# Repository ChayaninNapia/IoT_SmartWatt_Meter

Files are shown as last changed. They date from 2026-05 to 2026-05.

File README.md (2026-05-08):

# IoT Smart Watt Meter

An ESP32-based bicycle watt meter project for FRA503. The system combines an
MPU6050 IMU, HX711 strain-gauge force sensing, an SH1106 OLED, four physical
buttons, a passive buzzer, BLE telemetry, and a Flutter mobile app for ride
display, GPS, recording, history, and cloud sync.

## Project Status

Current integration focus:

- Full-system ESP32 firmware for bench and field testing.
- BLE telemetry between ESP32 and Flutter.
- Gyroscope-based crank cadence estimation.
- HX711 raw capture and calibration workflow.
- Flutter app screens for live power, device connection, map, history, and ride
  detail.

Hardware evidence has confirmed the OLED, buzzer, four active-high buttons,
MPU6050 raw/gyro readings, and several IMU/OLED/buzzer/button integration
tests. HX711 calibration is still the key remaining measurement step before
force and wattage should be treated as final.

## Repository Layout

```text
electrical/
  unit_test/                         Single-component ESP32 test sketches
  integration_test/
    smart_watt_meter_full_system/    Main full-system ESP32 firmware
  experiment/
    hx711_calibration/               HX711 capture logger and ESP32 collector
    imu_cadence_validation/          Gyro cadence validation firmware

software/
  smart_watt_meter/                  Flutter mobile app
  firmware/smart_watt_meter_mock/    Mock telemetry firmware
  docs/                              Software/report documents
  ui design/                         UI mockups and design references

data/
  hx711_calibration/                 Captured calibration CSV data

data_analysis/                       Analysis scripts and notebooks
diagrams/                            System and wiring diagrams
images/                              Project images
proposal/, report/, draft/           Report and proposal materials
research_papers/                     Reference papers
```

## Hardware Summary

Target board:

```text
ESP32 NodeMCU-32S / ESP-32S Kit
Arduino board target: ESP32 Dev Module
CLI FQBN: esp32:esp32:esp32
```

Current GPIO map:

| Function | GPIO | Notes |
| --- | ---: | --- |
| HX711 DOUT | 32 | Digital input |
| HX711 SCK | 33 | Digital output |
| I2C SDA | 21 | Shared by OLED and MPU6050 |
| I2C SCL | 22 | Shared by OLED and MPU6050 |
| Button 1 | 25 | Active-high, `INPUT_PULLDOWN` |
| Button 2 | 26 | Active-high, `INPUT_PULLDOWN` |
| Button 3 | 27 | Active-high, `INPUT_PULLDOWN` |
| Button 4 | 14 | Active-high, `INPUT_PULLDOWN` |
| Passive buzzer | 13 | Tone/PWM output |

Button 5 / GPIO16 is not part of the current system.

OLED:

- 1.3 inch I2C OLED
- SH1106-compatible
- Address `0x3C`
- Driver: `Adafruit_SH110X` / `Adafruit_SH1106G`

## Main ESP32 Firmware

Full-system firmware:

```text
electrical/integration_test/smart_watt_meter_full_system/smart_watt_meter_full_system.ino
```

It combines:

- SH1106 OLED screen UI.
- MPU6050 cadence estimation.
- HX711 raw/tare/force path.
- Four active-high buttons.
- Passive buzzer feedback.
- BLE telemetry for the Flutter app.

BLE configuration:

```text
Device name: ESP32_PowerMeter_01
Service UUID: 12345678-1234-1234-1234-123456789012
Telemetry notify UUID: 12345678-1234-1234-1234-123456789013
App status / command write UUID: 12345678-1234-1234-1234-123456789014
```

Example telemetry packet:

```json
{"v":1,"type":"telemetry","seq":128,"tMs":128420,"powerW":245.3,"cadenceRpm":82.1,"forceN":34.20,"torqueNm":5.81,"omegaRadS":8.600,"hxRaw":29120,"hxTared":true,"imuOk":true,"hxOk":true,"calOk":true}
```

Example app status write:

```json
{"type":"appStatus","gpsOk":true,"recording":true}
```

Example app commands:

```json
{"type":"command","cmd":"tare"}
{"type":"command","cmd":"gyroBias"}
{"type":"command","cmd":"axisCal"}
```

## Arduino Compile Checks

The Arduino IDE bundled CLI is used because `arduino-cli` is not expected to be
on the system `PATH`.

CLI path on the development machine:

```powershell
& 'C:\Users\Acer\AppData\Local\Programs\Arduino IDE\resources\app\lib\backend\resources\arduino-cli.exe' version
```

Compile the full-system firmware:

```powershell
& 'C:\Users\Acer\AppData\Local\Programs\Arduino IDE\resources\app\lib\backend\resources\arduino-cli.exe' compile --fqbn esp32:esp32:esp32 .\electrical\integration_test\smart_watt_meter_full_system
```

Compile the IMU cadence experiment:

```powershell
& 'C:\Users\Acer\AppData\Local\Programs\Arduino IDE\resources\app\lib\backend\resources\arduino-cli.exe' compile --fqbn esp32:esp32:esp32 .\electrical\experiment\imu_cadence_validation
```

Compile the HX711 trial collector:

```powershell
& 'C:\Users\Acer\AppData\Local\Programs\Arduino IDE\resources\app\lib\backend\resources\arduino-cli.exe' compile --fqbn esp32:esp32:esp32 .\electrical\experiment\hx711_calibration\esp32_hx711_trial_collector
```

Compile success only proves the firmware builds. Hardware tests must still be
verified with serial logs, OLED output, buzzer response, photos, videos, or
recorded experiment data.

## HX711 Calibration Workflow

Calibration tools:

```text
electrical/experiment/hx711_calibration/
```

Important files:

```text
hx711_calibration_logger.py
esp32_hx711_trial_collector/esp32_hx711_trial_collector.ino
```

Install Python dependencies:

```powershell
pip install pyserial matplotlib
```

Run the logger:

```powershell
python electrical\experiment\hx711_calibration\hx711_calibration_logger.py
```

The workflow captures 100 valid HX711 samples per trial into:

```text
data/hx711_calibration/<loading-or-unloading>/m<mass>/trial<trial>/hx711_capture.csv
```

Current calibration range is `0-4 kg`. Use loading and unloading trials to
check scale, residual error, and hysteresis before treating force in newtons as
calibrated.

## IMU Cadence Validation

Cadence validation sketch:

```text
electrical/experiment/imu_cadence_validation/imu_cadence_validation.ino
```

The method:

1. Measure gyro bias while stationary.
2. Subtract bias from gyro readings.
3. Estimate the crank rotation axis in the IMU frame.
4. Project the gyro vector onto that axis.
5. Convert angular speed to RPM.
6. Compare IMU RPM against video-derived reference RPM.

The full-system firmware starts with this default crank unit vector unless the
axis calibration is refreshed:

```text
ux = -0.074
uy =  0.995
uz =  0.065
```

## Flutter App

App folder:

```text
software/smart_watt_meter/
```

Key dependencies:

- `flutter_blue_plus` for BLE.
- `geolocator` and `permission_handler` for phone GPS.
- `flutter_map` and `latlong2` for maps.
- `firebase_core`, `cloud_firestore`, and `firebase_auth` for cloud sync.
- `provider` for app state.

Run from the app folder:

```powershell
cd software\smart_watt_meter
flutter pub get
flutter run
```

Run Flutter tests:

```powershell
cd software\smart_watt_meter
flutter test
```

The app connects to `ESP32_PowerMeter_01`, subscribes to telemetry notify
packets, writes phone GPS/recording status back to the ESP32, records ride
samples, and displays ride history/details.

## Git Notes

Large generated folders are intentionally ignored:

```text
build/
**/.gradle_user_home/
.dart_tool/
**/.claude/
```

Do not commit local build caches, Gradle user-home downloads, Flutter build
outputs, or local tool settings. The repository should keep source code,
firmware sketches, documentation, calibration data, and intentional design
artifacts only.

## Safety Notes

- Keep the crank/IMU still during gyro bias calibration.
- Remove all load before HX711 tare.
- Do not use GPIO12 for a button in this ESP32 project because it is a boot
  strapping pin.
- Do not mark hardware tests as passed from compile success alone.
- Treat wattage as experimental until HX711 calibration has been validated with
  known loads.

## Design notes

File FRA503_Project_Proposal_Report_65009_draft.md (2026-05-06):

<!-- Generated from report/FRA503 Project Proposal Report 65009.docx. Embedded images were intentionally omitted and replaced with labels. -->

[Figure omitted: image1.jpg from original DOCX]

รายงาน

วิชา FRA503

Technopeuneurship in IoT Industry

สถาบันวิทยาการหุ่นยนต์ภาคสนาม มหาวิทยาลัยเทคโนโลยีพระจอมเกล้าธนบุรี

โครงการ

การพัฒนาระบบจักรยานอัจฉริยะสำหรับตรวจวัดและบันทึกข้อมูลการปั่นผ่าน BLE และคลาวด์

ชื่อกลุ่ม 5

ผู้ดำเนินงาน

นายชญานิน นาเพีย รหัสนักศึกษา 65340500009

# บทที่ 1 บทนำ

## ที่มาและความสำคัญ

จักรยานเป็นพาหนะที่ไม่ก่อมลพิษ มีความคล่องตัว และสามารถใช้งานได้หลากหลายรูปแบบ ทั้งการเดินทางในชีวิตประจำวัน การออกกำลังกาย และการฝึกซ้อมเพื่อการแข่งขัน ผู้ใช้แต่ละกลุ่มจึงมีเป้าหมายในการปั่นและความต้องการข้อมูลที่แตกต่างกันออกไป โดยกลุ่มผู้ใช้จักรยานเป็นพาหนะในชีวิตประจำวันให้ความสำคัญกับความสะดวกและความคุ้มค่า กลุ่มผู้ใช้เพื่อการออกกำลังกายสนใจความหนักเบาของการปั่นและการพัฒนาสมรรถภาพร่างกาย ขณะที่กลุ่มผู้ใช้เพื่อการฝึกซ้อมและการแข่งขันต้องการข้อมูลเชิงลึกเพื่อใช้ควบคุมการซ้อมและวางแผนการใช้พลังงานบนเส้นทางจริง

ในการติดตามประสิทธิภาพการปั่น นักปั่นมักใช้ตัวชี้วัดหลายชนิด เช่น ระยะทาง เวลา ความเร็ว อัตราการเต้นหัวใจเฉลี่ย และกำลังปั่น อย่างไรก็ตาม หากต้องการประเมินความหนักเบาของการออกแรงอย่างใกล้เคียงการใช้พลังงานจริง กำลังปั่นซึ่งหมายถึงอัตราการส่งพลังงานจากผู้ปั่นผ่านขาจานเข้าสู่ระบบขับเคลื่อนของจักรยาน เป็นตัวชี้วัดที่สำคัญกว่าความเร็วหรืออัตราการเต้นหัวใจเพียงอย่างเดียว เนื่องจากความเร็วได้รับผลจากแรงลมและความลาดชันของเส้นทาง ส่วนอัตราการเต้นหัวใจขึ้นกับสภาพร่างกาย การพักผ่อน อุณหภูมิ และโภชนาการ ดังนั้นการทราบค่ากำลังปั่นจึงช่วยให้นักปั่นควบคุมการออกแรงของตนเองและวางแผนการซ้อมได้แม่นยำขึ้นแม้เครื่องวัดกำลังปั่นจะมีประโยชน์สูง แต่ผลิตภัณฑ์เชิงพาณิชย์ในตลาดยังมีราคาค่อนข้างสูง และหลายแบบมีข้อจำกัดเรื่องความเข้ากันได้กับชิ้นส่วนเดิมของจักรยาน ทำให้ผู้ใช้ทั่วไปและผู้พัฒนาต้นแบบเข้าถึงได้ไม่ง่าย

จากแนวคิดดังกล่าว โครงงานนี้จึงเสนอการพัฒนาระบบจักรยานอัจฉริยะในรูปแบบระบบเสริมที่ติดตั้งบนขาจานข้างเดียว โดยไม่ต้องเปลี่ยนโครงสร้างหลักของจักรยาน ใช้สเตรนเกจและไอเอ็มยูเป็นแหล่งข้อมูลหลัก ใช้ ESP32 เป็นหน่วยประมวลผลบนตัวจักรยานเพื่อคำนวณค่าเบื้องต้นและสื่อสารผ่าน Bluetooth Low Energy (BLE) ไปยังแอปมือถือ จากนั้นแอปมือถือจะทำหน้าที่แสดงผล บันทึกเส้นทาง และส่งข้อมูลขึ้นฐานข้อมูลบนคลาวด์ผ่านเครือข่ายมือถือ

## ศึกษาคู่แข่งที่มีขาย

โดยทั่วไป watt meter ในจักรยานสามารถแบ่งได้เป็น 4 ประเภทหลัก ได้แก่ pedal based, crank arm based, spider based และ crankset based ซึ่งแต่ละประเภทมีจุดเด่นและข้อจำกัดต่างกัน เช่น pedal based ติดตั้งง่ายแต่ขึ้นกับระบบบันไดเดิม, spider based วัดกำลังรวมได้ดีแต่ซับซ้อนด้านการติดตั้ง, และ crankset based มีความครบในตัวแต่มีราคาสูงที่สุด

ตารางต่อไปนี้สรุปข้อดีและข้อจำกัดของ watt meter แต่ละประเภทในมุมที่เกี่ยวข้องกับการพัฒนาต้นแบบ

| ประเภท | ข้อดี | ข้อจำกัด |
| --- | --- | --- |
| Pedal based | ติดตั้งและย้ายข้ามจักรยานได้ค่อนข้างง่าย, วัดแรงจากตำแหน่งที่ผู้ปั่นออกแรงโดยตรง | ต้องเลือกให้เข้ากับระบบบันไดและรองเท้า, โครงสร้างเชิงกลซับซ้อนและรับแรงกระแทกสูง |
| Crank arm based | ต้นทุนต่ำกว่า spider/crankset based, เหมาะกับแนวคิด add-on, ติดตั้ง strain gauge และพัฒนาต้นแบบได้ง่าย | ส่วนใหญ่เป็นการวัดแบบข้างเดียว, ความแม่นยำขึ้นกับการติดตั้งและการคาลิเบรต |
| Spider based | วัดกำลังรวมของระบบขาจานได้ดี, เหมาะกับการใช้งานเชิงสมรรถนะ | การติดตั้งซับซ้อน, ขึ้นกับความเข้ากันได้ของชุดขาจาน, ต้นทุนสูง |
| Crankset based | รวมระบบไว้ในชุดเดียว, ความเรียบร้อยและความพร้อมใช้งานสูง | ราคาสูงที่สุด, ต้องเปลี่ยนชุดขาจานทั้งชุด, ไม่เหมาะกับแนวคิดต้นแบบต้นทุนต่ำ |

สำหรับโครงงานนี้เลือกโฟกัส crank arm based เนื่องจากสอดคล้องกับแนวคิด add-on system ที่ติดตั้งบน crank arm เดิมได้โดยไม่ต้องเปลี่ยนชิ้นส่วนหลักของจักรยาน มีต้นทุนต่ำกว่า spider/crankset based และเหมาะกับการพัฒนาต้นแบบด้วย strain gauge + IMU + ESP32 มากที่สุด ดังนั้นตารางเปรียบเทียบด้านล่างจึงคัดข้อมูลเฉพาะ crank arm power meter หรือ left crank arm power meter เพื่อให้เทียบกับแนวทางของโครงงานได้ตรงที่สุด

[Figure omitted: image2.png from original DOCX]

จากตัวอย่าง 10 รายการที่คัดให้เหลือเฉพาะ crank arm พบว่าช่วงราคาที่พบบ่อยอยู่ราว 11,800-19,040 บาท และมีบางรุ่นนำเข้าที่สูงขึ้นไปถึง 25,783 บาท ภาพนี้ทำให้เห็นชัดว่าต่อให้เปรียบเทียบเฉพาะกลุ่ม crank arm ซึ่งเป็นกลุ่มที่ใกล้กับโครงงานที่สุด ราคาตลาดส่วยใหญ่ค่อนข้างสูง

ข้อแตกต่างของโครงงานนี้เมื่อเทียบกับสินค้าในตลาดคือ:

เป็น add-on sensing system ที่ติดตั้งบน crank arm เดิม โดยไม่ต้องเปลี่ยนโครงสร้างหลักของจักรยาน

ใช้ ESP32 + smartphone + cloud backup เป็นสถาปัตยกรรมหลัก จึงเน้นความง่ายในการทดลองและการต่อยอดข้อมูล

เปิดโอกาสให้ปรับแต่งเฟิร์มแวร์ ตรรกะของแอป และลำดับการไหลของข้อมูลได้เอง

มีข้อจำกัดด้านความแม่นยำและความทนทานมากกว่าระบบ commercial จึงต้องพึ่งการติดตั้งและ calibration ที่เหมาะสม

## วัตถุประสงค์ของผลิตภัณฑ์/สิ่งที่ผลิตภัณฑ์ทำได้ (functions)

พัฒนาต้นแบบระบบที่สามารถอ่านค่ากำลังปั่นจาก crank arm แบบ add-on โดยไม่มีการถอดเปลี่ยนชิ้นส่วนหลักของจักรยาน

พัฒนาให้ ESP32 สามารถรับข้อมูลจาก strain gauge และ IMU แล้วสื่อสารข้อมูลผ่าน BLE ไปยังแอปมือถือ

พัฒนาแอปมือถือบนระบบ Android สำหรับแสดงผลค่ากำลังปั่นและข้อมูลการปั่นแบบเรียลไทม์

พัฒนาแอปมือถือให้สามารถส่งข้อมูลขึ้น cloud database เพื่อเก็บประวัติการปั่นได้

ศึกษาความเป็นไปได้เชิงเทคนิค ข้อจำกัด และความเสี่ยงของระบบก่อนพัฒนาต้นแบบจริง

## ขอบเขตที่ผลิตภัณฑ์ทำได้

ชิ้นงานเป็น single crank arm based

โครงจักรยานที่ใช้ในการทดลองเป็น โครงจักรยานพับ รุ่น Fika Frappe

ESP32 จะถูกติดตั้งที่จักรยาน และใช้พลังงานจาก แบตเตอรี่

การประมาณ power ใช้แหล่งข้อมูลจาก strain gauge และ IMU

แอพพลิเคชันบนระบบ android

## ประโยชน์ที่คาดว่าจะได้รับ เช่นจากธุรกิจ

ได้ต้นแบบ IoT สำหรับการวัดกำลังปั่นที่ต้นทุนต่ำและต่อยอดได้

ได้สถาปัตยกรรมที่เชื่อม อุปกรณ์ -> แอปมือถือ -> คลาวด์ อย่างครบวงจร

ได้ฐานข้อมูลประวัติการปั่นที่นำไปใช้วิเคราะห์พฤติกรรมการปั่นภายหลังได้

ช่วยลดต้นทุนในการศึกษาหลักการของ power meter เทียบกับการซื้อผลิตภัณฑ์เชิงพาณิชย์โดยตรง

เหมาะเป็นฐานต่อยอดสำหรับงานวิจัย งานเรียน หรือการพัฒนาผลิตภัณฑ์ sports analytics

## 1.6 แผนดำเนินงาน

| หน้าที่ | เมษายน 2569 | เมษายน 2569 | พฤษภาคม 2569 | พฤษภาคม 2569 |
| --- | --- | --- | --- | --- |
|  | w3 | w4 | w1 | w2 |
| สั่งของ |  |  |  |  |
| พัฒนาแอพพลิเคชั่นมือถือ |  |  |  |  |
| ออกแบบการทดลอง |  |  |  |  |
| ออกแบบ วงจรไฟฟ้า + ทดสอบ |  |  |  |  |
| ออกแบบ กล่องคอนโทรล |  |  |  |  |
| ติดตั้ง strain gauge + calibrate |  |  |  |  |
| รวมระบบ |  |  |  |  |
| ทำการทดลอง และสรุปผล |  |  |  |  |
| ทำงานงานฉบับสมบูรณ์ |  |  |  |  |

# บทที่ 2 วิธีการดำเนินการ

สถาปัตยกรรมของระบบแบ่งเป็น 5 ชั้น ได้แก่ device layer, communication layer, service layer, application layer และ cloud layer โดยฝั่งจักรยานจะมีเซนเซอร์และวงจรอ่านสัญญาณติดตั้งบน crank arm เดิม ข้อมูลจาก strain gauge และ gyroscope จะถูกส่งเข้า ESP32 เพื่อทำ edge power estimation แล้วแพ็กเป็น telemetry packet ส่งผ่าน BLE ไปยังแอปมือถือ หลังจากนั้นมือถือจะรับข้อมูลกำลังปั่น ควบคู่กับการอ่านตำแหน่งจาก GPS เพื่อนำมาสร้างเส้นทาง แสดงผลบนแผนที่ และจัดเก็บเป็นชุดข้อมูลการปั่นก่อนส่งขึ้น Firebase ผ่านเครือข่าย 4G / 5G

[Figure omitted: image3.png from original DOCX]

รูปที่ ... แสดงแผนผังระบบของโครงงานนี้

## 2.1 การออกแบบฮาร์ดแวร์

## 2.2 การออกแบบทางไฟฟ้า

## 2.3 การพัฒนาเฟิร์มแวร์

## 2.4 การพัฒนาแอปพลิเคชันบนมือถือ

## 2.5 การจัดเก็บข้อมูลบนคลาวด์

# บทที่ 3 วิธีการทดสอบ ผลและวิเคราะห์การทดสอบ

## รายการการทดลองและแผนทดสอบ

ส่วนนี้เป็นแผนการทดลองสำหรับพัฒนาระบบวัดกำลังปั่นจักรยาน โดยเรียงจากการคาลิเบรตแรง ไปจนถึงการรวมระบบและตรวจสอบค่ากำลังไฟฟ้าเชิงกลที่คำนวณได้

### ภาพรวมรายการทดลอง

| หมายเลข | ชื่อการทดลอง | เป้าหมายหลัก | สถานะ |
| --- | --- | --- | --- |
| 3.1 | คาลิเบรต Strain Gauge ด้วย HX711 แบบหลายจุด (0–4 kg) | หา `zero_offset` และ `counts_per_newton` เพื่อแปลง raw ADC เป็นแรงหน่วย N ตรวจ linearity, residual และ hysteresis | กำลังดำเนินการ |
| 3.2 | ทดสอบความถูกต้องของการประมาณ Cadence จาก Gyroscope | หา gyro bias และแกนหมุนจริงของขาจานในเฟรมของ IMU จากนั้น project ค่า gyro ทั้งสามแกนไปยังแกน crank ด้วย dot product เพื่อคำนวณ RPM และเปรียบเทียบกับค่า RPM อ้างอิงจากวิดีโอ | รอทำหลัง 3.1 |
| 3.3 | ทดสอบความทนทานทางกล | ตรวจสอบว่าจุดยึดกล่องควบคุม, จุดติด strain gauge บน crank arm และสายเชื่อมต่อไม่หลุดเสียหายระหว่างปั่นจริง | รอทำหลัง 3.2 |
| 3.4 | ทดสอบระบบรวม (Full Integration Test) | ตรวจสอบว่า ESP32, BLE, mobile app และ cloud ทำงานร่วมกันได้ขณะปั่นจริง | รอทำหลัง 3.3 |

## 3.1 การทดลองคาลิเบรต HX711 แบบหลายจุดด้วยน้ำหนักอ้างอิง 0-4 kg

### วัตถุประสงค์

การทดลองนี้มีเป้าหมายเพื่อคาลิเบรตวงจร HX711 ที่ต่อกับวงจร strain gauge / load cell bridge โดยแปลงค่าดิบจาก ADC ของ HX711 ให้กลายเป็นแรงหน่วยนิวตัน (N) สำหรับนำไปใช้ในระบบวัดกำลังปั่นจักรยานต่อไป การทดลองนี้ใช้การคาลิเบรตแบบหลายจุดจากน้ำหนักอ้างอิง 0-4 kg เพื่อให้ตรวจสอบความเป็นเส้นตรงของระบบได้ดีกว่าการใช้จุดน้ำหนักเดียว โดยจุด 5 kg ถูกตัดออกจากการทดลองชุดนี้ด้วยเหตุผลด้านความปลอดภัย เพราะจักรยานมีแนวโน้มเคลื่อนที่ไปข้างหน้าเมื่อไม่มีคนจับยึด

ค่าหลักที่ต้องหาในการทดลองนี้คือ:

- `zero_raw_average` หรือ `zero_offset`: ค่า ADC เฉลี่ยตอนยังไม่มีแรงกระทำ ใช้เป็นค่าศูนย์อ้างอิง
- `counts_per_newton`: จำนวน ADC count ที่เปลี่ยนไปต่อแรง 1 N ใช้เป็นค่าคาลิเบรตหรือ calibration divisor
- `linearity`: ความเป็นเส้นตรงระหว่างแรงอ้างอิงกับค่า `delta_raw`
- `residual` หรือ error: ค่าคลาดเคลื่อนของแต่ละจุดเมื่อเทียบกับเส้น calibration
- `hysteresis`: ความต่างของค่าที่อ่านได้ระหว่างช่วงเพิ่มน้ำหนักและช่วงลดน้ำหนัก

หลังจากได้ค่า calibration แล้ว สามารถประมาณแรงจากค่า ADC ได้ด้วยสมการ:

```text
force_N = (raw_average - zero_raw_average) / counts_per_newton
```

### การจัดชุดทดลอง

#### อุปกรณ์ที่ใช้

- ESP32 NodeMCU-32S / ESP-32S Kit
- โมดูล HX711 load cell amplifier / 24-bit ADC
- วงจร strain gauge / Wheatstone bridge / load cell circuit ที่ต่อเข้ากับ HX711 แล้ว
- น้ำหนักอ้างอิง 1 kg จำนวน 2 ถุง
- น้ำหนักอ้างอิง 2 kg จำนวน 2 ถุง
- สาย jumper และไฟเลี้ยง 3.3V จาก ESP32
- Serial Monitor ที่ baud rate `115200`

#### การต่อสาย

| HX711 Pin | จุดต่อในระบบ | หน้าที่ |
| --- | --- | --- |
| `VCC` / `DVDD` | `3.3V` | ให้ระดับ logic ตรงกับ ESP32 |
| `GND` | `GND` | ground ร่วมของระบบ |
| `DOUT` | `GPIO32` | ขาส่งข้อมูลดิจิทัลจาก HX711 |
| `SCK` / `PD_SCK` | `GPIO33` | ขา clock สำหรับอ่านข้อมูลจาก HX711 |
| `E+`, `E-`, `A+`, `A-` | วงจร strain gauge / bridge circuit | ไฟเลี้ยง bridge และสัญญาณ differential input |

> หมายเหตุ: โปรเจกต์นี้ใช้ไฟเลี้ยง/logic ของ HX711 ที่ 3.3V เพื่อให้สัญญาณ digital output จาก HX711 ปลอดภัยกับ GPIO ของ ESP32 firmware กำหนด gain เป็น `64` (Channel A, gain 64) ซึ่งให้ sensitivity สูงกว่า gain 32

#### น้ำหนักอ้างอิงและระดับโหลด

ในการทดลองนี้มีน้ำหนักอ้างอิง 1 kg จำนวน 2 ถุง และ 2 kg จำนวน 2 ถุง แต่ขอบเขตการเก็บข้อมูลจริงจำกัดที่ 0-4 kg เพื่อความปลอดภัย โดยแรงอ้างอิงคำนวณจาก:

```text
known_force_N = mass_kg * g
g = 9.80665 m/s^2
```

ตารางระดับโหลดหลักที่ใช้สำหรับ calibration:

| Level | ชุดน้ำหนัก | Mass kg | Known force N | หมายเหตุ |
| --- | --- | ---: | ---: | --- |
| 0 | ไม่มีน้ำหนัก | 0 | 0.00000 | ใช้สำหรับ tare / zero |
| 1 | 1 kg | 1 | 9.80665 | จุดต่ำสุดหลัง zero |
| 2 | 2 kg | 2 | 19.61330 | ใช้ถุง 2 kg หรือ 1 kg + 1 kg เพื่อเทียบซ้ำ |
| 3 | 1 kg + 2 kg | 3 | 29.41995 | จุดกลาง |
| 4 | 2 kg + 2 kg หรือ 1 kg + 1 kg + 2 kg | 4 | 39.22660 | ใช้เทียบ repeatability ของมวลรวมเท่ากัน |

### ขั้นตอนการทดลอง

การทดลองนี้ใช้โปรแกรม 2 ส่วนทำงานร่วมกัน: ESP32 firmware ทำหน้าที่เก็บ raw sample และ Python logger ทำหน้าที่ส่งคำสั่ง ระบุ mass/phase และบันทึก CSV อัตโนมัติ

**การเตรียมก่อนเริ่ม**

1. อัพโหลด `esp32_hx711_trial_collector.ino` ลง ESP32
2. ปิด Arduino Serial Monitor ทุกหน้าต่าง (Python logger จะใช้ COM3 แทน)
3. รัน Python logger บน PC: `python hx711_calibration_logger.py`
4. Logger จะถามให้ tare → ตรวจสอบว่าไม่มีโหลดบน strain gauge แล้วกด Enter (หรือพิมพ์ `skip` ถ้า tare ไปแล้ว)

**ลำดับการเก็บข้อมูล (loading)**

5. รอค่านิ่ง แล้วพิมพ์ `loading m0 t1` → logger ส่งคำสั่ง `c` ให้ ESP32 เก็บ 100 samples อัตโนมัติ บันทึกลง `data/hx711_calibration/loading/m0/trial01/hx711_capture.csv`
6. วางน้ำหนัก 1 kg รอนิ่ง แล้วพิมพ์ `loading m1 t1`
7. วางน้ำหนัก 2 kg รอนิ่ง แล้วพิมพ์ `loading m2 t1`
8. วางน้ำหนัก 3 kg รอนิ่ง แล้วพิมพ์ `loading m3 t1`
9. วางน้ำหนัก 4 kg รอนิ่ง แล้วพิมพ์ `loading m4 t1`

**ลำดับการเก็บข้อมูล (unloading)**

10. เอาน้ำหนักออกเหลือ 3 kg รอนิ่ง แล้วพิมพ์ `unloading m3 t1`
11. ลดน้ำหนักต่อเนื่อง พิมพ์ `unloading m2 t1`, `unloading m1 t1`, `unloading m0 t1` ตามลำดับ
    (จุด 4 kg ของ unloading ใช้ข้อมูลร่วมกับ `loading m4` ไม่ต้องเก็บซ้ำ)

**ทำซ้ำและวิเคราะห์**

12. ทำซ้ำอย่างน้อย 3 รอบ โดยใช้ suffix `t2`, `t3` ในคำสั่ง และส่ง `tare` ก่อนแต่ละรอบ
13. ใช้คำสั่ง `monitor` หรือ `mon` เพื่อดู live graph ของ `raw` และ `delta_raw` ระหว่างรอค่านิ่ง
14. หลังเก็บครบ นำไฟล์ CSV ทั้งหมดจาก `data/hx711_calibration/` มาคำนวณ `raw_avg` และ `delta_raw_avg` ต่อ trial แล้ว fit เส้นตรง `delta_raw_avg vs known_force_N` เพื่อหา `counts_per_newton`
15. เปรียบเทียบค่า loading กับ unloading เพื่อประเมิน hysteresis
16. ตรวจค่า `unloading m0` ว่า `delta_raw_avg` ใกล้ 0 หรือไม่ เพื่อประเมิน zero drift

### หลักการแปลงค่า ADC เป็นแรง

ค่าที่ HX711 อ่านได้เป็น raw ADC count ยังไม่ใช่แรงโดยตรง จึงต้องหาความสัมพันธ์ระหว่าง raw count กับแรงที่รู้ค่าจริง สำหรับการคาลิเบรตแบบหลายจุด จะ fit สมการเส้นตรง:

```text
zero_raw_average = raw เฉลี่ยตอนยังไม่มีโหลด
known_force_N = mass_kg * 9.80665
delta_raw = raw_average - zero_raw_average
delta_raw = m * known_force_N + b
counts_per_newton = m
force_N = (raw_average - zero_raw_average - b) / counts_per_newton
```

ถ้า fit แล้วค่า `b` ใกล้ 0 แสดงว่าการ tare ทำงานดี และสามารถใช้สมการอย่างง่ายได้:

```text
force_N = (raw_average - zero_raw_average) / counts_per_newton
```

ถ้า `counts_per_newton` มีค่าเป็นลบ ไม่ได้แปลว่าวงจรผิดเสมอไป โดยทั่วไปหมายถึงทิศทางแรงหรือการต่อสาย bridge ทำให้ค่า ADC ลดลงเมื่อมีแรงกระทำ สูตรยังใช้ได้ตามเดิม และสามารถกลับเครื่องหมายใน firmware ภายหลังได้ หากต้องการให้ทิศทางแรงที่เลือกแสดงเป็นค่าบวก

### ผลที่ต้องบันทึกและกราฟที่ต้องพล็อต

แต่ละ trial จะได้ไฟล์ CSV 1 ไฟล์ที่มี 100 rows บันทึกลงโฟลเดอร์ `data/hx711_calibration/{phase}/m{mass}/trial{N}/hx711_capture.csv` โดยอัตโนมัติ

CSV columns ของแต่ละ trial:

| คอลัมน์ | ความหมาย |
| --- | --- |
| `sample_idx` | ลำดับ sample (1–100) |
| `time_ms` | เวลา millis() บน ESP32 |
| `raw` | raw ADC count จาก HX711 |
| `delta_raw` | `raw - zero_raw` (คำนวณโดย firmware) |
| `zero_raw` | ค่า zero ที่ tare ไว้ (คงที่ตลอด trial) |

ตารางสรุปสำหรับรายงาน (คำนวณจาก CSV หลังเก็บข้อมูล):

| run | phase | mass_kg | known_force_N | raw_avg | delta_raw_avg | measured_force_N | error_N | note |
| ---: | --- | ---: | ---: | ---: | ---: | ---: | ---: | --- |
| 1 | loading | 0 | 0.00000 |  |  |  |  | tare |
| 1 | loading | 1 | 9.80665 |  |  |  |  | 1 kg |
| 1 | loading | 2 | 19.61330 |  |  |  |  | 2 kg หรือ 1+1 kg |
| 1 | loading | 3 | 29.41995 |  |  |  |  | 1+2 kg |
| 1 | loading | 4 | 39.22660 |  |  |  |  | 2+2 kg หรือ 1+1+2 kg |
| 1 | unloading | 3 | 29.41995 |  |  |  |  | ลดโหลด |
| 1 | unloading | 2 | 19.61330 |  |  |  |  | ลดโหลด |
| 1 | unloading | 1 | 9.80665 |  |  |  |  | ลดโหลด |
| 1 | unloading | 0 | 0.00000 |  |  |  |  | ตรวจ zero drift |

> `raw_avg` และ `delta_raw_avg` คือค่าเฉลี่ยของ 100 samples จาก CSV trial นั้น; `measured_force_N` คำนวณจาก `delta_raw_avg / counts_per_newton` หลัง fit calibration แล้ว

กราฟที่ควรพล็อต:

1. **Calibration curve**
   - แกน x: `known_force_N`
   - แกน y: `delta_raw`
   - fit เส้นตรง `delta_raw = m * known_force_N + b`
   - รายงานค่า `m`, `b` และถ้าคำนวณได้ให้รายงาน `R^2`

2. **Force time series**
   - แกน x: `time_s` หรือ sample index
   - แกน y: `measured_force_N`
   - ใช้ดู noise, settling time และการกลับศูนย์หลังเอาน้ำหนักออก

3. **Residual / error plot**
   - แกน x: `known_force_N`
   - แกน y: `error_N = measured_force_N - known_force_N`
   - ใช้ดูว่าจุดไหนคลาดจากเส้น calibration มากผิดปกติ

4. **Loading vs unloading plot**
   - พล็อต `delta_raw` หรือ `measured_force_N` แยกสีระหว่าง loading และ unloading
   - ใช้ประเมิน hysteresis ของชุด strain gauge / โครงสร้างติดตั้ง

### โปรแกรมที่ใช้ในการทดลอง

การทดลองนี้ใช้โปรแกรม 2 ส่วน:

**1. ESP32 Firmware**
ไฟล์: `electrical/experiment/hx711_calibration/esp32_hx711_trial_collector/esp32_hx711_trial_collector.ino`

| คำสั่ง (Serial) | หน้าที่ |
| --- | --- |
| `h` | แสดง help |
| `s` | แสดงสถานะ tare ปัจจุบัน |
| `t` | tare ไม่มีโหลด เก็บ `zero_raw` จาก 20 samples |
| `c` | เก็บ 100 raw samples แล้วส่งออก Serial ในรูปแบบ `BEGIN_TRIAL ... END_TRIAL` |
| `r1` / `r0` | เปิด/ปิด live report รูปแบบ `LIVE,time_ms,raw,delta_raw` |

**2. Python Logger**
ไฟล์: `electrical/experiment/hx711_calibration/hx711_calibration_logger.py`

| คำสั่ง (terminal) | หน้าที่ |
| --- | --- |
| `loading m0 t1` | เก็บ trial loading mass 0 kg ครั้งที่ 1 บันทึกลง `data/.../loading/m0/trial01/` |
| `unloading m3 t1` | เก็บ trial unloading mass 3 kg ครั้งที่ 1 |
| `l m4 t2` | shortcut ของ `loading m4 t2` |
| `u m2 t1` | shortcut ของ `unloading m2 t1` |
| `monitor` / `mon` | เปิด live graph แสดง `raw` และ `delta_raw` แบบ real-time |
| `tare` | ส่งคำสั่ง tare ไปยัง ESP32 |
| `status` / `s` | ดึงสถานะ tare จาก ESP32 |
| `q` | ออกจากโปรแกรม |

Reference library: HX711 Arduino Library by bogde (https://github.com/bogde/HX711)

## 3.2 การทดลองทดสอบความถูกต้องของการประมาณ Cadence จาก Gyroscope

### 3.2.1 วัตถุประสงค์

- ประเมินความถูกต้องของการคำนวณ cadence หรือรอบต่อนาทีของขาจานจาก MPU6050 gyroscope
- หา gyro bias ของแต่ละแกนก่อนคำนวณค่า angular velocity ที่ใช้งานจริง
- หาแกนหมุนของขาจานในเฟรมของ IMU จากข้อมูล gyroscope ทั้งสามแกน
- เปรียบเทียบค่า `RPM_IMU` กับค่า `RPM_ref` ที่คำนวณจากวิดีโออ้างอิง

### 3.2.2 ตัวแปรที่ใช้ในการทดลอง

- `gyro_x`, `gyro_y`, `gyro_z`: ค่า gyroscope ดิบจาก MPU6050
- `bias_x`, `bias_y`, `bias_z`: ค่า bias ขณะ IMU หยุดนิ่ง
- `g_x`, `g_y`, `g_z`: ค่า gyroscope หลังชดเชย bias
- `u_crank`: เวกเตอร์หนึ่งหน่วยตามแกนหมุนจริงของขาจานในเฟรม IMU
- `omega_crank`: อัตราการหมุนของขาจานหลัง project ลงแกน crank
- `RPM_IMU`: ค่า RPM ที่คำนวณจาก IMU
- `RPM_ref`: ค่า RPM อ้างอิงจากวิดีโอ
- `Error(%)`: ค่าความคลาดเคลื่อนของ `RPM_IMU` เทียบกับ `RPM_ref`

### 3.2.3 อุปกรณ์ที่ใช้

- ESP32 NodeMCU-32S / ESP-32S Kit
- MPU6050 ที่ติดตั้งบน crank arm
- จักรยานหรือชุดขาจานที่สามารถหมุนได้อย่างต่อเนื่อง
- คอมพิวเตอร์สำหรับบันทึก Serial log หรือ CSV
- โทรศัพท์หรือกล้องสำหรับบันทึกวิดีโออ้างอิง
- โปรแกรมสำหรับดูเวลาในวิดีโอแบบ frame-by-frame

### 3.2.4 หลักการคำนวณ

ชดเชย gyro bias ของแต่ละแกน:

```text
g_x = gyro_x - bias_x
g_y = gyro_y - bias_y
g_z = gyro_z - bias_z
```

กำหนดเวกเตอร์ gyroscope หลังชดเชย bias:

```text
g = [g_x, g_y, g_z]
```

หาเวกเตอร์ทิศทางการหมุนเฉลี่ยของขาจาน:

```text
v = [mean(g_x), mean(g_y), mean(g_z)]
```

แปลงเป็นเวกเตอร์หนึ่งหน่วย:

```text
u_crank = v / ||v||
```

project ค่า gyroscope ลงบนแกน crank ด้วย dot product:

```text
omega_crank = g · u_crank
omega_crank = g_x u_x + g_y u_y + g_z u_z
```

คำนวณ RPM จาก IMU:

```text
RPM_IMU = |omega_crank| × 60 / 360
```

คำนวณ RPM อ้างอิงจากวิดีโอ:

```text
RPM_ref = (N_rev / delta_t) × 60
```

คำนวณความคลาดเคลื่อน:

```text
Error(%) = |RPM_IMU_avg - RPM_ref| / RPM_ref × 100
```

### 3.2.5 ขั้นตอนการทดลอง

1. คาลิเบรตค่า Gyro Bias
   - วางจักรยานหรือ crank arm ให้นิ่ง
   - บันทึกค่า `gyro_x`, `gyro_y`, `gyro_z` อย่างน้อย 5 วินาที
   - คำนวณค่าเฉลี่ยเป็น `bias_x`, `bias_y`, `bias_z`

2. หาแกนหมุนของขาจานในเฟรมของ IMU
   - หมุนขาจานด้วยความเร็วคงที่ระดับปานกลาง
   - บันทึกข้อมูล `g_x`, `g_y`, `g_z`
   - คำนวณ `v` และ normalize เป็น `u_crank`

3. บันทึกข้อมูล IMU ระหว่างการหมุนขาจาน
   - บันทึก Serial log หรือ CSV พร้อม timestamp
   - เก็บข้อมูลอย่างน้อย 10 รอบต่อ trial
   - คำนวณ `omega_crank` และ `RPM_IMU` ของแต่ละช่วงเวลา

4. คำนวณค่า RPM อ้างอิงจากวิดีโอ
   - ถ่ายวิดีโอให้เห็นตำแหน่งขาจานครบทุก trial
   - นับจำนวนรอบ `N_rev` จากวิดีโอ
   - วัดเวลา `delta_t` สำหรับ 10 รอบ และคำนวณ `RPM_ref`

5. เปรียบเทียบค่า RPM จาก IMU กับค่าอ้างอิง
   - คำนวณ `RPM_IMU_avg` ของแต่ละ trial
   - คำนวณ `Error(%)`
   - สรุปว่า IMU ให้ค่า cadence อยู่ในเกณฑ์ที่ยอมรับได้หรือไม่

### 3.2.6 รูปแบบการทดลอง

| Trial | รูปแบบการหมุน | จำนวนรอบอ้างอิง |
| ---: | --- | ---: |
| 1 | หมุนช้า | 10 รอบ |
| 2 | หมุนความเร็วปกติ | 10 รอบ |
| 3 | หมุนเร็วขึ้น | 10 รอบ |

### 3.2.7 ตารางบันทึกผลการทดลอง

| Trial | รูปแบบการหมุน | N_rev | delta_t (s) | RPM_ref | RPM_IMU_avg | Error(%) | หมายเหตุ |
| ---: | --- | ---: | ---: | ---: | ---: | ---: | --- |
| 1 | หมุนช้า | 10 | | | | | |
| 2 | หมุนความเร็วปกติ | 10 | | | | | |
| 3 | หมุนเร็วขึ้น | 10 | | | | | |

### 3.2.8 เกณฑ์การประเมินผล

- สามารถคำนวณ `bias_x`, `bias_y`, `bias_z` ได้จากข้อมูลขณะหยุดนิ่ง
- สามารถหา `u_crank` จากข้อมูล gyroscope ทั้งสามแกนได้
- ค่า `RPM_IMU` เปลี่ยนตามระดับความเร็วการหมุนในแต่ละ trial อย่างสมเหตุสมผล
- ค่า `Error(%)` เฉลี่ยไม่เกิน 10% เมื่อเทียบกับ `RPM_ref`
- มี Serial log, CSV หรือวิดีโออ้างอิงประกอบผลการทดลอง

---
## 3.3 การทดลองทดสอบความทนทานทางกล

### วัตถุประสงค์

ตรวจสอบว่าการยึดติดของกล่องควบคุม ESP32, จุดติด strain gauge บน crank arm และสายเชื่อมต่อทั้งหมด ไม่หลุด ไม่เสียหาย และไม่กระทบการอ่านค่าเซนเซอร์เมื่อผ่านการสั่นสะเทือนและแรงที่เกิดจากการปั่นจักรยานจริง

### การจัดชุดทดลอง

#### อุปกรณ์ที่ใช้

- ระบบ ESP32 พร้อม HX711, MPU6050, OLED และ buzzer ครบชุด ติดตั้งบนจักรยาน Fika Frappe
- OLED หรือ Serial Monitor สำหรับยืนยันค่าเซนเซอร์ตลอดการทดสอบ
- กล้องหรือโทรศัพท์สำหรับถ่ายรูปก่อน–หลัง
- นาฬิกาจับเวลา

### ขั้นตอนการทดลอง

1. ตรวจสอบและถ่ายรูปสภาพจุดยึดทั้งหมดก่อนเริ่มทดสอบ
2. เปิดระบบ ยืนยันว่า HX711 และ MPU6050 อ่านค่าได้ปกติผ่าน OLED
3. ปั่นจักรยานแบบ stationary (ยกล้อหลัง) หรือปั่นบนพื้นราบ นาน 10 นาที ด้วยความพยายามปกติ
4. ระหว่างปั่น สังเกต OLED ว่าค่าเซนเซอร์แสดงผลสม่ำเสมอ ไม่มีค่าหายหรือกระโดดผิดปกติ
5. หลังปั่นครบ 10 นาที หยุดและตรวจสภาพจุดยึด สายไฟ และจุดติด strain gauge
6. ถ่ายรูปสภาพหลังทดสอบเปรียบเทียบกับก่อน

### ผลที่ต้องบันทึก

| รายการ | ผลก่อนทดสอบ | ผลหลังทดสอบ | หมายเหตุ |
| --- | --- | --- | --- |
| จุดยึดกล่องควบคุม | | | ยึดแน่น / หลวม / หลุด |
| จุดติด strain gauge บน crank arm | | | ปกติ / หลุด / เสียหาย |
| สายเชื่อมต่อ HX711 และ MPU6050 | | | ปกติ / หลวม / หลุด |
| ค่า sensor ระหว่างปั่น | | | ต่อเนื่อง / ขาดหาย / กระโดด |

### เกณฑ์ผ่าน

- ไม่มีชิ้นส่วนใดหลุดหรือเสียหายหลังปั่น 10 นาที
- ค่า sensor อ่านได้ต่อเนื่องตลอดการทดสอบ ไม่มีการขาดหายหรือค่ากระโดดผิดปกติ

---

## 3.4 การทดลองทดสอบระบบรวม (Full Integration Test)

### วัตถุประสงค์

ตรวจสอบว่าระบบทั้งหมดทำงานร่วมกันได้ขณะปั่นจักรยานจริง ได้แก่ ESP32 รับข้อมูล HX711 และ MPU6050 แล้วคำนวณค่ากำลังปั่น (W) ส่งผ่าน BLE ไปยัง mobile app ที่แสดงผล real-time และส่งข้อมูลขึ้น Firebase ผ่านเครือข่ายมือถือ

### การจัดชุดทดลอง

#### อุปกรณ์ที่ใช้

- ระบบ ESP32 + HX711 + MPU6050 พร้อม firmware คำนวณ power และ BLE advertising
- โทรศัพท์ Android พร้อม mobile app ที่เชื่อมต่อ BLE และส่งข้อมูล Firebase
- เครือข่ายมือถือ 4G/5G
- Firebase console สำหรับยืนยันข้อมูล

#### ค่าที่ firmware ต้องส่งใน BLE packet

| ฟิลด์ | หน่วย | หมายเหตุ |
| --- | --- | --- |
| `force_N` | N | จาก HX711 หลัง calibration |
| `omega_rad_s` | rad/s | จาก MPU6050 แกนที่เลือก |
| `power_W` | W | `torque_Nm × omega_rad_s`; `torque_Nm = force_N × crank_length_m` |
| `timestamp_ms` | ms | `millis()` บน ESP32 |

### ขั้นตอนการทดลอง

1. เปิดระบบ ESP32 และยืนยัน BLE advertising ด้วย Serial Monitor
2. เปิด mobile app เชื่อมต่อ BLE กับ ESP32
3. ปั่นจักรยานบนพื้นราบนาน 5 นาที สังเกตหน้าจอ app ว่าค่า power (W) อัพเดทสม่ำเสมอ
4. บันทึก latency โดยประมาณระหว่างการเคลื่อนไหวจริงกับการอัพเดทบนหน้าจอ app
5. หลังปั่น เข้า Firebase console ตรวจว่ามีข้อมูล session บันทึกครบตลอด 5 นาที
6. บันทึกความสมบูรณ์ของข้อมูลและช่วงที่ขาดหาย (ถ้ามี)

### ผลที่ต้องบันทึก

| ตัวชี้วัด | ค่าที่ได้ | เกณฑ์ |
| --- | --- | --- |
| BLE latency (ประมาณ) | | < 500 ms |
| ค่า power ขณะปั่น (W) | | แสดงผลสม่ำเสมอ ไม่ติดค้างหรือค่าผิดปกติ |
| ข้อมูล session ใน Firebase | | ครบ ไม่มีช่วงขาดหาย |
| สถานะ BLE connection | | ไม่หลุดตลอด 5 นาที |

### เกณฑ์ผ่าน

- Mobile app รับค่า power และแสดงผล real-time ได้ตลอดการทดสอบ 5 นาที
- ข้อมูล session ขึ้น Firebase ครบและไม่มีช่วงขาดหาย
- BLE ไม่หลุดระหว่างปั่น

---

อธิบายวิธีการทดสอบ

อธิบายผล และวิเคราะห์การทดสอบ ต้นแบบ (prototype) ที่ได้พัฒนามา

# บทที่ 4 สรุปผลการดำเนินงาน และข้อเสนอแนะ การปรับปรุงต้นแบบ

# บทที่ 5 งบการเงิน

| ลำดับ | รายการ | จำนวน | ราคาต่อหน่วย | ราคา (บาท) |
| --- | --- | --- | --- | --- |
| 1 | Strain gauge | 4 | 12.5 | 50 |
| 2 | HX711 | 1 | 50 | 50 |
| 3 | MPU6050 | 1 | 90 | 90 |
| 4 | Battery 7.4v | 1 | 350 | 350 |
| 5 | PLA-plus-filament | 1 | 500 | 500 |
| 6 | Wiring / connectors /switch | 1 | 300 | 300 |
| 7 | step-down-5V | 1 | 40 | 40 |
| 8 | กาว epoxy | 1 | 120 | 120 |
|  |  |  |  |  |
| รวม |  |  |  | 1500 |

# อ้างอิง

Steve Jarvis, “Homemade Power Meter,” available: https://imateapot.dev/homemade-power-meter/ (accessed 2026-04-09).

YouTube reference provided by project owner, available: https://www.youtube.com/watch?v=CRa9djnZRu0&t=11s (accessed 2026-04-09).

Espressif, “Bluetooth API - ESP32,” available: https://docs.espressif.com/projects/esp-idf/en/stable/esp32/api-reference/bluetooth/index.html (accessed 2026-04-09).

Espressif, “GATT Server API - ESP32,” available: https://docs.espressif.com/projects/esp-idf/en/stable/esp32/api-reference/bluetooth/esp_gatts.html (accessed 2026-04-09).

Firebase, “Add Firebase to your Flutter app,” available: https://firebase.google.com/docs/flutter/setup (accessed 2026-04-09).

Firebase, “Cloud Firestore,” available: https://firebase.google.com/products/firestore (accessed 2026-04-09).

Firebase, “Access data offline,” available: https://firebase.google.com/docs/firestore/manage-data/enable-offline (accessed 2026-04-09).

Firebase, “Get started with Cloud Firestore Security Rules,” available: https://firebase.google.com/docs/firestore/security/get-started (accessed 2026-04-09).

Stages Cycling, “Single Sided Power Meters,” available: https://stagescycling.com/en_global/product/power-meters/single-sided (accessed 2026-04-09).

Shimano, “FC-R9200-P,” available: https://bike.shimano.com/pl-PL/products/components/pdp.P-FC-R9200-P.html (accessed 2026-04-09).

CCACHE, “4iiii Precision 3+ Power Meter Left Arm Only - 105 R7100,” available: https://ccache.cc/products/4iiii-precision-3-power-meter-left-arm-only-105-r7100 (accessed 2026-04-09).

Priceza, “ขาวัตต์ Stages Ultegra R8000,” available: https://www.priceza.com/s/ราคา/ขาวัตต์stages-ultegra-r8000 (accessed 2026-04-09).

Ubuy Thailand, “4iiii Precision 3 Powermeter Ride Ready - Left-Side,” available: https://www.ubuy.co.th/th/product/IEUP1SR62-4iiii-precision-3-powermeter-ride-ready-left-side-ant-performance-meter-for-outdoor-indoor-cycling-measures-watts-cadence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 (accessed 2026-04-09).

CCACHE, “Shimano Dura-Ace FC-R9200-P Left Hand Crank Arm Unit,” available: https://ccache.cc/products/shimano-dura-ace-fc-r9200-p-left-hand-crank-arm-powermeter (accessed 2026-04-09).

Priceza, “ขาจาน 105,” available: https://www.priceza.com/s/ราคา/ขาจาน105 (accessed 2026-04-09).

CCACHE, “4iiii Precision 3+ Power Meter Left Arm Only - GRX 810/820,” available: https://ccache.cc/products/4iiii-precision-3-power-meter-left-arm-only-grx-810-820 (accessed 2026-04-09).

CCACHE, “4iiii Precision 3+ Power Meter Left Arm Only - Ultegra R8100,” available: https://ccache.cc/products/4iiii-precision-3-power-meter-left-arm-only-ultegra-r8100 (accessed 2026-04-09).

CCACHE, “4iiii Precision 3+ Power Meter Left Arm Only - Dura-Ace R9200,” available: https://ccache.cc/products/4iiii-precision-3-power-meter-left-arm-only-dura-ace-r9200 (accessed 2026-04-09).

CCACHE, “Shimano FC-R8100-P Left Hand Crank Arm Unit 172.5mm,” available: https://ccache.cc/products/shimano-fc-r8100-p-left-hand-crank-arm-unit-172-5mm (accessed 2026-04-09).

---

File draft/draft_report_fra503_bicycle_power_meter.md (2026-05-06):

# ดราฟรายงานโครงงาน FRA503

## ข้อมูลทั่วไป

- ชื่อโครงการ: การพัฒนาระบบจักรยานอัจฉริยะสำหรับตรวจวัดและบันทึกข้อมูลการปั่นผ่าน BLE และคลาวด์
- รายวิชา: FRA503 Technopeuneurship in IoT Industry
- สถานะเอกสาร: Draft Proposal / Draft Report Structure
- ชื่อกลุ่ม: กลุ่ม 2
- ผู้ดำเนินงาน: นายชญานิน นาเพีย รหัสนักศึกษา 65340500009

> หมายเหตุ: เอกสารฉบับนี้เป็นดราฟเพื่อเตรียมการส่ง proposal และ presentation ตามโครงรายงาน 5 บทของรายวิชา จึงตั้งใจไม่ใส่ผลทดลองปลอม แต่จะระบุเป็นแผนการทดสอบและ expected evidence แทน

---

## บทที่ 1 บทนำ

### 1.1 ที่มาและความสำคัญ

จักรยานเป็นพาหนะที่ไม่ก่อมลพิษ มีความคล่องตัว และสามารถใช้งานได้หลากหลายรูปแบบ ทั้งการเดินทางในชีวิตประจำวัน การออกกำลังกาย และการฝึกซ้อมเพื่อการแข่งขัน ผู้ใช้แต่ละกลุ่มจึงมีเป้าหมายในการปั่นและความต้องการข้อมูลที่แตกต่างกันออกไป โดยกลุ่มผู้ใช้จักรยานเป็นพาหนะในชีวิตประจำวันให้ความสำคัญกับความสะดวกและความคุ้มค่า กลุ่มผู้ใช้เพื่อการออกกำลังกายสนใจความหนักเบาของการปั่นและการพัฒนาสมรรถภาพร่างกาย ขณะที่กลุ่มผู้ใช้เพื่อการฝึกซ้อมและการแข่งขันต้องการข้อมูลเชิงลึกเพื่อใช้ควบคุมการซ้อมและวางแผนการใช้พลังงานบนเส้นทางจริง

ในการติดตามประสิทธิภาพการปั่น นักปั่นมักใช้ตัวชี้วัดหลายชนิด เช่น ระยะทาง เวลา ความเร็ว อัตราการเต้นหัวใจเฉลี่ย และกำลังปั่น อย่างไรก็ตาม หากต้องการประเมินความหนักเบาของการออกแรงอย่างใกล้เคียงการใช้พลังงานจริง กำลังปั่นซึ่งหมายถึงอัตราการส่งพลังงานจากผู้ปั่นผ่านขาจานเข้าสู่ระบบขับเคลื่อนของจักรยาน เป็นตัวชี้วัดที่สำคัญกว่าความเร็วหรืออัตราการเต้นหัวใจเพียงอย่างเดียว เนื่องจากความเร็วได้รับผลจากแรงลมและความลาดชันของเส้นทาง ส่วนอัตราการเต้นหัวใจขึ้นกับสภาพร่างกาย การพักผ่อน อุณหภูมิ และโภชนาการ ดังนั้นการทราบค่ากำลังปั่นจึงช่วยให้นักปั่นควบคุมการออกแรงของตนเองและวางแผนการซ้อมได้แม่นยำขึ้น

แม้เครื่องวัดกำลังปั่นจะมีประโยชน์สูง แต่ผลิตภัณฑ์เชิงพาณิชย์ในตลาดยังมีราคาค่อนข้างสูง และหลายแบบมีข้อจำกัดเรื่องความเข้ากันได้กับชิ้นส่วนเดิมของจักรยาน ทำให้ผู้ใช้ทั่วไปและผู้พัฒนาต้นแบบเข้าถึงได้ไม่ง่าย

จากแนวคิดดังกล่าว โครงงานนี้จึงเสนอการพัฒนาระบบจักรยานอัจฉริยะในรูปแบบระบบเสริมที่ติดตั้งบนขาจานข้างเดียว โดยไม่ต้องเปลี่ยนโครงสร้างหลักของจักรยาน ใช้สเตรนเกจและไอเอ็มยูเป็นแหล่งข้อมูลหลัก ใช้ `ESP32` เป็นหน่วยประมวลผลบนตัวจักรยานเพื่อคำนวณค่าเบื้องต้นและสื่อสารผ่าน `Bluetooth Low Energy (BLE)` ไปยังแอปมือถือ จากนั้นแอปมือถือจะทำหน้าที่แสดงผล บันทึกเส้นทาง และส่งข้อมูลขึ้นฐานข้อมูลบนคลาวด์ผ่านเครือข่ายมือถือ

กลุ่มเป้าหมายของระบบในโครงงานนี้แบ่งออกเป็น 3 กลุ่มหลัก ได้แก่

- ผู้ใช้จักรยานเป็นพาหนะในชีวิตประจำวัน
- ผู้ใช้จักรยานเพื่อการออกกำลังกายและดูแลสุขภาพ
- ผู้ใช้จักรยานเพื่อการฝึกซ้อมและการแข่งขัน

### 1.2 ศึกษาคู่แข่งที่มีขาย

โดยทั่วไป watt meter ในจักรยานสามารถแบ่งได้เป็น 4 ประเภทหลัก ได้แก่ `pedal based`, `crank arm based`, `spider based` และ `crankset based` ซึ่งแต่ละประเภทมีจุดเด่นและข้อจำกัดต่างกัน เช่น pedal based ติดตั้งง่ายแต่ขึ้นกับระบบบันไดเดิม, spider based วัดกำลังรวมได้ดีแต่ซับซ้อนด้านการติดตั้ง, และ crankset based มีความครบในตัวแต่มีราคาสูงที่สุด

ตารางต่อไปนี้สรุปข้อดีและข้อจำกัดของ watt meter แต่ละประเภทในมุมที่เกี่ยวข้องกับการพัฒนาต้นแบบ

| ประเภท | ข้อดี | ข้อจำกัด |
| --- | --- | --- |
| Pedal based | ติดตั้งและย้ายข้ามจักรยานได้ค่อนข้างง่าย, วัดแรงจากตำแหน่งที่ผู้ปั่นออกแรงโดยตรง | ต้องเลือกให้เข้ากับระบบบันไดและรองเท้า, โครงสร้างเชิงกลซับซ้อนและรับแรงกระแทกสูง |
| Crank arm based | ต้นทุนต่ำกว่า spider/crankset based, เหมาะกับแนวคิด add-on, ติดตั้ง strain gauge และพัฒนาต้นแบบได้ง่าย | ส่วนใหญ่เป็นการวัดแบบข้างเดียว, ความแม่นยำขึ้นกับการติดตั้งและการคาลิเบรต |
| Spider based | วัดกำลังรวมของระบบขาจานได้ดี, เหมาะกับการใช้งานเชิงสมรรถนะ | การติดตั้งซับซ้อน, ขึ้นกับความเข้ากันได้ของชุดขาจาน, ต้นทุนสูง |
| Crankset based | รวมระบบไว้ในชุดเดียว, ความเรียบร้อยและความพร้อมใช้งานสูง | ราคาสูงที่สุด, ต้องเปลี่ยนชุดขาจานทั้งชุด, ไม่เหมาะกับแนวคิดต้นแบบต้นทุนต่ำ |

สำหรับโครงงานนี้เลือกโฟกัส `crank arm based` เนื่องจากสอดคล้องกับแนวคิด `add-on system` ที่ติดตั้งบน crank arm เดิมได้โดยไม่ต้องเปลี่ยนชิ้นส่วนหลักของจักรยาน มีต้นทุนต่ำกว่า spider/crankset based และเหมาะกับการพัฒนาต้นแบบด้วย `strain gauge + IMU + ESP32` มากที่สุด ดังนั้นตารางเปรียบเทียบด้านล่างจึงคัดข้อมูลเฉพาะ `crank arm power meter` หรือ `left crank arm power meter` เพื่อให้เทียบกับแนวทางของโครงงานได้ตรงที่สุด

| สินค้า | ประเภท | จุดเด่น | ข้อจำกัด | ราคาอ้างอิง |
| --- | --- | --- | --- | ---: |
| Stages Gen 3 Shimano Ultegra R8000 Left Crank Arm | Left crank arm | single-sided ติดตั้งง่าย ใช้กับระบบ Shimano ที่มีอยู่ได้, Accuracy ±1.5%, ANT+/BLE [9][12] | วัดขาเดียวแล้วคูณสอง จึงอาจคลาดเคลื่อนหากแรงซ้าย/ขวาไม่สมดุล | 13,100 บาท [12] |
| 4iiii Precision 3+ Left Arm Only | Left crank arm | เบา, Accuracy ±1%, Battery life สูง, ANT+/BLE, Apple Find My [11] | ยังเป็น single-sided และต้องเลือก arm ให้ตรงรุ่นขาจานเดิม | ประมาณ 14,000-19,354 บาท [11][13] |
| Shimano FC-R9200-P Left Hand Crank Arm Unit | Left crank arm unit | เป็นส่วนหนึ่งของ ecosystem Shimano power meter, ระบุข้อมูล left/right และ compensation เชิงพาณิชย์ [10][14] | ราคาสูง และเป็นชิ้นส่วนเฉพาะรุ่นมากกว่าแนวทาง add-on | ประมาณ 19,040 บาท [14] |

ข้อแตกต่างของโครงงานนี้เมื่อเทียบกับสินค้าในตลาดคือ

- เป็น `add-on sensing system` ที่ติดตั้งบน crank arm เดิม โดยไม่ต้องเปลี่ยนโครงสร้างหลักของจักรยาน
- ใช้ `ESP32 + smartphone + cloud backup` เป็นสถาปัตยกรรมหลัก จึงเน้นความง่ายในการทดลองและการต่อยอดข้อมูล
- เปิดโอกาสให้ปรับแต่งเฟิร์มแวร์ ตรรกะของแอป และลำดับการไหลของข้อมูลได้เอง
- มีข้อจำกัดด้านความแม่นยำและความทนทานมากกว่าระบบ commercial จึงต้องพึ่งการติดตั้งและ calibration ที่เหมาะสม

#### ตัวอย่างข้อมูลราคากลุ่ม crank arm ที่ใช้สร้างกราฟเปรียบเทียบ

| สินค้าในตัวอย่างราคา | ประเภท | ราคา (บาท) | แหล่งข้อมูล |
| --- | --- | ---: | --- |
| Stages Gen 3 Shimano 105 R7000 Left Crank Arm | Left crank arm | 11,800 | Priceza [15] |
| Stages Gen 3 Shimano Ultegra R8000 Left Crank Arm | Left crank arm | 13,100 | Priceza [12] |
| Stages Gen 3 Shimano Ultegra R8100 Left Crank Arm | Left crank arm | 15,224 | Priceza [15] |
| 4iiii Precision 3 Powermeter Ride Ready Left-Side | Left crank arm | 25,783 | Ubuy Thailand [13] |
| 4iiii Precision 3+ 105 R7100 Left Arm Only | Left crank arm | 14,000 | CCACHE, แปลงจาก AUD เป็น THB [11] |
| 4iiii Precision 3+ GRX 810/820 Left Arm Only | Left crank arm | 15,120 | CCACHE, แปลงจาก AUD เป็น THB [16] |
| 4iiii Precision 3+ Ultegra R8100 Left Arm Only | Left crank arm | 16,397 | CCACHE, แปลงจาก AUD เป็น THB [17] |
| 4iiii Precision 3+ Dura-Ace R9200 Left Arm Only | Left crank arm | 17,920 | CCACHE, แปลงจาก AUD เป็น THB [18] |
| Shimano FC-R8100-P Left Hand Crank Arm Unit | Left crank arm unit | 18,390 | CCACHE, แปลงจาก AUD เป็น THB [19] |
| Shimano FC-R9200-P Left Hand Crank Arm Unit | Left crank arm unit | 19,040 | CCACHE, แปลงจาก AUD เป็น THB [14] |

กราฟราคา crank arm power meter

จากตัวอย่าง 10 รายการที่คัดให้เหลือเฉพาะ `crank arm` พบว่าช่วงราคาที่พบบ่อยอยู่ราว `11,800-19,040 บาท` และมีบางรุ่นนำเข้าที่สูงขึ้นไปถึง `25,783 บาท` ภาพนี้ทำให้เห็นชัดว่าต่อให้เปรียบเทียบเฉพาะกลุ่ม crank arm ซึ่งเป็นกลุ่มที่ใกล้กับโครงงานที่สุด ราคาตลาดก็ยังสูงกว่าต้นทุนต้นแบบหลายเท่า

> หมายเหตุด้านข้อมูลราคา: เนื่องจากตลาดไทยสำหรับ `left crank arm power meter` มีรายการที่อ้างอิงได้ไม่มาก จึงใช้ `Priceza/Ubuy Thailand` เป็นหลัก และเสริมด้วย retailer quote ของรุ่น `left arm only` จาก CCACHE แล้วแปลงเป็นบาทที่อัตราประมาณ `1 AUD ≈ 22.4 THB` เพื่อให้เห็นช่วงราคาในกราฟอย่างต่อเนื่อง

### 1.3 วัตถุประสงค์ของผลิตภัณฑ์/สิ่งที่ผลิตภัณฑ์ทำได้ (functions)

- พัฒนาต้นแบบระบบที่สามารถอ่านค่ากำลังปั่นจาก crank arm แบบ add-on โดยไม่มีการถอดเปลี่ยนชิ้นส่วนหลักของจักรยาน
- พัฒนาให้ `ESP32` สามารถรับข้อมูลจาก `strain gauge` และ `IMU` แล้วสื่อสารข้อมูลผ่าน BLE ไปยังแอปมือถือ
- พัฒนาแอปมือถือบนระบบ `Android` สำหรับแสดงผลค่ากำลังปั่นและข้อมูลการปั่นแบบเรียลไทม์
- พัฒนาแอปมือถือให้สามารถส่งข้อมูลขึ้น `cloud database` เพื่อเก็บประวัติการปั่นได้
- ศึกษาความเป็นไปได้เชิงเทคนิค ข้อจำกัด และความเสี่ยงของระบบก่อนพัฒนาต้นแบบจริง

### 1.4 ขอบเขตที่ผลิตภัณฑ์ทำได้

ขอบเขตของงานที่ตั้งใจทำในต้นแบบนี้ประกอบด้วย

- ติดตั้ง strain gauge บน crank arm เดิมเพื่อวัดสัญญาณ deformation
- ใช้ภาคอ่านสัญญาณ เช่น HX711 หรือ ADC front-end เพื่ออ่านค่า strain
- ชิ้นงานเป็น `single crank arm based system`
- โครงจักรยานที่ใช้ในการทดลองเป็นโครงจักรยานพับ รุ่น Fika Frappe
- ใช้ IMU บน crank arm เพื่อวัด `angular velocity`
- ใช้ `ESP32` ที่ติดตั้งบนจักรยานและใช้พลังงานจากแบตเตอรี่เป็นหน่วยประมวลผลหลัก
- ใช้แอปพลิเคชันบนระบบ `Android` เป็นอุปกรณ์ปลายทางของระบบ เพื่อรับข้อมูลผ่าน BLE, แสดงผล, ติดตามเส้นทาง และสำรองข้อมูลขึ้นคลาวด์
- ใช้ `Flutter`, `Google Maps Flutter SDK`, `Geolocator` และ `Firebase` เป็นชุดเทคโนโลยีหลัก
- วางแผนทดสอบเรื่อง calibration, ความเสถียรของการเชื่อมต่อ BLE, การติดตามเส้นทาง, การส่งข้อมูลจากมือถือขึ้นคลาวด์ และการเปรียบเทียบแนวโน้มกับอุปกรณ์อ้างอิง

นอกขอบเขตของ draft นี้

- ไม่รับประกันความแม่นยำระดับ commercial grade
- ยังไม่รวมการผลิต enclosure กันน้ำระดับใช้งานจริงระยะยาว
- ยังไม่รวม dual-sided measurement
- ยังไม่รวมการทำ ANT+ profile เต็มรูปแบบ

### 1.5 ประโยชน์ที่คาดว่าจะได้รับ เช่นจากธุรกิจ

- ได้ต้นแบบ IoT สำหรับการวัดกำลังปั่นที่ต้นทุนต่ำและต่อยอดได้
- ได้สถาปัตยกรรมที่เชื่อม `อุปกรณ์ -> แอปมือถือ -> คลาวด์` อย่างครบวงจร
- ได้ฐานข้อมูลประวัติการปั่นที่นำไปใช้วิเคราะห์พฤติกรรมการปั่นภายหลังได้
- ช่วยลดต้นทุนในการศึกษาหลักการของ power meter เทียบกับการซื้อผลิตภัณฑ์เชิงพาณิชย์โดยตรง
- เหมาะเป็นฐานต่อยอดสำหรับงานวิจัย งานเรียน หรือการพัฒนาผลิตภัณฑ์ sports analytics

### 1.6 แผนดำเนินงาน

แผนดำเนินงานเบื้องต้นของโครงงานครอบคลุมการออกแบบระบบ การพัฒนาฮาร์ดแวร์ การพัฒนาเฟิร์มแวร์บน ESP32 การพัฒนาแอปพลิเคชันบนมือถือ การเชื่อมต่อคลาวด์ และการทดสอบรวมระบบ โดยมีรายละเอียดเชิงเวลาอยู่ในไฟล์แผนงาน [gantt_chart_apr_may_2026_daily_columns.csv](gantt_chart_apr_may_2026_daily_columns.csv) และสามารถสรุปช่วงงานหลักได้ดังนี้

| ช่วงเวลา | งานหลัก |
| --- | --- |
| เมษายน สัปดาห์ที่ 1-2 | ศึกษาความต้องการ ออกแบบสถาปัตยกรรม และวางแผนรายการอุปกรณ์ |
| เมษายน สัปดาห์ที่ 3-4 | ประกอบวงจรเซนเซอร์ ติดตั้ง strain gauge และพัฒนาเฟิร์มแวร์บน ESP32 |
| พฤษภาคม สัปดาห์ที่ 1-2 | พัฒนาแอปมือถือ การติดตามเส้นทาง และการเชื่อมต่อกับแผนที่ |
| พฤษภาคม สัปดาห์ที่ 3 | เชื่อมต่อ Firebase และทดสอบการส่งข้อมูลขึ้นคลาวด์ |
| พฤษภาคม สัปดาห์ที่ 4 | ทดสอบรวมระบบ ปรับแก้ และจัดทำรายงาน/สไลด์นำเสนอ |

---

## บทที่ 2 วิธีการดำเนินการ

### 2.1 แนวคิดการออกแบบและ System Overview

สถาปัตยกรรมของระบบแบ่งเป็น 5 ชั้น ได้แก่ `device layer`, `communication layer`, `service layer`, `application layer` และ `cloud layer` โดยฝั่งจักรยานจะมีเซนเซอร์และวงจรอ่านสัญญาณติดตั้งบน crank arm เดิม ข้อมูลจาก `strain gauge` และ `gyroscope` จะถูกส่งเข้า `ESP32` เพื่อทำ edge power estimation แล้วแพ็กเป็น telemetry packet ส่งผ่าน BLE ไปยังแอปมือถือ หลังจากนั้นมือถือจะรับข้อมูลกำลังปั่น ควบคู่กับการอ่านตำแหน่งจาก GPS เพื่อนำมาสร้างเส้นทาง แสดงผลบนแผนที่ และจัดเก็บเป็นชุดข้อมูลการปั่นก่อนส่งขึ้น Firebase ผ่านเครือข่าย `4G / 5G`

แนวทางนี้มีข้อดีคือ

- ฝั่งจักรยานยังคงความเรียบง่ายและสอดคล้องกับแนวคิด add-on บน crank arm เดิม
- `ESP32` ทำการประมวลผลเบื้องต้นบนอุปกรณ์ จึงลดภาระการคำนวณฝั่งแอปและทำให้ค่ากำลังปั่นพร้อมใช้ทันที
- `BLE` เหมาะกับการเชื่อมต่อระยะสั้นระหว่างจักรยานกับมือถือและกินพลังงานต่ำ [3][4]
- `Flutter + Firebase` ช่วยให้ทำต้นแบบที่มีมือถือเป็นศูนย์กลางและการสำรองข้อมูลขึ้นคลาวด์ได้รวดเร็ว [5][6]
- `Cloud Firestore` รองรับการเก็บข้อมูลแบบออฟไลน์และการซิงก์เมื่อกลับมาออนไลน์ได้ [7]

### 2.2 การเลือกใช้องค์ประกอบของระบบ

| ส่วนของระบบ | องค์ประกอบที่เลือก | เหตุผลเชิงเทคนิค |
| --- | --- | --- |
| Force sensing | Strain gauge บน crank arm เดิม | สอดคล้องกับแนวคิด add-on และไม่ต้องเปลี่ยน drivetrain ทั้งชุด |
| Analog front-end | HX711 หรือ front-end ADC สำหรับ load cell/strain | อ่านสัญญาณระดับเล็กจาก strain gauge ได้ในต้นทุนต่ำ |
| Angular velocity sensing | IMU บน crank arm | ใช้วัดความเร็วเชิงมุมของ crank arm โดยไม่ต้องเพิ่ม sensor อีกชนิด |
| MCU | ESP32 | มี BLE ในตัว ราคาไม่สูง และ ecosystem แข็งแรง |
| Mobile app | Flutter (Android-first) | พัฒนาโปรแกรมฝั่งมือถือได้รวดเร็วและสอดคล้องกับขอบเขตปัจจุบันของโครงงาน |
| Cloud | Firebase Auth + Cloud Firestore | มี SDK ฝั่งมือถือชัดเจน ใช้งานแบบต้นแบบได้เร็ว และมีกฎความปลอดภัยของข้อมูล |

### 2.3 System Diagram

ด้านล่างคือแผนภาพระบบฉบับเดียวกับไฟล์ [bicycle_power_meter_system_diagram.mmd](bicycle_power_meter_system_diagram.mmd)

```mermaid
flowchart LR
  subgraph D["Device Layer"]
    sg["Strain Gauge on Crank Arm"]
    bridge["Wheatstone Bridge"]
    adc["HX711 / ADC Front-End"]
    gyro["Gyroscope (IMU)"]
    esp["ESP32"]
    calib["Calibration"]
    compute["Edge Power Estimation<br/>torque estimate + angular velocity + power estimate"]

    sg -- "strain deformation" --> bridge
    bridge -- "analog bridge signal" --> adc
    adc -- "digital strain reading" --> calib
    calib -- "calibrated strain data" --> esp
    gyro -- "angular velocity signal" --> esp
    esp -- "processed sensor data" --> compute
  end

  subgraph C1["Communication Layer"]
    ble["BLE GAP + GATT"]
    packet["BLE Telemetry Packet<br/>timestamp + strain + angular velocity + power"]
    mobileNet["4G / 5G Mobile Network"]
    https["HTTPS / Firebase API"]
    compute --> packet --> ble
  end

  subgraph S["Service Layer"]
    direction TB

    subgraph SR["Route Service"]
      direction TB
      geo["Flutter Geolocator Plugin<br/>readPositionStream() + location permission"]
      route["Route Tracking<br/>read latitude + longitude + timestamp"]
      polyline["Build Route Polyline<br/>prepare route for map display"]
      mapsdk["Google Maps Flutter SDK<br/>render route on map"]
    end

    subgraph SD["Ride Data Service"]
      direction TB
      powerStore["Power Samples<br/>timestamp + power"]
      merge["Merge Route Data and Power Data<br/>match by timestamp"]
      session["Ride Session Data"]
    end

    subgraph SC["Cloud Sync Service"]
      direction TB
      upload["Firebase Flutter SDK"]
    end
  end

  subgraph A["Application Layer"]
    app["Flutter Mobile App"]
    phoneGps["Phone GPS Sensor"]
    dashboard["Live Dashboard"]
    mapView["Map View"]
    history["Ride History"]
  end

  subgraph CL["Cloud Layer"]
    cloud["Firebase Cloud Firestore"]
  end

  ble -- "BLE notifications" --> app
  app -- "decode telemetry packet" --> powerStore

  phoneGps -- "GPS signal" --> geo
  geo -- "position stream" --> route
  route -- "route points" --> polyline
  polyline -- "polyline data" --> mapsdk
  route -- "route data" --> merge
  powerStore -- "power samples" --> merge
  merge -- "combined session data" --> session

  session -- "ride metrics" --> dashboard
  mapsdk -- "map widget" --> mapView
  session -- "route + power overlay" --> mapView
  session -- "session history" --> history

  session -- "upload request" --> upload
  upload -- "mobile internet" --> mobileNet
  mobileNet -- "HTTPS request" --> https
  https -- "write/read data" --> cloud
```

### 2.4 Interface และ Data Contract เบื้องต้น

#### BLE payload จาก ESP32 ไปยังมือถือ

| Field | Type | ความหมาย |
| --- | --- | --- |
| `device_id` | string | รหัสอุปกรณ์ ESP32 |
| `timestamp_ms` | int64 | เวลาอ่านค่าสัญญาณ |
| `strain_raw` | int32/float | ค่าดิบจาก strain gauge |
| `imu_omega` | float | ความเร็วเชิงมุมที่ได้จาก IMU |
| `power_est_w` | float | ค่ากำลังปั่นที่ระบบประมาณได้ |
| `status_flags` | bitmask | calibration state, signal quality, sync state |

#### โครงสร้างข้อมูลบนคลาวด์เบื้องต้น

| Path | เนื้อหาหลัก |
| --- | --- |
| `/users/{uid}/devices/{deviceId}` | ข้อมูลอุปกรณ์, calibration profile, firmware version |
| `/users/{uid}/rides/{rideId}` | สรุปการปั่น เช่น start/end time, avg power, max power |
| `/users/{uid}/rides/{rideId}/samples/{sampleId}` | time-series sample ของ strain, angular velocity, power และตำแหน่ง |
| `/users/{uid}/rides/{rideId}/route/{pointId}` | จุด route tracking เช่น latitude, longitude, timestamp |

### 2.5 Process Specification

ลำดับการทำงานของระบบมีดังนี้

1. ผู้ใช้ติดตั้ง sensor node บน crank arm และเปิด ESP32
2. ESP32 อ่านค่า strain gauge และ IMU จากนั้นทำ calibration และ filtering เบื้องต้น
3. ESP32 คำนวณ `power estimate = torque estimate x angular velocity`
4. ESP32 ส่งค่า telemetry ผ่าน BLE GATT ไปยังมือถือ
5. แอปมือถือถอดรหัส packet และรับข้อมูลกำลังปั่นพร้อมเวลา
6. แอปใช้ GPS ของมือถืออ่านตำแหน่ง แล้วสร้างข้อมูลติดตามเส้นทางสำหรับรอบการปั่นปัจจุบัน
7. แอปรวมข้อมูลเส้นทางกับข้อมูลกำลังปั่นตามเวลา แล้วแสดงผลในหน้าจอแบบเรียลไทม์ หน้าจอแผนที่ และประวัติการปั่น
8. เมื่อมือถือเชื่อมต่ออินเทอร์เน็ต แอปจะซิงก์ข้อมูลการปั่นไปยัง Cloud Firestore

### 2.6 Domain Specification

| Domain | องค์ประกอบ | บทบาท |
| --- | --- | --- |
| Physical domain | ผู้ปั่น, crank arm, strain gauge, IMU, ESP32, battery | โลกจริงที่สร้างและวัดสัญญาณ |
| Virtual domain | strain_raw, imu_omega, power_est_w, route point, ride session | ตัวแทนข้อมูลของสิ่งที่เกิดขึ้นในโลกจริง |
| Resources | บริการ BLE, ที่เก็บข้อมูลภายในเครื่อง, คอลเลกชันใน Firestore, หน่วยประมวลผลของสมาร์ตโฟน | ทรัพยากรที่ระบบใช้เก็บ ส่ง และประมวลผลข้อมูล |
| Services | การติดตามเส้นทาง, การสร้างเส้นทางสำหรับแผนที่, การรวมข้อมูลเส้นทางกับกำลังปั่น, การซิงก์ขึ้นคลาวด์ | บริการเชิงซอฟต์แวร์ที่สร้างมูลค่าให้ข้อมูล |
| Devices | ESP32 sensing node, smartphone | อุปกรณ์หลักสองตัวของระบบในข้อเสนอฉบับนี้ |

### 2.7 Technical Feasibility

| ประเด็น | เหตุผลที่เป็นไปได้ | ความเสี่ยง | แนวทางลดความเสี่ยง |
| --- | --- | --- | --- |
| Sensing on crank arm | งานอ้างอิง DIY แสดงให้เห็นว่าการวัด deformation บน crank arm สามารถนำมาใช้ประมาณ power ได้ [1] | ตำแหน่งติดตั้งไม่เหมาะสม, signal drift | ทำ jig สำหรับติดตั้ง, zero-offset calibration และยึด sensor ให้ repeatable |
| Angular velocity measurement from IMU | gyroscope ใน IMU สามารถใช้วัดความเร็วเชิงมุมของ crank arm ได้โดยตรง | noise, drift, การยึด sensor ไม่แน่น | ใช้ filtering, calibration และยึด sensor ให้ตำแหน่งคงที่ |
| ESP32 BLE transmission | ESP-IDF รองรับ BLE และ GATT server อย่างเป็นทางการ [3][4] | การหลุดการเชื่อมต่อ, latency, packet loss | ออกแบบ characteristic ให้เล็ก, ทำ reconnect strategy, เก็บ cache ฝั่งมือถือ |
| Mobile app integration | Flutter เชื่อม Firebase ได้ตรงผ่าน FlutterFire [5] | สิทธิ์ Bluetooth และพฤติกรรมการทำงานเบื้องหลังต่างกันในแต่ละแพลตฟอร์ม | เริ่มจาก Android-first และจำกัดขอบเขตให้ชัดก่อนขยายสู่ iOS |
| Cloud backup reliability | Cloud Firestore มีการเก็บข้อมูลแบบออฟไลน์และซิงก์เมื่อกลับมาออนไลน์ [7] | ข้อมูลขัดแย้งกัน, โควตา, ค่าใช้จ่ายเมื่อขยายระบบ | ใช้โครงสร้างข้อมูลแยกตามผู้ใช้ เขียนข้อมูลแบบกลุ่ม และเริ่มจาก Spark plan |
| Route-aware mobile service | แอปสามารถรวมข้อมูลกำลังปั่นกับเส้นทางจาก GPS แล้วสร้างชุดข้อมูลการปั่นเพื่อแสดงบนแผนที่ได้ | เวลาไม่ตรงกัน, ค่าตำแหน่งคลาดเคลื่อน | ใช้เวลาเป็นแกนหลักและบันทึกเส้นทางด้วยช่วงเวลาที่คงที่ |

สรุปเชิงเทคนิคคือโครงงานนี้ `ทำได้จริงในระดับต้นแบบ` หากยอมรับข้อจำกัดด้านความแม่นยำเชิงสัมบูรณ์ และให้ความสำคัญกับ calibration, คุณภาพการติดตั้ง และการกรองสัญญาณอย่างเหมาะสม

### 2.8 การคำนวณกำลังปั่นโดยประมาณ

ระบบนี้ประมาณค่ากำลังปั่นจากเซนเซอร์เพียง 2 ชนิด ได้แก่ `strain gauge` และ `IMU` โดยยึดสมการพื้นฐาน

`Power = Torque x Angular Velocity`

ลำดับการคำนวณมีดังนี้

1. strain gauge วัด deformation ของ crank arm และส่งค่าดิบ `strain_raw`
2. ESP32 ทำการลบ zero offset และกรองสัญญาณ
3. ค่าดังกล่าวถูกแปลงเป็น `torque estimate` ด้วย calibration constant
4. gyroscope ใน IMU วัดการหมุนของ crank arm เพื่อหาค่า `angular velocity`
5. จากนั้นคำนวณ `power estimate = torque estimate x angular velocity`

สมการที่ใช้สามารถเขียนอย่างย่อได้ดังนี้

- `Torque_est = Kt x (strain_raw - zero_offset)`
- `Power_est = Torque_est x omega_imu`

เพื่อให้ค่าที่ได้ใช้งานได้จริงในระดับต้นแบบ ระบบจะใช้การกรองสัญญาณและทำให้ข้อมูลเรียบขึ้นเพิ่มเติมก่อนแสดงผลในแอป โดยจะระบุผลลัพธ์เป็น `estimated power` ไม่ใช่ค่ามาตรฐานเชิงพาณิชย์แบบสัมบูรณ์

### 2.9 แนวทางตอบ requirement เรื่องความฉลาดของระบบแบบ 1B

โครงงานนี้เลือกตีความ requirement ด้านความฉลาดของระบบในรูปแบบ `decision support system` แทนการให้ระบบตัดสินใจแทนผู้ใช้ทั้งหมด กล่าวคือ แอปจะไม่แสดงเพียงค่ากำลังปั่น แต่จะวิเคราะห์ข้อมูลจากหลายองค์ประกอบร่วมกัน ได้แก่

- strain magnitude และ strain noise
- angular velocity และความสม่ำเสมอของการหมุนจาก IMU
- ความสอดคล้องระหว่างรูปแบบแรงกับรูปแบบการหมุนของ crank arm
- สถานะการคาลิเบรตของ sensor

ข้อมูลข้างต้นจะผ่านกระบวนการมากกว่า rule base ตรง ๆ เช่น filtering, moving average, variance analysis และ confidence scoring แล้วสรุปผลเป็น

- `measurement confidence`
- `rotation stability`
- `recalibration recommendation`
- `accept data / inspect mounting`

แนวทางนี้ทำให้ระบบตรงกับ requirement แบบ `1B` คือใช้การวิเคราะห์ข้อมูลเพื่อสนับสนุนการตัดสินใจของผู้ใช้ โดยไม่ใช่เพียง if-then rule แบบตัวแปรเดี่ยว

### 2.10 Security Considerations

- ใช้ BLE แบบ known-device pairing assumption และ whitelist `device_id` ของ ESP32 ที่แอปยอมรับ
- ใช้ Firebase Authentication เพื่อแยกข้อมูลตามผู้ใช้
- ใช้ Cloud Firestore Security Rules บังคับว่าอ่าน/เขียนได้เฉพาะ document ของตนเอง
- ไม่ hard-code secret key ไว้ใน firmware หรือ source ของแอป
- ตรวจสอบชนิดข้อมูลและช่วงค่าเบื้องต้นก่อนส่งขึ้น cloud เพื่อลด malformed payload

### 2.11 Requirement Coverage Checklist

| Requirement จากวิชา | การตอบโจทย์ในดราฟนี้ |
| --- | --- |
| Devices อย่างน้อย 2 ตัว | ใช้ ESP32 sensing node + smartphone เป็นอุปกรณ์หลัก 2 ตัว |
| Communication | ใช้ BLE ระหว่าง ESP32 กับมือถือ และ HTTPS/Firebase ระหว่างมือถือกับคลาวด์ |
| Security | มี BLE pairing assumption, การยืนยันตัวตนฝั่งแอป, Firestore rules |
| มีตัวตรวจจับและสั่งการ/actuate | sensing node ตรวจจับข้อมูล และมือถือทำหน้าที่ให้ recommendation/notification แก่ผู้ใช้เป็น actuation ฝั่งปลายทาง |
| Problem/Solution fit | บทที่ 1 อธิบาย pain point เรื่องต้นทุนของ power meter และแนวทางแก้ |
| Alternative solutions | บทที่ 1.2 |
| Technical feasibility | บทที่ 2.7 |
| Intelligent / decision support requirement | บทที่ 2.9 |
| Process specification | บทที่ 2.5 |
| Domain specification | บทที่ 2.6 |
| Testing | บทที่ 3 |
| Budget plan | บทที่ 5 |

> ข้อสังเกต: หากอาจารย์ตีความว่าต้องมี `2 embedded devices` อย่างชัดเจน แผนต่อยอดที่แนะนำคือเพิ่ม `handlebar alert node` หรือ `BLE display node` เป็นอุปกรณ์ลำดับถัดไป

### 2.12 แผนการดำเนินงาน

| สัปดาห์ | งานหลัก | Deliverable |
| --- | --- | --- |
| 1 | ศึกษา reference, competitor, requirement และออกแบบตำแหน่งติดตั้ง sensor | System concept + requirement map |
| 2 | ทดสอบการติดตั้ง strain gauge และวงจรอ่านสัญญาณ | Bench-test ของ force signal |
| 3 | พัฒนาเฟิร์มแวร์บน ESP32 และแพ็กเก็ต BLE | ต้นแบบ sensing node |
| 4 | พัฒนาแอป Flutter และโครงสร้างข้อมูลบน Firebase | หน้าจอแสดงผลบนมือถือและการเชื่อมต่อคลาวด์ |
| 5 | รวมระบบ ปรับ calibration ทดสอบการเก็บข้อมูลแบบออฟไลน์และการซิงก์ | ต้นแบบที่เชื่อมต่อครบวงจร |
| 6 | ทดสอบภาคสนาม วิเคราะห์ข้อจำกัด จัดทำรายงานและสไลด์ | ดราฟสุดท้ายสำหรับนำเสนอ |

การแบ่งงานภายในกลุ่มสามารถใช้โครงนี้เป็นค่าเริ่มต้น

- สมาชิก A: hardware + sensor integration
- สมาชิก B: เฟิร์มแวร์ + BLE
- สมาชิก C: แอปมือถือ + คลาวด์ + การทดสอบ/เอกสาร

ถ้าเป็นกลุ่มขนาดเล็กกว่านี้สามารถรวมบทบาทเข้าด้วยกันได้

---

## บทที่ 3 วิธีการทดสอบ ผลและวิเคราะห์การทดสอบ

> บทนี้ใน draft ฉบับนี้เป็น `แผนการทดสอบ` และ `expected evidence` ไม่ใช่ผลทดลองจริง

### 3.1 เป้าหมายการทดสอบ

- ตรวจสอบว่าระบบอ่านสัญญาณจาก crank arm ได้สม่ำเสมอ
- ตรวจสอบว่า ESP32 ส่งข้อมูลผ่าน BLE ไปยังมือถือได้ต่อเนื่อง
- ตรวจสอบว่าแอปมือถือเก็บเส้นทางและรวมกับข้อมูลกำลังปั่นได้ถูกต้อง
- ตรวจสอบว่าแอปมือถือเก็บข้อมูลชั่วคราวและซิงก์ขึ้นคลาวด์ได้
- ประเมินข้อจำกัดด้าน calibration, latency และการวัด angular velocity จาก IMU

### 3.2 แผนการทดสอบ

| Test ID | รายการทดสอบ | วิธีการ | หลักฐานที่คาดหวัง |
| --- | --- | --- | --- |
| T1 | Zero-offset calibration | วัดค่าขณะไม่มีแรงกดซ้ำหลายรอบ | ค่าดิบมี baseline ที่เสถียร |
| T2 | Known-load calibration | ใช้น้ำหนักหรือแรงคงที่ที่รู้ค่าเทียบกับ output | ได้ scale factor สำหรับแปลง force_raw |
| T3 | ความเสถียรของ BLE | ปั่นต่อเนื่อง 20-30 นาที | การสูญหายของแพ็กเก็ตต่ำ และเชื่อมต่อใหม่ได้เมื่อหลุด |
| T4 | การติดตามเส้นทางและซิงก์ขึ้นคลาวด์ | ปิดอินเทอร์เน็ตระหว่างปั่นแล้วเปิดภายหลัง | ข้อมูลเส้นทางและกำลังปั่นถูกซิงก์กลับไปยังคลาวด์ครบถ้วน |
| T5 | IMU angular velocity validation | เปรียบเทียบค่า angular velocity กับการหมุนจริงของ crank arm | แนวโน้มการหมุนสอดคล้องในระดับ prototype |
| T6 | การเปรียบเทียบกับอุปกรณ์อ้างอิง | เปรียบเทียบแนวโน้มกับ smart trainer หรือ commercial meter | แนวโน้มสอดคล้องกันในระดับต้นแบบ |
| T7 | การรวมข้อมูลเส้นทางกับกำลังปั่น | ตรวจสอบการจับคู่ข้อมูลเส้นทางกับกำลังปั่นตามเวลา | ชุดข้อมูลการปั่นที่ได้มีลำดับถูกต้องและแสดงผลได้ |

### 3.3 แนวทางวิเคราะห์ผล

ตัวชี้วัดหลักที่ควรเก็บเพื่อวิเคราะห์ผล ได้แก่

- ค่า drift ของ zero offset ตามเวลา
- ค่าเฉลี่ยและส่วนเบี่ยงเบนของช่วงเวลาระหว่างแพ็กเก็ต
- จำนวนตัวอย่างข้อมูลที่ค้างในหน่วยเก็บชั่วคราวภายในเครื่อง และระยะเวลาที่ใช้ในการซิงก์
- ความต่างเชิงแนวโน้มเมื่อเทียบกับอุปกรณ์ reference
- ความต่างของ angular velocity จาก IMU เทียบกับค่าอ้างอิง
- การเปลี่ยนแปลงของ confidence score เมื่อ sensor quality ลดลง

หากผลออกมาว่าค่ากำลังปั่นยังไม่นิ่ง แต่แนวโน้มยังสอดคล้องกับ effort ของผู้ปั่น ระบบนี้ยังถือว่ามีคุณค่าในฐานะ `ต้นแบบระดับรายวิชา` และสามารถต่อยอดในรอบถัดไปได้

---

## บทที่ 4 สรุปผลการดำเนินงาน และข้อเสนอแนะ

โครงงานนี้เสนอการพัฒนาระบบจักรยานอัจฉริยะสำหรับตรวจวัดและบันทึกข้อมูลการปั่นในรูปแบบ add-on ที่ใช้ crank arm เดิมเป็นฐานติดตั้ง strain gauge และใช้ ESP32 เป็นแกนหลักของ sensing node เพื่อคำนวณค่ากำลังปั่นเบื้องต้นและส่งข้อมูลผ่าน BLE ไปยังแอปมือถือ จากนั้นมือถือจะทำหน้าที่รับข้อมูลเส้นทางจาก GPS แสดงผลบนแผนที่ และเป็น gateway สำหรับสำรองข้อมูลขึ้นคลาวด์

จุดแข็งของแนวคิดนี้คือ

- ต้นทุนต่ำกว่าการซื้อ power meter เชิงพาณิชย์มาก
- ไม่ต้องเปลี่ยน crankset หรือโครงสร้างหลักของจักรยาน
- มีสถาปัตยกรรม IoT ครบทั้ง sensing, communication, application, service และ cloud
- เหมาะกับการเรียนรู้และต่อยอดด้าน sports analytics

ข้อจำกัดที่คาดไว้

- ความแม่นยำขึ้นกับคุณภาพการติดตั้ง strain gauge และ calibration อย่างมาก
- ระบบใน draft นี้ยังพึ่ง smartphone เป็นอุปกรณ์ปลายทางตัวที่สอง ไม่ใช่ embedded actuator node แยก
- ความทนทานต่อฝน แรงสั่นสะเทือน และสภาพแวดล้อมจริงยังต้องพิสูจน์เพิ่มเติม

ข้อเสนอแนะในการพัฒนาต่อ

- เพิ่ม `handlebar alert node` หรือ BLE head unit เพื่อให้ requirement เรื่อง 2 devices แข็งแรงขึ้น
- พัฒนา algorithm สำหรับการวัด angular velocity จาก IMU ให้เสถียรมากขึ้น
- พัฒนาชุดติดตั้ง sensor ให้ repeatable มากขึ้น
- เพิ่มการเปรียบเทียบกับ commercial meter หลายช่วงกำลังปั่น
- หาก prototype มีเสถียรภาพพอ สามารถต่อยอดไปสู่ ANT+ compatibility หรือ advanced analytics ได้

---

## บทที่ 5 แผนการเงิน

> ตารางนี้เป็นงบประมาณประมาณการสำหรับ prototype รุ่นแรก

| รายการ | จำนวน | ราคาต่อหน่วย (บาท) | ราคารวม (บาท) | หมายเหตุ |
| --- | ---: | ---: | ---: | --- |
| ESP32 Dev Board | 1 | 100 | 100 | MCU หลักสำหรับอ่านเซนเซอร์และส่ง BLE |
| Strain gauge | 4 | 12 | 48 | ติดตั้งบน crank arm |
| HX711 | 1 | 50 | 50 | อ่านสัญญาณจาก strain gauge |
| MPU6050 | 1 | 90 | 90 | ใช้วัด angular velocity จาก IMU |
| Battery 7.4V | 1 | 350 | 350 | แหล่งจ่ายพลังงานของอุปกรณ์ |
| PLA+ filament | 1 | 500 | 500 | พิมพ์ชิ้นส่วนยึดและ housing เบื้องต้น |
| Wiring / connectors | 1 | 200 | 200 | ใช้ต่อวงจรและเชื่อมอุปกรณ์ |
| Step-down 5V | 1 | 40 | 40 | ปรับแรงดันไฟให้เหมาะกับระบบ |
| Firebase (prototype tier) | 1 | 0 | 0 | ใช้บริการระดับฟรีในช่วงต้นแบบ |
| **รวม** |  |  | **1,378** | ประมาณการเบื้องต้นตามรายการอุปกรณ์ปัจจุบัน |

---

## อ้างอิง

1. Steve Jarvis, “Homemade Power Meter,” available: <https://imateapot.dev/homemade-power-meter/> (accessed 2026-04-09).
2. YouTube reference provided by project owner, available: <https://www.youtube.com/watch?v=CRa9djnZRu0&t=11s> (accessed 2026-04-09).
3. Espressif, “Bluetooth API - ESP32,” available: <https://docs.espressif.com/projects/esp-idf/en/stable/esp32/api-reference/bluetooth/index.html> (accessed 2026-04-09).
4. Espressif, “GATT Server API - ESP32,” available: <https://docs.espressif.com/projects/esp-idf/en/stable/esp32/api-reference/bluetooth/esp_gatts.html> (accessed 2026-04-09).
5. Firebase, “Add Firebase to your Flutter app,” available: <https://firebase.google.com/docs/flutter/setup> (accessed 2026-04-09).
6. Firebase, “Cloud Firestore,” available: <https://firebase.google.com/products/firestore> (accessed 2026-04-09).
7. Firebase, “Access data offline,” available: <https://firebase.google.com/docs/firestore/manage-data/enable-offline> (accessed 2026-04-09).
8. Firebase, “Get started with Cloud Firestore Security Rules,” available: <https://firebase.google.com/docs/firestore/security/get-started> (accessed 2026-04-09).
9. Stages Cycling, “Single Sided Power Meters,” available: <https://stagescycling.com/en_global/product/power-meters/single-sided> (accessed 2026-04-09).
10. Shimano, “FC-R9200-P,” available: <https://bike.shimano.com/pl-PL/products/components/pdp.P-FC-R9200-P.html> (accessed 2026-04-09).
11. CCACHE, “4iiii Precision 3+ Power Meter Left Arm Only - 105 R7100,” available: <https://ccache.cc/products/4iiii-precision-3-power-meter-left-arm-only-105-r7100> (accessed 2026-04-09).
12. Priceza, “ขาวัตต์ Stages Ultegra R8000,” available: <https://www.priceza.com/s/%E0%B8%A3%E0%B8%B2%E0%B8%84%E0%B8%B2/%E0%B8%82%E0%B8%B2%E0%B8%A7%E0%B8%B1%E0%B8%95%E0%B8%95%E0%B9%8Cstages-ultegra-r8000> (accessed 2026-04-09).
13. Ubuy Thailand, “4iiii Precision 3 Powermeter Ride Ready - Left-Side,” available: <https://www.ubuy.co.th/th/product/IEUP1SR62-4iiii-precision-3-powermeter-ride-ready-left-side-ant-performance-meter-for-outdoor-indoor-cycling-measures-watts-cadence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> (accessed 2026-04-09).
14. CCACHE, “Shimano Dura-Ace FC-R9200-P Left Hand Crank Arm Unit,” available: <https://ccache.cc/products/shimano-dura-ace-fc-r9200-p-left-hand-crank-arm-powermeter> (accessed 2026-04-09).
15. Priceza, “ขาจาน 105,” available: <https://www.priceza.com/s/%E0%B8%A3%E0%B8%B2%E0%B8%84%E0%B8%B2/%E0%B8%82%E0%B8%B2%E0%B8%88%E0%B8%B2%E0%B8%99105> (accessed 2026-04-09).
16. CCACHE, “4iiii Precision 3+ Power Meter Left Arm Only - GRX 810/820,” available: <https://ccache.cc/products/4iiii-precision-3-power-meter-left-arm-only-grx-810-820> (accessed 2026-04-09).
17. CCACHE, “4iiii Precision 3+ Power Meter Left Arm Only - Ultegra R8100,” available: <https://ccache.cc/products/4iiii-precision-3-power-meter-left-arm-only-ultegra-r8100> (accessed 2026-04-09).
18. CCACHE, “4iiii Precision 3+ Power Meter Left Arm Only - Dura-Ace R9200,” available: <https://ccache.cc/products/4iiii-precision-3-power-meter-left-arm-only-dura-ace-r9200> (accessed 2026-04-09).
19. CCACHE, “Shimano FC-R8100-P Left Hand Crank Arm Unit 172.5mm,” available: <https://ccache.cc/products/shimano-fc-r8100-p-left-hand-crank-arm-unit-172-5mm> (accessed 2026-04-09).

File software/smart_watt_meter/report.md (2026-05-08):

# Flutter App — Full-System Firmware Integration Report
**Date:** 2026-05-06 (updated after full-system firmware integration)
**Author:** Claude Code
**Audience:** Codex (firmware developer)

---

## Summary of Changes (this update)

The Flutter app has been updated to work with Codex's full-system firmware
(`electrical/integration_test/smart_watt_meter_full_system/smart_watt_meter_full_system.ino`).

Key changes:
- Discovered and stored the new app status / command write characteristic `...014`.
- App sends `{"type":"appStatus","gpsOk":…,"recording":…}` to ESP32 on connect,
  on start/stop recording, on GPS fix change, and every ~1 s (heartbeat).
- Added command helpers: `tare`, `gyroBias`, `axisCal`.
- Event packets (`type == "event"`) are now routed to a separate stream and never
  silently converted into zero-power telemetry.
- `start_request` / `stop_request` events from ESP32 BTN1 trigger start/stop in the app.
- `calOk` status badge added to the Power Dashboard UI.
- Dropped packet detection counts only telemetry `seq`, not event `seq`.
- 11 new unit tests for `BlePacket.tryFromJson` and `BleEvent.tryFromJson`.

---

## BLE Connection Details (for firmware reference)

| Parameter | Value |
|---|---|
| Device name | `ESP32_PowerMeter_01` |
| Service UUID | `12345678-1234-1234-1234-123456789012` |
| Telemetry characteristic | `12345678-1234-1234-1234-123456789013` — READ + NOTIFY |
| App status / command characteristic | `12345678-1234-1234-1234-123456789014` — WRITE + WRITE_NR |

---

## Full-System Telemetry Packet (v2)

Sent by ESP32 on `...013` at 1 Hz. Detected by presence of `powerW` key.

```json
{
  "v": 1,
  "type": "telemetry",
  "seq": 128,
  "tMs": 128420,
  "powerW": 245.3,
  "cadenceRpm": 82.1,
  "forceN": 34.2,
  "torqueNm": 5.9,
  "omegaRadS": 8.6,
  "hxRaw": 29120,
  "hxTared": true,
  "imuOk": true,
  "hxOk": true,
  "calOk": true
}
```

| Field | Type | Description |
|---|---|---|
| `v` | int | Packet schema version (1) |
| `type` | string | `"telemetry"` |
| `seq` | int | Monotonic counter — app uses this to detect dropped telemetry packets |
| `tMs` | int | ESP32 `millis()` timestamp — stored as `deviceTimeMs` |
| `powerW` | double | Computed power in watts |
| `cadenceRpm` | double | Crank cadence from MPU6050 gyroscope in RPM |
| `forceN` | double | Calibrated force from HX711 in newtons |
| `torqueNm` | double | Crank torque in N·m |
| `omegaRadS` | double | Crank angular velocity in rad/s |
| `hxRaw` | int | Raw or delta-raw HX711 ADC count |
| `hxTared` | bool | Whether HX711 tare has been completed |
| `imuOk` | bool | Whether MPU6050 readings are valid |
| `hxOk` | bool | Whether HX711 readings are valid |
| `calOk` | bool | Whether calibration is complete enough to trust `forceN`, `torqueNm`, `powerW` |

---

## Event Packets

Sent by ESP32 on the same `...013` characteristic.
Distinguished from telemetry by `"type":"event"`.

```json
{"v":1,"type":"event","seq":44,"tMs":55200,"event":"start_request"}
{"v":1,"type":"event","seq":45,"tMs":55300,"event":"stop_request"}
{"v":1,"type":"event","seq":46,"tMs":55400,"event":"tare_ok"}
{"v":1,"type":"event","seq":47,"tMs":55500,"event":"gyro_bias_ok"}
{"v":1,"type":"event","seq":48,"tMs":55600,"event":"axis_cal_ok"}
```

**How the app handles events:**

| Event | App behavior |
|---|---|
| `start_request` | Calls `startRide()` if connected and not already recording |
| `stop_request` | Calls `stopRide()` if currently recording |
| `tare_ok`, `gyro_bias_ok`, `axis_cal_ok`, others | Logged to debug output — no UI action yet |

**Critical:** event packets are routed to `BleService.eventStream` and never fed
into `packetStream`. `BlePacket.tryFromJson` returns `null` for any packet with
`"type":"event"`. This prevents event packets from appearing as zero-power
telemetry samples.

---

## Dropped Packet Detection

The app tracks dropped BLE packets using `seq` from **telemetry packets only**.
Event packets use the same shared firmware counter (`packetSeq`) but their `seq`
values are not counted for drop detection. This is intentional:

- The app only calls `_lastSeq` update when `BlePacket.tryFromJson` returns a
  non-null telemetry packet.
- Event seq values are silently skipped, so the gap they introduce in the telemetry
  seq view is not counted as a dropped telemetry packet.

> **Note for firmware:** if you later want precise dropped-telemetry counts, consider
> splitting into separate `telemetrySeq` and `eventSeq` counters on the ESP32 side.
> The app is ready to handle this — just add a `telemetrySeq` field to telemetry
> packets and the existing logic will use it correctly.

---

## App Status Write (OLED GPS / REC Top Bar)

The app writes to `...014` to keep the ESP32 OLED top bar in sync.

**Packet format:**
```json
{"type":"appStatus","gpsOk":true,"recording":true}
```

**When the app writes:**
1. Immediately after BLE characteristics are discovered (connect).
2. When `startRide()` is called → `recording: true`.
3. When `stopRide()` is called → `recording: false`.
4. When GPS fix status changes (`accuracy < 50 m` threshold).
5. Every ~1 second via heartbeat timer while connected.

The firmware's `APP_STATUS_TIMEOUT_MS` is 3500 ms — the 1 s heartbeat keeps
`appGpsOk` and `appRecording` alive on the OLED without timing out.

---

## Command Write (to `...014`)

The app can send calibration commands to ESP32. Methods available in `BleService`
and exposed through `AppState`:

| Dart method | JSON written | Firmware action |
|---|---|---|
| `sendTare()` | `{"type":"command","cmd":"tare"}` | Runs `tareHx711()`, sends `tare_ok` event |
| `sendGyroBias()` | `{"type":"command","cmd":"gyroBias"}` | Runs `calibrateGyroBias()` |
| `sendAxisCal()` | `{"type":"command","cmd":"axisCal"}` | Runs `calibrateCrankAxis()` |

UI buttons for these commands are not wired yet — the service methods exist for
direct testing via `AppState.sendTare()` etc.

---

## calOk UI Behavior

- Dashboard always shows live `powerW` / `cadenceRpm` values regardless of `calOk`.
  This preserves debug visibility during calibration.
- A small badge next to the power zone label shows:
  - **`CAL OK`** (green) when `calOk == true`
  - **`CAL --`** (amber) when `calOk == false`
  - Badge is hidden when no full-system packet has been received yet (`calOk == null`).

---

## Fields ESP32 Must NOT Send

| Field | Reason |
|---|---|
| `speed` | Phone GPS owns speed. Mock `speed` is deprecated — app ignores it. |
| `lat` / `lng` | Phone GPS owns location. |
| `distanceKm` | Phone GPS accumulates distance. |
| `batteryV` | Not wired in current hardware. |
| Upload / sync status | App/Firebase layer only. |

---

## Packet Detection Logic (Dart)

```dart
// BlePacket.tryFromJson — in ble_service.dart
static BlePacket? tryFromJson(Map<String, dynamic> json) {
  final type = json['type'] as String?;
  if (type == 'event') return null;           // events never become telemetry
  if (json.containsKey('powerW')) { /* v2 */ }
  if (json.containsKey('power'))  { /* mock */ }
  return null; // unrecognised
}
```

---

## Test Results

```
flutter analyze  →  No issues found
flutter test     →  12/12 passed
  - BlePacket.tryFromJson: 7 tests
  - BleEvent.tryFromJson:  4 tests
  - Widget smoke test:     1 test
```

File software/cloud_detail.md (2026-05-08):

We already decided the Firebase/cloud design. Please follow this exactly unless there is a strong reason to change it.

Project:
- Mobile app for an IoT bicycle watt-meter
- During a ride, data is stored locally in the app
- After the ride ends, the app uploads the complete ride to Firebase
- This is post-ride upload, not realtime cloud streaming
- Current full-system device telemetry comes from ESP32 + HX711 + MPU6050 over BLE.
- Phone GPS owns speed, route, and distance. ESP32 does not send real speed.

Firebase setup already decided:
- Cloud Firestore
- Firebase Anonymous Auth
- Firestore currently in test mode

Firestore schema version:
- Current target schema: `schemaVersion = 2`
- Keep backward compatibility with older v1 documents where practical.
- Legacy v1 fields `power`, `cadence`, and `speed` may still exist in older samples, but new full-system samples should use unit-explicit fields such as `powerW`, `cadenceRpm`, and `gpsSpeed`.

Firestore schema:

users/{uid}
  fields:
    createdAt
    lastActiveAt

users/{uid}/rides/{rideId}
  fields:
    title
    startTime
    endTime
    durationSec
    distanceKm
    avgPower
    maxPower
    avgCadence
    maxCadence
    avgSpeed
    maxSpeed
    avgForce
    maxForce
    avgTorque
    maxTorque
    avgOmega
    maxOmega
    calories
    sampleCount
    deviceSampleCount
    gpsSampleCount
    droppedPacketCount
    calibrationOk
    hxTared
    imuOk
    hxOk
    schemaVersion
    uploadMode
    syncStatus
    createdAt

users/{uid}/rides/{rideId}/samples/{sampleId}
  fields:
    timestamp
    elapsedSec
    deviceTimeMs
    seq
    powerW
    cadenceRpm
    forceN
    torqueNm
    omegaRadS
    hxRaw
    hxTared
    imuOk
    hxOk
    calOk
    gpsSpeed
    lat
    lng

Important rules:
- 1 ride = 1 document
- 1 timestep sample = 1 document
- samples are uploaded only after the ride ends
- ride document stores summary
- samples subcollection stores time-series
- Keep writes simple and post-ride only; do not stream to Firestore during a ride.
- Do not store ESP32 mock `speed` as real bicycle speed. Store phone GPS speed as `gpsSpeed`.
- Do not add `batteryV` unless hardware battery sensing is actually added later.

Full-system BLE packet fields that map into samples:

```json
{
  "v": 1,
  "type": "telemetry",
  "seq": 128,
  "tMs": 128420,
  "powerW": 245.3,
  "cadenceRpm": 82.1,
  "forceN": 34.2,
  "torqueNm": 5.9,
  "omegaRadS": 8.6,
  "hxRaw": 29120,
  "hxTared": true,
  "imuOk": true,
  "hxOk": true,
  "calOk": true
}
```

Example v2 ride sample:

```json
{
  "timestamp": "2026-05-06T14:22:10.000",
  "elapsedSec": 42,
  "deviceTimeMs": 128420,
  "seq": 128,
  "powerW": 245.3,
  "cadenceRpm": 82.1,
  "forceN": 34.2,
  "torqueNm": 5.9,
  "omegaRadS": 8.6,
  "hxRaw": 29120,
  "hxTared": true,
  "imuOk": true,
  "hxOk": true,
  "calOk": true,
  "gpsSpeed": 28.5,
  "lat": 13.65,
  "lng": 100.49
}
```

Example v2 ride summary:

```json
{
  "schemaVersion": 2,
  "title": "Ride 2026-05-06",
  "startTime": "2026-05-06T14:21:28.000",
  "endTime": "2026-05-06T14:45:02.000",
  "durationSec": 1414,
  "distanceKm": 8.42,
  "avgPower": 184.5,
  "maxPower": 421.0,
  "avgCadence": 78.2,
  "maxCadence": 103.4,
  "avgSpeed": 21.4,
  "maxSpeed": 35.8,
  "avgForce": 31.6,
  "maxForce": 79.2,
  "avgTorque": 5.4,
  "maxTorque": 13.5,
  "avgOmega": 8.2,
  "maxOmega": 10.8,
  "sampleCount": 1414,
  "deviceSampleCount": 1410,
  "gpsSampleCount": 1398,
  "droppedPacketCount": 4,
  "calibrationOk": true,
  "hxTared": true,
  "imuOk": true,
  "hxOk": true,
  "uploadMode": "auto",
  "syncStatus": "synced",
  "createdAt": "2026-05-06T14:45:05.000"
}
```

Please build the Flutter-side implementation around this schema.
Keep the design simple and suitable for a 2-week course project.

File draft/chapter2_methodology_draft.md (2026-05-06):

# บทที่ 2 วิธีการดำเนินการ

## 2.1 ภาพรวมระบบ

โครงงานนี้พัฒนาระบบตรวจวัดกำลังปั่นจักรยานในรูปแบบระบบเสริมที่ติดตั้งบนขาจานข้างเดียว โดยไม่ต้องเปลี่ยนโครงสร้างหลักของจักรยาน ข้อมูลหลักของระบบมาจาก `strain gauge` ซึ่งใช้ตรวจจับการเปลี่ยนรูปของ crank arm และ `IMU` ซึ่งใช้วัดความเร็วเชิงมุมของขาจาน จากนั้นข้อมูลทั้งหมดจะถูกส่งเข้าสู่ `ESP32` เพื่อทำการคาลิเบรต กรองสัญญาณ และคำนวณค่ากำลังปั่นเบื้องต้นบนตัวอุปกรณ์

เมื่อได้ค่ากำลังปั่นแล้ว `ESP32` จะส่งข้อมูลผ่าน `Bluetooth Low Energy (BLE)` ไปยังแอปพลิเคชันบนมือถือฝั่ง `Android` แอปมือถือทำหน้าที่รับข้อมูลจากจักรยาน แสดงผลแบบเรียลไทม์ อ่านตำแหน่งจาก GPS ติดตามเส้นทางการปั่น และรวมข้อมูลกำลังปั่นกับข้อมูลเส้นทางเข้าเป็นชุดข้อมูลการปั่นหนึ่งรอบ ก่อนส่งข้อมูลดังกล่าวขึ้น `Firebase Cloud Firestore` ผ่านเครือข่าย `4G / 5G`

แนวทางนี้ช่วยแบ่งหน้าที่ของแต่ละส่วนได้อย่างชัดเจน กล่าวคือ ฝั่งจักรยานรับผิดชอบการตรวจวัดและการคำนวณกำลังปั่นเบื้องต้น ขณะที่แอปมือถือรับผิดชอบการแสดงผล การติดตามเส้นทาง และการจัดเก็บข้อมูลขึ้นคลาวด์

## 2.2 การออกแบบฮาร์ดแวร์

การออกแบบฮาร์ดแวร์ของโครงงานนี้มุ่งให้ระบบสามารถติดตั้งบนจักรยานเดิมได้โดยไม่กระทบต่อโครงสร้างหลักของรถ ตำแหน่งหลักที่ใช้ติดตั้งเซนเซอร์คือบริเวณ `crank arm` เนื่องจากเป็นตำแหน่งที่รับแรงจากผู้ปั่นโดยตรงและสามารถนำการเปลี่ยนรูปของวัสดุมาใช้ประมาณแรงบิดได้

ในส่วนของตัวอุปกรณ์ `ESP32` จะถูกติดตั้งอยู่ในกล่องที่ออกแบบให้มีขนาดกะทัดรัดและยึดติดกับตัวจักรยานได้อย่างมั่นคง เช่น บริเวณใกล้ชุดขาจานหรือท่อนั่ง ทั้งนี้การออกแบบกล่องต้องคำนึงถึงปัจจัยสำคัญ ได้แก่

- ความแข็งแรงของชุดยึด เพื่อป้องกันการเคลื่อนตัวระหว่างการปั่น
- น้ำหนักของอุปกรณ์ เพื่อไม่ให้รบกวนการทรงตัวของจักรยาน
- การป้องกันแรงสั่นสะเทือนจากพื้นถนน
- การป้องกันสายสัญญาณไม่ให้หลุดหรือเสียดสีกับชิ้นส่วนที่เคลื่อนที่

`strain gauge` จะถูกติดตั้งบน crank arm ในตำแหน่งที่สามารถรับการยืดหรือหดตัวได้ชัดเจนเมื่อผู้ปั่นออกแรง โดยต้องทำความสะอาดพื้นผิวและติดตั้งอย่างระมัดระวังเพื่อให้สัญญาณที่ได้มีความเสถียร ส่วน `IMU` จะถูกยึดไว้บน crank arm หรือบริเวณที่มีการเคลื่อนที่สอดคล้องกับการหมุนของขาจาน เพื่อให้สามารถวัดความเร็วเชิงมุมได้ใกล้เคียงกับการหมุนจริง

ดังนั้น การออกแบบฮาร์ดแวร์ไม่ได้พิจารณาเพียงการติดตั้งอุปกรณ์ให้ครบเท่านั้น แต่ต้องให้ความสำคัญกับความสามารถในการติดตั้งซ้ำได้ใกล้เคียงเดิม ความมั่นคงของอุปกรณ์ และความเหมาะสมต่อการใช้งานจริงในสภาพแวดล้อมของจักรยาน

## 2.3 การออกแบบทางไฟฟ้า

วงจรทางไฟฟ้าของระบบประกอบด้วย 5 ส่วนหลัก ได้แก่ แหล่งจ่ายพลังงาน วงจรอ่านสัญญาณจาก `strain gauge` วงจรอ่านข้อมูลจาก `IMU` หน่วยประมวลผล `ESP32` และวงจรปรับแรงดันไฟเลี้ยง

### 2.3.1 แหล่งจ่ายพลังงาน

ระบบใช้แบตเตอรี่ `7.4V` เป็นแหล่งจ่ายพลังงานหลักของอุปกรณ์ จากนั้นใช้วงจร `step-down 5V` เพื่อลดแรงดันให้เหมาะกับอุปกรณ์ในระบบ โดยเฉพาะ `ESP32`, `HX711` และ `MPU6050` การใช้แบตเตอรี่ช่วยให้ระบบสามารถติดตั้งบนจักรยานได้โดยไม่ต้องพึ่งแหล่งจ่ายไฟภายนอก

### 2.3.2 วงจร strain gauge และ Wheatstone bridge

`strain gauge` เป็นเซนเซอร์ที่เปลี่ยนค่าความต้านทานเมื่อวัสดุที่ติดตั้งเกิดการยืดหรือหดตัว เนื่องจากการเปลี่ยนแปลงของความต้านทานมีขนาดเล็กมาก จึงต้องใช้วงจร `Wheatstone bridge` เพื่อแปลงการเปลี่ยนแปลงดังกล่าวให้เป็นความต่างศักย์ไฟฟ้าที่สามารถนำไปขยายและอ่านค่าได้

ในการใช้งานจริง `strain gauge` จำนวน 4 ตัวสามารถจัดเป็นสะพานวัดแบบเต็ม เพื่อเพิ่มความไวและช่วยลดผลกระทบจากอุณหภูมิ เมื่อ crank arm รับแรงจากการปั่น ค่าความต้านทานของ strain gauge จะเปลี่ยนไป ทำให้สมดุลของ Wheatstone bridge เปลี่ยนตาม และเกิดสัญญาณแรงดันขนาดเล็กที่สัมพันธ์กับแรงกระทำบน crank arm

### 2.3.3 วงจรอ่านสัญญาณด้วย HX711

สัญญาณจาก Wheatstone bridge มีขนาดเล็กมากในระดับมิลลิโวลต์ จึงไม่สามารถต่อเข้ากับ `ESP32` ได้โดยตรง ระบบจึงใช้ `HX711` เป็นวงจรขยายสัญญาณและแปลงสัญญาณอนาล็อกเป็นดิจิทัล `HX711` ทำหน้าที่รับสัญญาณจาก Wheatstone bridge ขยายให้มีระดับเหมาะสม และส่งข้อมูลดิจิทัลไปยัง `ESP32`

ลำดับการไหลของสัญญาณในส่วนนี้คือ

`strain gauge -> Wheatstone bridge -> HX711 -> ESP32`

### 2.3.4 วงจร IMU และการเชื่อมต่อกับ ESP32

ระบบใช้ `MPU6050` เป็น `IMU` สำหรับวัดการหมุนของ crank arm โดยเฉพาะข้อมูลจาก gyroscope ซึ่งใช้ในการหาค่าความเร็วเชิงมุมของขาจาน โมดูลนี้เชื่อมต่อกับ `ESP32` ผ่านบัสสื่อสารดิจิทัล ทำให้ `ESP32` สามารถอ่านข้อมูลการหมุนได้ต่อเนื่องและใช้ร่วมกับข้อมูลจาก strain gauge ในการคำนวณกำลังปั่น

ลำดับการไหลของข้อมูลในส่วนนี้คือ

`MPU6050 -> ESP32`

### 2.3.5 ภาพรวมการไหลของสัญญาณ

เมื่อนำทั้งระบบมารวมกัน การไหลของสัญญาณไฟฟ้าสามารถสรุปได้ดังนี้

- แรงจากผู้ปั่นทำให้ crank arm เปลี่ยนรูป
- `strain gauge` ตรวจจับการเปลี่ยนรูปดังกล่าว
- วงจร `Wheatstone bridge` แปลงการเปลี่ยนแปลงความต้านทานเป็นสัญญาณแรงดัน
- `HX711` ขยายสัญญาณและแปลงเป็นข้อมูลดิจิทัล
- `ESP32` อ่านข้อมูลจาก `HX711` และ `MPU6050`
- `ESP32` ประมวลผลเพื่อหาค่ากำลังปั่น และส่งข้อมูลต่อผ่าน BLE

## 2.4 การพัฒนาเฟิร์มแวร์

เฟิร์มแวร์บน `ESP32` เป็นส่วนสำคัญที่เชื่อมการตรวจวัดจากเซนเซอร์เข้ากับการสื่อสารไปยังแอปมือถือ หน้าที่หลักของเฟิร์มแวร์ประกอบด้วยการอ่านข้อมูลจากวงจรเซนเซอร์ การคาลิเบรต การกรองสัญญาณ การคำนวณกำลังปั่น และการสร้างข้อมูลสำหรับส่งผ่าน BLE

### 2.4.1 การอ่านข้อมูลจากเซนเซอร์

`ESP32` อ่านข้อมูลจากสองแหล่งหลัก ได้แก่

- ข้อมูลแรงดิบจาก `HX711` ซึ่งรับมาจาก Wheatstone bridge ของ `strain gauge`
- ข้อมูลความเร็วเชิงมุมจาก `MPU6050`

ข้อมูลทั้งสองส่วนจะถูกอ่านเป็นช่วงเวลาอย่างต่อเนื่อง เพื่อให้ระบบสามารถแสดงผลใกล้เคียงเวลาจริงได้

### 2.4.2 การคาลิเบรตและการกรองสัญญาณ

ก่อนนำข้อมูลไปคำนวณ เฟิร์มแวร์ต้องทำการลบค่า `zero offset` ของสัญญาณ strain และใช้ค่าคงที่จากการคาลิเบรตเพื่อแปลงค่าดิบให้เป็นค่าที่สามารถใช้ประมาณแรงบิดได้ หลังจากนั้นจึงทำการกรองสัญญาณเพื่อลดสัญญาณรบกวนจากการสั่นสะเทือนหรือความไม่เสถียรของการติดตั้ง

ในส่วนของ `IMU` เฟิร์มแวร์จะอ่านข้อมูลจาก gyroscope แล้วทำการกรองเบื้องต้นเช่นกัน เพื่อให้ค่าความเร็วเชิงมุมที่ได้เหมาะกับการคำนวณกำลังปั่น

### 2.4.3 การคำนวณกำลังปั่น

หลังจากได้ข้อมูลที่ผ่านการคาลิเบรตแล้ว `ESP32` จะนำข้อมูลจาก `strain gauge` มาใช้ประมาณค่าแรงบิด และนำข้อมูลจาก gyroscope มาใช้เป็นค่าความเร็วเชิงมุม จากนั้นคำนวณกำลังปั่นตามสมการ

`Power = Torque x Angular Velocity`

การคำนวณนี้ทำบนตัวอุปกรณ์โดยตรง จึงถือเป็นการประมวลผลแบบ edge computing ซึ่งช่วยให้ค่ากำลังปั่นพร้อมใช้งานทันทีโดยไม่ต้องรอให้แอปมือถือเป็นผู้คำนวณเองทั้งหมด

### 2.4.4 การสร้างข้อมูลสำหรับส่งผ่าน BLE

เมื่อคำนวณเสร็จแล้ว เฟิร์มแวร์จะจัดข้อมูลให้อยู่ในรูปแบบ `BLE telemetry packet` เพื่อส่งไปยังแอปมือถือ ข้อมูลสำคัญที่อยู่ในแพ็กเก็ต ได้แก่

- รหัสอุปกรณ์
- เวลาในการอ่านข้อมูล
- ค่าดิบจาก strain gauge
- ค่าความเร็วเชิงมุมจาก IMU
- ค่ากำลังปั่นที่ประมาณได้
- สถานะของระบบ เช่น สถานะการคาลิเบรตหรือคุณภาพของสัญญาณ

รูปแบบการส่งข้อมูลใช้ `BLE GATT` โดย `ESP32` ทำหน้าที่เป็นอุปกรณ์ปลายทางที่ส่งข้อมูลไปยังมือถืออย่างต่อเนื่องผ่านการแจ้งเตือนข้อมูลแบบเรียลไทม์

## 2.5 การพัฒนาแอปพลิเคชันบนมือถือ

แอปพลิเคชันบนมือถือทำหน้าที่เป็นส่วนติดต่อกับผู้ใช้และเป็นศูนย์กลางการจัดการข้อมูลของระบบ โดยเลือกพัฒนาด้วย `Flutter` และกำหนดให้รองรับระบบ `Android` เป็นหลักในระยะต้นแบบ

### 2.5.1 การรับข้อมูลจาก BLE

แอปมือถือทำหน้าที่ค้นหาอุปกรณ์ `ESP32` เชื่อมต่อผ่าน `BLE` และรับข้อมูลจาก `BLE telemetry packet` เมื่อได้รับข้อมูลแล้ว แอปจะถอดรหัสข้อมูลเพื่อแยกค่ากำลังปั่น เวลา และข้อมูลประกอบอื่น ๆ ก่อนนำไปแสดงผลหรือเก็บใช้งานต่อ

### 2.5.2 การอ่านข้อมูลตำแหน่ง

สำหรับการติดตามเส้นทาง แอปใช้ `Geolocator` เพื่ออ่านตำแหน่งจาก GPS ของโทรศัพท์มือถือ ข้อมูลที่เก็บในแต่ละช่วงเวลาประกอบด้วยค่าพิกัด `latitude`, `longitude` และเวลา จากนั้นแอปจะนำข้อมูลตำแหน่งเหล่านี้มาเรียงต่อกันเป็นเส้นทางการปั่น

### 2.5.3 การรวมข้อมูลกำลังปั่นกับเส้นทาง

เมื่อแอปได้รับทั้งข้อมูลกำลังปั่นจาก `ESP32` และข้อมูลตำแหน่งจาก GPS แล้ว แอปจะรวมข้อมูลทั้งสองชุดเข้าด้วยกันโดยอาศัยเวลาเป็นตัวอ้างอิง วิธีนี้ทำให้สามารถแสดงได้ว่าผู้ใช้ใช้กำลังปั่นเท่าใดในแต่ละช่วงของเส้นทาง

ผลลัพธ์ของการรวมข้อมูลจะถูกจัดเก็บในรูปแบบของชุดข้อมูลการปั่นหนึ่งรอบ ซึ่งสามารถนำไปแสดงผลและส่งขึ้นคลาวด์ได้ในขั้นตอนถัดไป

### 2.5.4 การแสดงผลบนแอป

หน้าที่หลักของแอปในมุมของผู้ใช้ประกอบด้วย

- หน้าจอแสดงค่ากำลังปั่นแบบเรียลไทม์
- หน้าจอแผนที่สำหรับดูเส้นทางการปั่น
- หน้าจอประวัติการปั่นย้อนหลัง

ในส่วนของแผนที่ แอปใช้ `Google Maps Flutter SDK` เพื่อแสดงเส้นทางที่ได้จากการติดตามตำแหน่ง และสามารถเชื่อมโยงข้อมูลกำลังปั่นเข้ากับเส้นทางดังกล่าวได้

## 2.6 การจัดเก็บข้อมูลบนคลาวด์

ระบบใช้ `Firebase` เป็นแพลตฟอร์มสำหรับจัดเก็บข้อมูลบนคลาวด์ โดยเลือกใช้ `Firebase Cloud Firestore` เป็นฐานข้อมูลหลัก เนื่องจากสามารถทำงานร่วมกับแอปมือถือได้สะดวกและเหมาะกับต้นแบบที่ต้องการจัดเก็บข้อมูลเป็นรอบการปั่น

### 2.6.1 การตั้งค่า Firebase เบื้องต้น

แอปมือถือจะเชื่อมต่อกับ Firebase ผ่าน `Firebase Flutter SDK` หลังจากตั้งค่าโครงการบน Firebase แล้ว แอปจะสามารถอ่านและเขียนข้อมูลที่เกี่ยวข้องกับผู้ใช้ อุปกรณ์ และข้อมูลการปั่นได้

### 2.6.2 รูปแบบข้อมูลที่จัดเก็บ

ข้อมูลที่จัดเก็บบนคลาวด์แบ่งออกเป็นระดับหลัก ๆ ดังนี้

- ข้อมูลอุปกรณ์ เช่น รหัสอุปกรณ์และค่าคาลิเบรต
- ข้อมูลการปั่นแต่ละรอบ เช่น เวลาเริ่ม เวลาเสร็จ และค่ากำลังปั่นโดยสรุป
- ข้อมูลตัวอย่างระหว่างการปั่น เช่น กำลังปั่น ความเร็วเชิงมุม และตำแหน่ง

การแยกข้อมูลในลักษณะนี้ช่วยให้สามารถเรียกดูประวัติการปั่นย้อนหลัง หรือวิเคราะห์ข้อมูลในภายหลังได้ง่ายขึ้น

### 2.6.3 การส่งข้อมูลจากมือถือขึ้นคลาวด์

แอปมือถือจะทำหน้าที่เป็นตัวกลางระหว่างจักรยานกับคลาวด์ โดยรับข้อมูลจาก `ESP32` ผ่าน BLE จากนั้นจัดเก็บข้อมูลชั่วคราวภายในเครื่อง และเมื่อมีการเชื่อมต่ออินเทอร์เน็ตผ่าน `4G / 5G` แอปจะส่งข้อมูลขึ้น `Firebase Cloud Firestore`

แนวทางนี้ช่วยลดภาระของฝั่งอุปกรณ์บนจักรยาน เพราะ `ESP32` ไม่จำเป็นต้องเชื่อมต่ออินเทอร์เน็ตโดยตรง ขณะเดียวกันยังช่วยให้ระบบสามารถทำงานต่อได้แม้สัญญาณเครือข่ายของมือถือจะขาดหายเป็นช่วง ๆ

## 2.7 สรุปลำดับการทำงานของระบบ

ลำดับการทำงานของระบบโดยรวมสามารถสรุปได้ดังนี้

1. `strain gauge` ตรวจจับการเปลี่ยนรูปของ crank arm และส่งสัญญาณเข้าสู่ `Wheatstone bridge`
2. วงจร `HX711` ขยายและแปลงสัญญาณให้ `ESP32` อ่านได้
3. `MPU6050` ส่งข้อมูลความเร็วเชิงมุมให้ `ESP32`
4. `ESP32` ทำการคาลิเบรต กรองสัญญาณ และคำนวณค่ากำลังปั่น
5. `ESP32` ส่งข้อมูลไปยังแอปมือถือผ่าน `BLE`
6. แอปมือถือรับข้อมูลกำลังปั่นและอ่านข้อมูลตำแหน่งจาก GPS
7. แอปรวมข้อมูลกำลังปั่นกับเส้นทาง และแสดงผลต่อผู้ใช้
8. แอปส่งข้อมูลการปั่นขึ้น `Firebase Cloud Firestore` ผ่านเครือข่ายมือถือ

จากลำดับการทำงานนี้จะเห็นได้ว่าระบบถูกออกแบบให้แต่ละส่วนทำหน้าที่เฉพาะของตนอย่างชัดเจน โดยฝั่งอุปกรณ์รับผิดชอบการตรวจวัดและคำนวณเบื้องต้น ขณะที่แอปมือถือรับผิดชอบการจัดการข้อมูล การแสดงผล และการเชื่อมต่อกับคลาวด์

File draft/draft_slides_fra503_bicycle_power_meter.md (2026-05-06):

# Draft Slides: FRA503 Bicycle Power Meter

## Slide 1: Introduction

**Title**

ระบบวัดกำลังปั่นจักรยานแบบ Add-on บน Crank Arm เดิมด้วย ESP32, Bluetooth และ Cloud Backup

**Key points**

- จักรยานเป็นพาหนะที่ไม่ก่อมลพิษ มีความคล่องตัว และถูกใช้งานได้หลายรูปแบบ
- ผู้ใช้จักรยานมีทั้งกลุ่มที่ใช้เป็นพาหนะ กลุ่มออกกำลังกาย และกลุ่มฝึกซ้อม/แข่งขัน
- กลุ่มที่เน้นสมรรถนะมักต้องการข้อมูลเชิงลึกมากขึ้น เช่น cadence และ power
- โครงงานนี้จึงมุ่งพัฒนาระบบวัดกำลังปั่นแบบต้นทุนต่ำที่เข้าถึงได้ง่ายขึ้น

**Speaker note**

จักรยานไม่ได้ถูกใช้แค่เพื่อการแข่งขัน แต่ยังใช้เป็นพาหนะและใช้เพื่อออกกำลังกายด้วย อย่างไรก็ตามกลุ่มที่เน้นสมรรถนะจะต้องการข้อมูลเชิงปริมาณมากกว่า เช่น cadence และ power ซึ่งเป็นที่มาของโครงงานนี้

**Reference**

- [1] <https://imateapot.dev/homemade-power-meter/>
- [2] <https://www.youtube.com/watch?v=CRa9djnZRu0&t=11s>

---

## Slide 2: Background Problem

**Main message**

นักปั่นมักติดตามหลายค่าระหว่างการปั่น แต่ค่าที่สะท้อน effort ได้ดีอย่าง `power` ยังเข้าถึงได้ยากกว่าค่าทั่วไป

**Suggested content**

- ค่าที่นักปั่นทั่วไปมักดู: speed, distance, time, calories
- ค่าที่กลุ่มออกกำลังกาย/สมรรถนะมักดูเพิ่ม: heart rate, cadence, power
- ในกลุ่มข้อมูลเหล่านี้ `power` เป็นตัวชี้วัดที่สำคัญ แต่ power meter เชิงพาณิชย์ยังมีราคาสูง
- จึงเกิดโจทย์ของระบบต้นทุนต่ำที่สามารถติดตั้งบนจักรยานเดิมได้

**Speaker note**

ย้ำ pain point สองชั้น คือ `cost barrier` และ `lack of openness` เมื่อเทียบกับการเรียนรู้เชิงวิศวกรรม

---

## Slide 3: Objective and Scope

**Objectives**

- วัด deformation บน crank arm ด้วย `strain gauge`
- ใช้ `IMU` เพื่อประมาณ cadence และ angular velocity
- คำนวณ estimated power จากข้อมูล 2 sensor
- ส่งข้อมูลจาก ESP32 ไปยัง smartphone ผ่าน BLE
- แสดงผล วิเคราะห์ และ backup ride data ผ่าน mobile app และ cloud

**Scope**

- In scope: `strain gauge + IMU`, BLE, mobile dashboard, calibration UI, cloud backup, security baseline
- Out of scope: commercial-grade accuracy, dual-sided power, ANT+ เต็มรูปแบบ, enclosure ระดับผลิตภัณฑ์จริง
- ในข้อเสนอฉบับนี้ใช้ `single-sided crank arm based system`
- smartphone ถูกตีความเป็นอุปกรณ์ปลายทางตัวที่สองของระบบ

**Speaker note**

ถ้าคณะกรรมการถามเรื่อง requirement 2 devices ให้ตอบตรง ๆ ว่า phase นี้ใช้ `ESP32 + smartphone` และ phase ถัดไปสามารถเพิ่ม handlebar alert node ได้

---

## Slide 4: System Diagram

**Visual**

ใช้แผนภาพจากไฟล์ `bicycle_power_meter_system_diagram.mmd`

**Talking points**

- Device layer: strain gauge, IMU, signal conditioning, ESP32, battery
- Communication layer: BLE GATT ระหว่าง ESP32 กับมือถือ และ HTTPS/Firebase SDK ระหว่างมือถือกับ cloud
- Service layer: calibration, filtering, power estimation, confidence analysis, cache/retry
- Application layer: Flutter app สำหรับ live dashboard, history, settings, notification
- Cloud layer: Firebase Firestore, optional Cloud Functions, security rules

**Key message**

ระบบนี้ออกแบบให้ mobile app เป็นทั้ง UI และ gateway สู่ cloud จึงลดความซับซ้อนของฝั่งจักรยาน

---

## Slide 5: Alternative Solution

**Products in market**

| สินค้า | ประเภท | จุดเด่น | ข้อจำกัด | ราคาอ้างอิง |
| --- | --- | --- | --- | ---: |
| Stages Gen 3 Ultegra R8000 | Left crank arm | ติดตั้งง่าย, single-sided, Accuracy ±1.5% | วัดขาเดียว | 13,100 บาท |
| 4iiii Precision 3+ Left Arm Only | Left crank arm | เบา, Accuracy ±1%, ANT+/BLE, battery life สูง | ต้องเลือก arm ให้ตรงรุ่นขาจาน | 14,000-19,354 บาท |
| Shimano FC-R9200-P Left Hand Arm | Left crank arm unit | ecosystem ของ Shimano, commercial-grade | ราคาสูงและเป็นชิ้นส่วนเฉพาะรุ่น | 19,040 บาท |

**Price chart**

Crank arm power meter price chart

**Interpretation**

- กราฟนี้คัดเฉพาะ `crank arm / left crank arm` เท่านั้น
- ช่วงราคาที่พบส่วนใหญ่อยู่ราว `11,800-19,040 บาท`
- มีบางรายการนำเข้าที่สูงขึ้นไปถึงประมาณ `25,783 บาท`

**Project positioning**

โปรเจกต์ของเราต่างจากสินค้าในตลาดตรงที่เป็น `add-on sensing system` ที่ติดตั้งบน crank arm เดิม โดยไม่ต้องเปลี่ยนโครงสร้างหลักของจักรยาน แต่ต้องมีการติดตั้งเซนเซอร์และ calibration อย่างเหมาะสมเพื่อให้วัดค่าได้ถูกต้อง

**Why crank arm based**

- ตรงกับแนวคิด add-on system เพราะติดตั้งบน crank arm เดิมได้
- ต้นทุนต่ำกว่า spider based และ crankset based
- เหมาะกับการติดตั้ง strain gauge และสร้าง prototype
- ซับซ้อนน้อยกว่า pedal based ในเชิงกลและการประกอบ

**References**

- Stages official: <https://stagescycling.com/en_global/product/power-meters/single-sided>
- Shimano official: <https://bike.shimano.com/pl-PL/products/components/pdp.P-FC-R9200-P.html>
- 4iiii retailer pages: <https://ccache.cc/products/4iiii-precision-3-power-meter-left-arm-only-105-r7100>, <https://ccache.cc/products/4iiii-precision-3-power-meter-left-arm-only-ultegra-r8100>, <https://ccache.cc/products/4iiii-precision-3-power-meter-left-arm-only-dura-ace-r9200>
- Thai-accessible listings: <https://www.priceza.com/s/%E0%B8%A3%E0%B8%B2%E0%B8%84%E0%B8%B2/%E0%B8%82%E0%B8%B2%E0%B8%A7%E0%B8%B1%E0%B8%95%E0%B8%95%E0%B9%8Cstages-ultegra-r8000>, <https://www.priceza.com/s/%E0%B8%A3%E0%B8%B2%E0%B8%84%E0%B8%B2/%E0%B8%82%E0%B8%B2%E0%B8%88%E0%B8%B2%E0%B8%99105>, <https://www.ubuy.co.th/th/product/IEUP1SR62-4iiii-precision-3-powermeter-ride-ready-left-side-ant-performance-meter-for-outdoor-indoor-cycling-measures-watts-cadence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>

---

## Slide 6: Technical Feasibility

| ด้านที่ประเมิน | ทำได้เพราะ | ความเสี่ยงหลัก | วิธีลดความเสี่ยง |
| --- | --- | --- | --- |
| Sensing on crank arm | มี precedent จากงาน DIY วัด deformation บน crank arm [1] | ติดตั้ง sensor ไม่ repeatable | ใช้ jig, zero-offset calibration, ตำแหน่งติดตั้งมาตรฐาน |
| IMU-based cadence estimation | IMU สามารถใช้ประมาณ angular velocity และ cadence จากการหมุนของ crank arm ได้ | noise และ drift | ใช้ filtering และวิเคราะห์ periodic motion |
| ESP32 BLE transmission | ESP-IDF รองรับ BLE และ GATT server อย่างเป็นทางการ [3][4] | connection drop, latency | ออกแบบ packet เล็ก, reconnect, cache ฝั่งมือถือ |
| Mobile app integration | Flutter + FlutterFire ใช้กับ Firebase ได้ตรง [5] | permission และ platform differences | เริ่ม Android-first และ lock scope |
| Cloud backup reliability | Firestore sync ข้อมูลและรองรับ offline persistence [6][7] | conflict, quota, cost | schema ง่าย, per-user path, batch sync |
| Decision support (1B) | ใช้ strain + IMU สร้าง confidence score, cadence stability, recommendation | ถ้าเป็นแค่ if-else จะยังไม่พอ | ใช้ filtering, moving average, variance และ confidence scoring |
| Calibration / accuracy | commercial meter ใช้ compensation และ calibration logic คล้ายกัน [9][10] | prototype แม่นยำต่ำกว่า commercial | ตั้งเป้าเป็น prototype และเทียบ sanity check กับ reference meter |

**Takeaway**

โครงงานนี้มีความเป็นไปได้เชิงเทคนิคในระดับ `prototype สำหรับการเรียนและพิสูจน์แนวคิด` โดยใช้ sensor เพียง 2 ชนิด คือ `strain gauge + IMU` และใช้แอปเป็น `decision support system`

**Power estimation concept**

- `Strain gauge -> torque estimate`
- `IMU -> angular velocity / cadence`
- `Estimated Power = Torque Estimate x Angular Velocity`

**Decision support (Requirement 1B)**

- แอปไม่ได้แค่แสดงค่า power แต่ประเมิน `measurement confidence`
- ใช้ข้อมูลหลายตัวร่วมกัน เช่น strain noise, cadence stability, motion consistency
- สรุปเป็นคำแนะนำให้ผู้ใช้ตัดสินใจ เช่น `accept data`, `recalibrate`, `inspect mounting`

**References**

- [1] <https://imateapot.dev/homemade-power-meter/>
- [3] <https://docs.espressif.com/projects/esp-idf/en/stable/esp32/api-reference/bluetooth/index.html>
- [4] <https://docs.espressif.com/projects/esp-idf/en/stable/esp32/api-reference/bluetooth/esp_gatts.html>
- [5] <https://firebase.google.com/docs/flutter/setup>
- [6] <https://firebase.google.com/products/firestore>
- [7] <https://firebase.google.com/docs/firestore/manage-data/enable-offline>
- [8] <https://firebase.google.com/docs/firestore/security/get-started>
- [9] <https://stagescycling.com/en_global/product/power-meters/single-sided>
- [10] <https://bike.shimano.com/pl-PL/products/components/pdp.P-FC-R9200-P.html>

---

## Slide 7: Project Cost

| รายการ | ราคาโดยประมาณ (บาท) |
| --- | ---: |
| ESP32 Dev Board | 250 |
| Strain gauge set | 350 |
| HX711 / ADC front-end | 120 |
| IMU module | 150 |
| Battery + charging/regulation | 400 |
| Enclosure + mounting hardware | 350 |
| Wiring / connectors / protoboard | 180 |
| Epoxy / waterproofing materials | 250 |
| Spare parts + calibration jig | 500 |
| Contingency | 400 |
| **รวม** | **2,950** |

**Message**

ต้นทุนของ prototype อยู่ในระดับ `หลักพันบาท` ซึ่งต่ำกว่าราคาสินค้า commercial อย่างชัดเจน และเหมาะกับเป้าหมายของรายวิชา

---

## Slide 8: Implementation Plan

| ช่วงเวลา | งานหลัก | ผลลัพธ์ |
| --- | --- | --- |
| Week 1 | requirement + competitor study + mechanical concept | problem definition + architecture |
| Week 2 | strain gauge installation + analog readout test | bench-test data |
| Week 3 | ESP32 firmware + BLE packet | sensing node prototype |
| Week 4 | Flutter UI + Firebase integration | live dashboard + cloud path |
| Week 5 | end-to-end integration + calibration | connected prototype |
| Week 6 | testing + analysis + documentation | final report + presentation |

**Closing message**

ถ้า prototype รุ่นแรกทำงานเสถียร จุดพัฒนาต่อที่สำคัญคือเพิ่มความแม่นยำของ calibration, ปรับความทนทานเชิงกล และเพิ่มอุปกรณ์ปลายทางอีกตัวเพื่อให้ architecture แข็งแรงขึ้นตาม requirement ของวิชา

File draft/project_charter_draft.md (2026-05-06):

# ใบเปิดโครงการ

## ข้อมูลทั่วไปของโครงการ

- รายวิชา: FRA503 Technopeuneurship in IoT Industry
- ชื่อโครงการ: การพัฒนาระบบจักรยานอัจฉริยะสำหรับตรวจวัดและบันทึกข้อมูลการปั่นผ่าน BLE และคลาวด์
- ชื่อกลุ่ม: กลุ่ม 2
- ผู้ดำเนินงาน: นายชญานิน นาเพีย รหัสนักศึกษา 65340500009
- อาจารย์ผู้สอน/ที่ปรึกษา: ........................................................

## บทนำ

จักรยานเป็นพาหนะที่ไม่ก่อมลพิษ มีความคล่องตัว และสามารถใช้งานได้หลากหลายทั้งการเดินทางในชีวิตประจำวัน การออกกำลังกาย และการฝึกซ้อมเพื่อการแข่งขัน ผู้ใช้แต่ละกลุ่มจึงมีความต้องการข้อมูลที่แตกต่างกัน โดยเฉพาะกลุ่มที่ต้องการติดตามสมรรถนะการปั่นมักให้ความสำคัญกับตัวชี้วัด เช่น ระยะทาง เวลา ความเร็ว อัตราการเต้นหัวใจ และกำลังปั่น

ในบรรดาตัวชี้วัดดังกล่าว กำลังปั่นเป็นค่าที่สะท้อนอัตราการส่งพลังงานจากผู้ปั่นผ่านขาจานเข้าสู่ระบบขับเคลื่อนของจักรยานได้โดยตรง จึงมีประโยชน์ต่อการควบคุมการออกแรงและการวางแผนการซ้อม อย่างไรก็ตาม เครื่องวัดกำลังปั่นที่มีจำหน่ายในตลาดยังมีราคาค่อนข้างสูง และบางรุ่นมีข้อจำกัดด้านความเข้ากันได้กับชิ้นส่วนเดิมของจักรยาน โครงงานนี้จึงเสนอการพัฒนาระบบต้นแบบแบบเสริมที่ติดตั้งบนขาจานข้างเดียว โดยใช้ `strain gauge` และ `IMU` ร่วมกับ `ESP32` เพื่อคำนวณกำลังปั่นเบื้องต้น ส่งข้อมูลผ่าน `BLE` ไปยังแอปพลิเคชันบนระบบ `Android` และจัดเก็บข้อมูลลง `Firebase Cloud Firestore`

## ขอบเขตของโครงการ

- พัฒนาต้นแบบระบบตรวจวัดกำลังปั่นแบบ `single crank arm based system`
- ติดตั้ง `strain gauge` บน crank arm เดิมเพื่อวัดการเปลี่ยนรูปของวัสดุ
- ใช้ `HX711` หรือวงจรอ่านสัญญาณเทียบเท่าในการอ่านค่าสัญญาณจาก `strain gauge`
- ใช้ `IMU` รุ่น `MPU6050` เพื่อวัดความเร็วเชิงมุมของขาจาน
- ใช้ `ESP32` เป็นหน่วยประมวลผลบนตัวจักรยาน และใช้พลังงานจากแบตเตอรี่ `7.4V`
- ใช้โครงจักรยานพับ รุ่น `Fika Frappe` เป็นแพลตฟอร์มทดลองของต้นแบบ
- ใช้แอปพลิเคชันบนระบบ `Android` รับข้อมูลผ่าน `BLE` แสดงผล ติดตามเส้นทาง และจัดเก็บข้อมูลการปั่น
- ใช้ `Google Maps Flutter SDK` และ `Geolocator` สำหรับการแสดงแผนที่และการติดตามเส้นทาง
- ส่งข้อมูลจากมือถือขึ้น `Firebase Cloud Firestore` ผ่านเครือข่ายมือถือ `4G / 5G`
- ทดสอบความเสถียรของการอ่านสัญญาณ การสื่อสารผ่าน `BLE` การติดตามเส้นทาง และการบันทึกข้อมูลบนคลาวด์

## วัตถุประสงค์ของโครงการ

1. เพื่อพัฒนาต้นแบบระบบที่สามารถอ่านค่ากำลังปั่นจาก crank arm แบบเสริมได้โดยไม่ต้องเปลี่ยนชิ้นส่วนหลักของจักรยาน
2. เพื่อพัฒนาให้ `ESP32` สามารถรับข้อมูลจาก `strain gauge` และ `IMU` แล้วคำนวณกำลังปั่นเบื้องต้นบนตัวอุปกรณ์
3. เพื่อพัฒนาแอปพลิเคชันบนระบบ `Android` สำหรับรับข้อมูลผ่าน `BLE` และแสดงผลข้อมูลการปั่นแบบเรียลไทม์
4. เพื่อพัฒนาแอปพลิเคชันให้สามารถติดตามเส้นทางและบันทึกข้อมูลการปั่นขึ้นฐานข้อมูลบนคลาวด์ได้
5. เพื่อศึกษาความเป็นไปได้เชิงเทคนิค ข้อจำกัด และแนวทางต่อยอดของระบบวัดกำลังปั่นต้นทุนต่ำ

## ประโยชน์ที่คาดว่าจะได้รับ

1. ได้ต้นแบบระบบ IoT สำหรับตรวจวัดกำลังปั่นจักรยานที่สามารถต่อยอดได้ในอนาคต
2. ได้ประสบการณ์ในการบูรณาการฮาร์ดแวร์ วงจรไฟฟ้า เฟิร์มแวร์ แอปพลิเคชันบนมือถือ และฐานข้อมูลบนคลาวด์เข้าด้วยกัน
3. ได้ข้อมูลการปั่นและเส้นทางที่สามารถนำไปใช้วิเคราะห์พฤติกรรมการปั่นในภายหลังได้
4. ได้แนวทางศึกษาหลักการของเครื่องวัดกำลังปั่นในต้นทุนที่ต่ำกว่าการใช้อุปกรณ์เชิงพาณิชย์
5. สามารถใช้เป็นพื้นฐานสำหรับการพัฒนาระบบวิเคราะห์สมรรถนะการปั่นหรือผลิตภัณฑ์ที่เกี่ยวข้องต่อไป

## ระยะเวลาและแผนการปฏิบัติงาน

- ระยะเวลาดำเนินโครงการ: เดือนเมษายน 2569 ถึง เดือนพฤษภาคม 2569

| ช่วงเวลา | งานหลัก |
| --- | --- |
| เมษายน สัปดาห์ที่ 1-2 | ทบทวนความต้องการ ศึกษาข้อมูลอ้างอิง ออกแบบระบบ และจัดทำรายการอุปกรณ์ |
| เมษายน สัปดาห์ที่ 3-4 | ประกอบวงจร ติดตั้ง `strain gauge` และ `IMU` พัฒนาเฟิร์มแวร์บน `ESP32` |
| พฤษภาคม สัปดาห์ที่ 1-2 | พัฒนาแอปพลิเคชันบนมือถือ เชื่อมต่อ `BLE` ติดตามเส้นทาง และแสดงผลบนแผนที่ |
| พฤษภาคม สัปดาห์ที่ 3 | เชื่อมต่อ `Firebase Cloud Firestore` และทดสอบการส่งข้อมูลผ่านเครือข่ายมือถือ |
| พฤษภาคม สัปดาห์ที่ 4 | ทดสอบรวมระบบ ปรับแก้ต้นแบบ และจัดทำรายงาน/สไลด์นำเสนอ |

## งบประมาณ

| รายการ | จำนวน | ราคาต่อหน่วย (บาท) | ราคารวม (บาท) |
| --- | ---: | ---: | ---: |
| ESP32 Dev Board | 1 | 100 | 100 |
| Strain gauge | 4 | 12 | 48 |
| HX711 | 1 | 50 | 50 |
| MPU6050 | 1 | 90 | 90 |
| Battery 7.4V | 1 | 350 | 350 |
| PLA+ filament | 1 | 500 | 500 |
| Wiring / connectors | 1 | 200 | 200 |
| Step-down 5V | 1 | 40 | 40 |
| Firebase (prototype tier) | 1 | 0 | 0 |
| **รวม** |  |  | **1,378** |

## หมายเหตุ

- เอกสารฉบับนี้เป็นร่างใบเปิดโครงการสำหรับใช้ประกอบการเสนอหัวข้อและขอบเขตของงาน
- รายละเอียดเชิงลึกด้านการออกแบบระบบ วงจร เฟิร์มแวร์ แอปพลิเคชัน และฐานข้อมูล จะอธิบายเพิ่มเติมในรายงานโครงงานฉบับเต็ม

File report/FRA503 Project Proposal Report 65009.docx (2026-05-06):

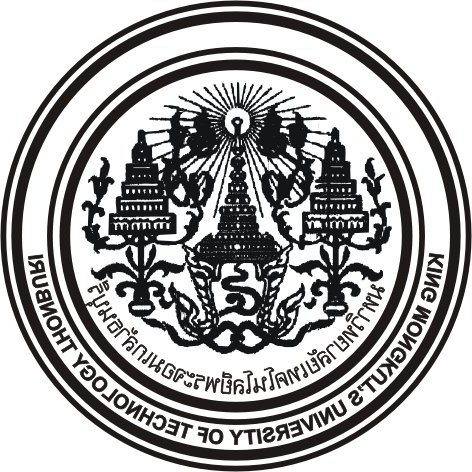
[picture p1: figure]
มหาวิทยาลัยเทคโนโลยีพระจอมเกล้าธนบุรี (มจธ.)

รายงาน

วิชา FRA503

Technopeuneurship in IoT Industry

สถาบันวิทยาการหุ่นยนต์ภาคสนาม มหาวิทยาลัยเทคโนโลยีพระจอมเกล้าธนบุรี

โครงการ

การพัฒนาระบบจักรยานอัจฉริยะสำหรับตรวจวัดและบันทึกข้อมูลการปั่นผ่าน BLE และคลาวด์

ชื่อกลุ่ม 5

ผู้ดำเนินงาน

1. นายชญานิน นาเพีย รหัสนักศึกษา 65340500009

# บทที่ 1 บทนำ

## 1.1 ที่มาและความสำคัญ

จักรยานเป็นพาหนะที่ไม่ก่อมลพิษ มีความคล่องตัว และสามารถใช้งานได้หลากหลายรูปแบบ ทั้งการเดินทางในชีวิตประจำวัน การออกกำลังกาย และการฝึกซ้อมเพื่อการแข่งขัน ผู้ใช้แต่ละกลุ่มจึงมีเป้าหมายในการปั่นและความต้องการข้อมูลที่แตกต่างกันออกไป โดยกลุ่มผู้ใช้จักรยานเป็นพาหนะในชีวิตประจำวันให้ความสำคัญกับความสะดวกและความคุ้มค่า กลุ่มผู้ใช้เพื่อการออกกำลังกายสนใจความหนักเบาของการปั่นและการพัฒนาสมรรถภาพร่างกาย ขณะที่กลุ่มผู้ใช้เพื่อการฝึกซ้อมและการแข่งขันต้องการข้อมูลเชิงลึกเพื่อใช้ควบคุมการซ้อมและวางแผนการใช้พลังงานบนเส้นทางจริง

ในการติดตามประสิทธิภาพการปั่น นักปั่นมักใช้ตัวชี้วัดหลายชนิด เช่น ระยะทาง เวลา ความเร็ว อัตราการเต้นหัวใจเฉลี่ย และกำลังปั่น อย่างไรก็ตาม หากต้องการประเมินความหนักเบาของการออกแรงอย่างใกล้เคียงการใช้พลังงานจริง กำลังปั่นซึ่งหมายถึงอัตราการส่งพลังงานจากผู้ปั่นผ่านขาจานเข้าสู่ระบบขับเคลื่อนของจักรยาน เป็นตัวชี้วัดที่สำคัญกว่าความเร็วหรืออัตราการเต้นหัวใจเพียงอย่างเดียว เนื่องจากความเร็วได้รับผลจากแรงลมและความลาดชันของเส้นทาง ส่วนอัตราการเต้นหัวใจขึ้นกับสภาพร่างกาย การพักผ่อน อุณหภูมิ และโภชนาการ ดังนั้นการทราบค่ากำลังปั่นจึงช่วยให้นักปั่นควบคุมการออกแรงของตนเองและวางแผนการซ้อมได้แม่นยำขึ้นแม้เครื่องวัดกำลังปั่นจะมีประโยชน์สูง แต่ผลิตภัณฑ์เชิงพาณิชย์ในตลาดยังมีราคาค่อนข้างสูง และหลายแบบมีข้อจำกัดเรื่องความเข้ากันได้กับชิ้นส่วนเดิมของจักรยาน ทำให้ผู้ใช้ทั่วไปและผู้พัฒนาต้นแบบเข้าถึงได้ไม่ง่าย

จากแนวคิดดังกล่าว โครงงานนี้จึงเสนอการพัฒนาระบบจักรยานอัจฉริยะในรูปแบบระบบเสริมที่ติดตั้งบนขาจานข้างเดียว โดยไม่ต้องเปลี่ยนโครงสร้างหลักของจักรยาน ใช้สเตรนเกจและไอเอ็มยูเป็นแหล่งข้อมูลหลัก ใช้ ESP32 เป็นหน่วยประมวลผลบนตัวจักรยานเพื่อคำนวณค่าเบื้องต้นและสื่อสารผ่าน Bluetooth Low Energy (BLE) ไปยังแอปมือถือ จากนั้นแอปมือถือจะทำหน้าที่แสดงผล บันทึกเส้นทาง และส่งข้อมูลขึ้นฐานข้อมูลบนคลาวด์ผ่านเครือข่ายมือถือ

## 1.2 ศึกษาคู่แข่งที่มีขาย

โดยทั่วไป watt meter ในจักรยานสามารถแบ่งได้เป็น 4 ประเภทหลัก ได้แก่ pedal based, crank arm based, spider based และ crankset based ซึ่งแต่ละประเภทมีจุดเด่นและข้อจำกัดต่างกัน เช่น pedal based ติดตั้งง่ายแต่ขึ้นกับระบบบันไดเดิม, spider based วัดกำลังรวมได้ดีแต่ซับซ้อนด้านการติดตั้ง, และ crankset based มีความครบในตัวแต่มีราคาสูงที่สุด

ตารางต่อไปนี้สรุปข้อดีและข้อจำกัดของ watt meter แต่ละประเภทในมุมที่เกี่ยวข้องกับการพัฒนาต้นแบบ

ประเภท | ข้อดี | ข้อจำกัด
Pedal based | ติดตั้งและย้ายข้ามจักรยานได้ค่อนข้างง่าย, วัดแรงจากตำแหน่งที่ผู้ปั่นออกแรงโดยตรง | ต้องเลือกให้เข้ากับระบบบันไดและรองเท้า, โครงสร้างเชิงกลซับซ้อนและรับแรงกระแทกสูง
Crank arm based | ต้นทุนต่ำกว่า spider/crankset based, เหมาะกับแนวคิด add-on, ติดตั้ง strain gauge และพัฒนาต้นแบบได้ง่าย | ส่วนใหญ่เป็นการวัดแบบข้างเดียว, ความแม่นยำขึ้นกับการติดตั้งและการคาลิเบรต
Spider based | วัดกำลังรวมของระบบขาจานได้ดี, เหมาะกับการใช้งานเชิงสมรรถนะ | การติดตั้งซับซ้อน, ขึ้นกับความเข้ากันได้ของชุดขาจาน, ต้นทุนสูง
Crankset based | รวมระบบไว้ในชุดเดียว, ความเรียบร้อยและความพร้อมใช้งานสูง | ราคาสูงที่สุด, ต้องเปลี่ยนชุดขาจานทั้งชุด, ไม่เหมาะกับแนวคิดต้นแบบต้นทุนต่ำ

สำหรับโครงงานนี้เลือกโฟกัส crank arm based เนื่องจากสอดคล้องกับแนวคิด add-on system ที่ติดตั้งบน crank arm เดิมได้โดยไม่ต้องเปลี่ยนชิ้นส่วนหลักของจักรยาน มีต้นทุนต่ำกว่า spider/crankset based และเหมาะกับการพัฒนาต้นแบบด้วย strain gauge + IMU + ESP32 มากที่สุด ดังนั้นตารางเปรียบเทียบด้านล่างจึงคัดข้อมูลเฉพาะ crank arm power meter หรือ left crank arm power meter เพื่อให้เทียบกับแนวทางของโครงงานได้ตรงที่สุด

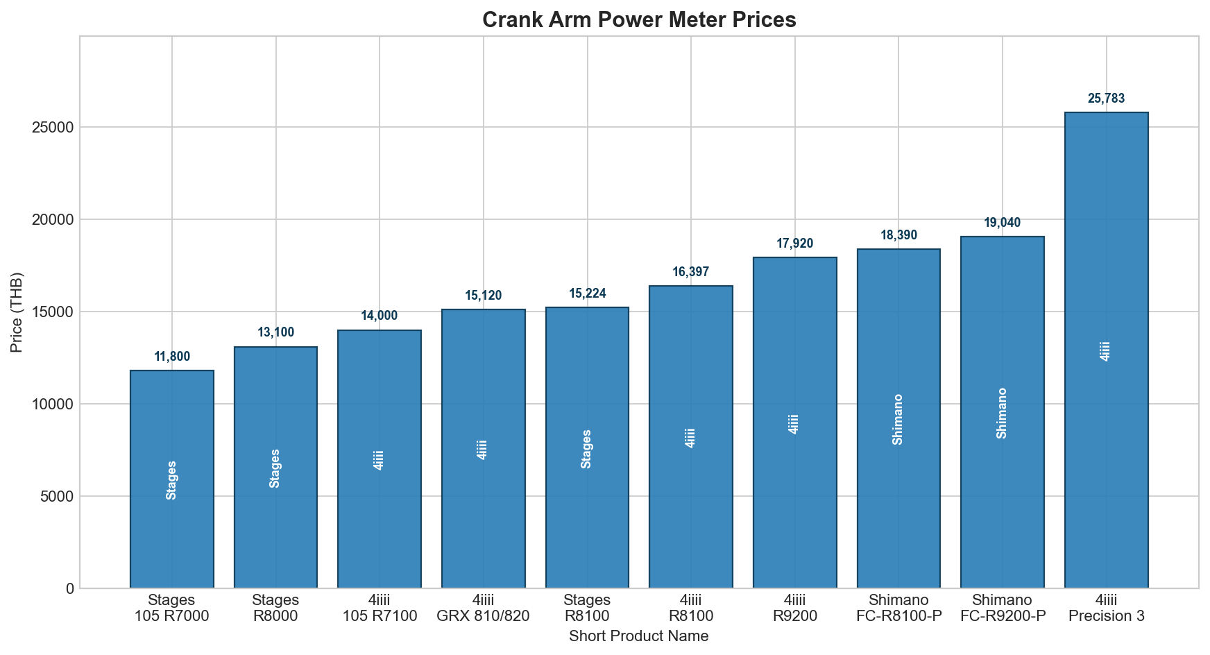
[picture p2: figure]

จากตัวอย่าง 10 รายการที่คัดให้เหลือเฉพาะ crank arm พบว่าช่วงราคาที่พบบ่อยอยู่ราว 11,800-19,040 บาท และมีบางรุ่นนำเข้าที่สูงขึ้นไปถึง 25,783 บาท ภาพนี้ทำให้เห็นชัดว่าต่อให้เปรียบเทียบเฉพาะกลุ่ม crank arm ซึ่งเป็นกลุ่มที่ใกล้กับโครงงานที่สุด ราคาตลาดส่วยใหญ่ค่อนข้างสูง

ข้อแตกต่างของโครงงานนี้เมื่อเทียบกับสินค้าในตลาดคือ:

1. เป็น add-on sensing system ที่ติดตั้งบน crank arm เดิม โดยไม่ต้องเปลี่ยนโครงสร้างหลักของจักรยาน
2. ใช้ ESP32 + smartphone + cloud backup เป็นสถาปัตยกรรมหลัก จึงเน้นความง่ายในการทดลองและการต่อยอดข้อมูล
3. เปิดโอกาสให้ปรับแต่งเฟิร์มแวร์ ตรรกะของแอป และลำดับการไหลของข้อมูลได้เอง
4. มีข้อจำกัดด้านความแม่นยำและความทนทานมากกว่าระบบ commercial จึงต้องพึ่งการติดตั้งและ calibration ที่เหมาะสม

## 1.3 วัตถุประสงค์ของผลิตภัณฑ์/สิ่งที่ผลิตภัณฑ์ทำได้ (functions)

1. พัฒนาต้นแบบระบบที่สามารถอ่านค่ากำลังปั่นจาก crank arm แบบ add-on โดยไม่มีการถอดเปลี่ยนชิ้นส่วนหลักของจักรยาน
2. พัฒนาให้ ESP32 สามารถรับข้อมูลจาก strain gauge และ IMU แล้วสื่อสารข้อมูลผ่าน BLE ไปยังแอปมือถือ
3. พัฒนาแอปมือถือบนระบบ Android สำหรับแสดงผลค่ากำลังปั่นและข้อมูลการปั่นแบบเรียลไทม์
4. พัฒนาแอปมือถือให้สามารถส่งข้อมูลขึ้น cloud database เพื่อเก็บประวัติการปั่นได้
5. ศึกษาความเป็นไปได้เชิงเทคนิค ข้อจำกัด และความเสี่ยงของระบบก่อนพัฒนาต้นแบบจริง

## 1.4 ขอบเขตที่ผลิตภัณฑ์ทำได้

1. ชิ้นงานเป็น single crank arm based
2. โครงจักรยานที่ใช้ในการทดลองเป็น โครงจักรยานพับ รุ่น Fika Frappe
3. ESP32 จะถูกติดตั้งที่จักรยาน และใช้พลังงานจาก แบตเตอรี่
4. การประมาณ power ใช้แหล่งข้อมูลจาก strain gauge และ IMU
5. แอพพลิเคชันบนระบบ android

## 1.5 ประโยชน์ที่คาดว่าจะได้รับ เช่นจากธุรกิจ

1. ได้ต้นแบบ IoT สำหรับการวัดกำลังปั่นที่ต้นทุนต่ำและต่อยอดได้
2. ได้สถาปัตยกรรมที่เชื่อม อุปกรณ์ -> แอปมือถือ -> คลาวด์ อย่างครบวงจร
3. ได้ฐานข้อมูลประวัติการปั่นที่นำไปใช้วิเคราะห์พฤติกรรมการปั่นภายหลังได้
4. ช่วยลดต้นทุนในการศึกษาหลักการของ power meter เทียบกับการซื้อผลิตภัณฑ์เชิงพาณิชย์โดยตรง
5. เหมาะเป็นฐานต่อยอดสำหรับงานวิจัย งานเรียน หรือการพัฒนาผลิตภัณฑ์ sports analytics

## 1.6 แผนดำเนินงาน

หน้าที่ | เมษายน 2569 | | พฤษภาคม 2569
| w3 | w4 | w1 | w2
สั่งของ
พัฒนาแอพพลิเคชั่นมือถือ
ออกแบบการทดลอง
ออกแบบ วงจรไฟฟ้า + ทดสอบ
ออกแบบ กล่องคอนโทรล
ติดตั้ง strain gauge + calibrate
รวมระบบ
ทำการทดลอง และสรุปผล
ทำงานงานฉบับสมบูรณ์

# บทที่ 2 วิธีการดำเนินการ

สถาปัตยกรรมของระบบแบ่งเป็น 5 ชั้น ได้แก่ device layer, communication layer, service layer, application layer และ cloud layer โดยฝั่งจักรยานจะมีเซนเซอร์และวงจรอ่านสัญญาณติดตั้งบน crank arm เดิม ข้อมูลจาก strain gauge และ gyroscope จะถูกส่งเข้า ESP32 เพื่อทำ edge power estimation แล้วแพ็กเป็น telemetry packet ส่งผ่าน BLE ไปยังแอปมือถือ หลังจากนั้นมือถือจะรับข้อมูลกำลังปั่น ควบคู่กับการอ่านตำแหน่งจาก GPS เพื่อนำมาสร้างเส้นทาง แสดงผลบนแผนที่ และจัดเก็บเป็นชุดข้อมูลการปั่นก่อนส่งขึ้น Firebase ผ่านเครือข่าย 4G / 5G

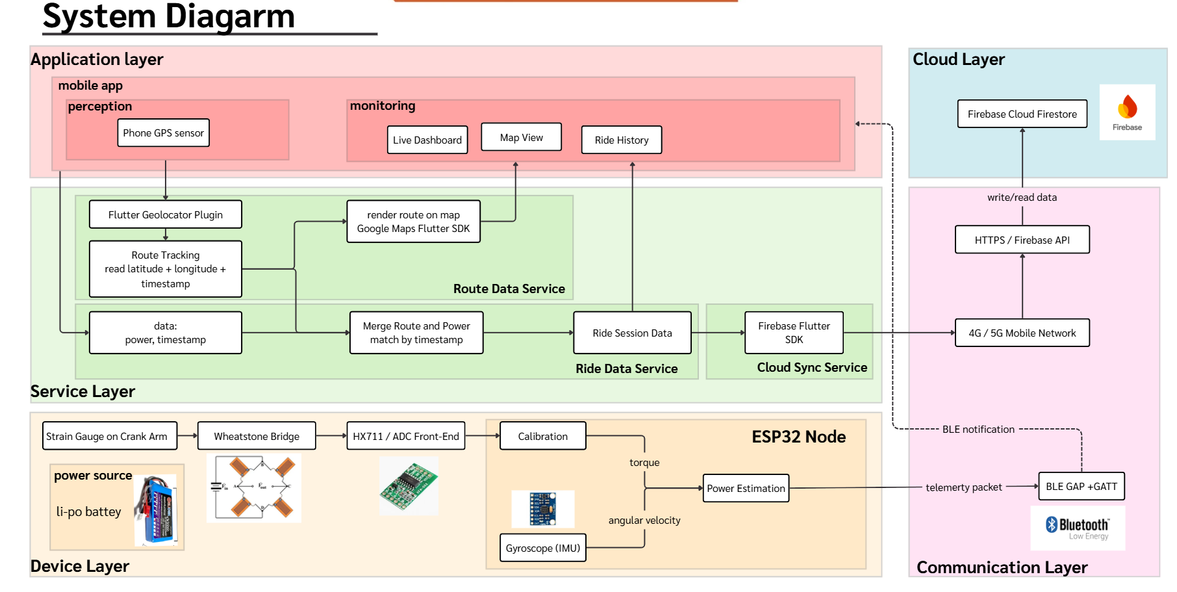
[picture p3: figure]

รูปที่ ... แสดงแผนผังระบบของโครงงานนี้

## 2.1 การออกแบบฮาร์ดแวร์

## 2.2 การออกแบบทางไฟฟ้า

## 2.3 การพัฒนาเฟิร์มแวร์

## 2.4 การพัฒนาแอปพลิเคชันบนมือถือ

## 2.5 การจัดเก็บข้อมูลบนคลาวด์

# บทที่ 3 วิธีการทดสอบ ผลและวิเคราะห์การทดสอบ

- อธิบายวิธีการทดสอบ
- อธิบายผล และวิเคราะห์การทดสอบ ต้นแบบ (prototype) ที่ได้พัฒนามา

# บทที่ 4 สรุปผลการดำเนินงาน และข้อเสนอแนะ การปรับปรุงต้นแบบ

# บทที่ 5 งบการเงิน

ลำดับ | รายการ | จำนวน | ราคาต่อหน่วย | ราคา (บาท)
1 | Strain gauge | 4 | 12.5 | 50
2 | HX711 | 1 | 50 | 50
3 | MPU6050 | 1 | 90 | 90
4 | Battery 7.4v | 1 | 350 | 350
5 | PLA-plus-filament | 1 | 500 | 500
6 | Wiring / connectors /switch | 1 | 300 | 300
7 | step-down-5V | 1 | 40 | 40
8 | กาว epoxy | 1 | 120 | 120
รวม | | | | 1500

# อ้างอิง

1. Steve Jarvis, “Homemade Power Meter,” available: https://imateapot.dev/homemade-power-meter/ (accessed 2026-04-09).
2. YouTube reference provided by project owner, available: https://www.youtube.com/watch?v=CRa9djnZRu0&t=11s (accessed 2026-04-09).
3. Espressif, “Bluetooth API - ESP32,” available: https://docs.espressif.com/projects/esp-idf/en/stable/esp32/api-reference/bluetooth/index.html (accessed 2026-04-09).
4. Espressif, “GATT Server API - ESP32,” available: https://docs.espressif.com/projects/esp-idf/en/stable/esp32/api-reference/bluetooth/esp_gatts.html (accessed 2026-04-09).
5. Firebase, “Add Firebase to your Flutter app,” available: https://firebase.google.com/docs/flutter/setup (accessed 2026-04-09).
6. Firebase, “Cloud Firestore,” available: https://firebase.google.com/products/firestore (accessed 2026-04-09).
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

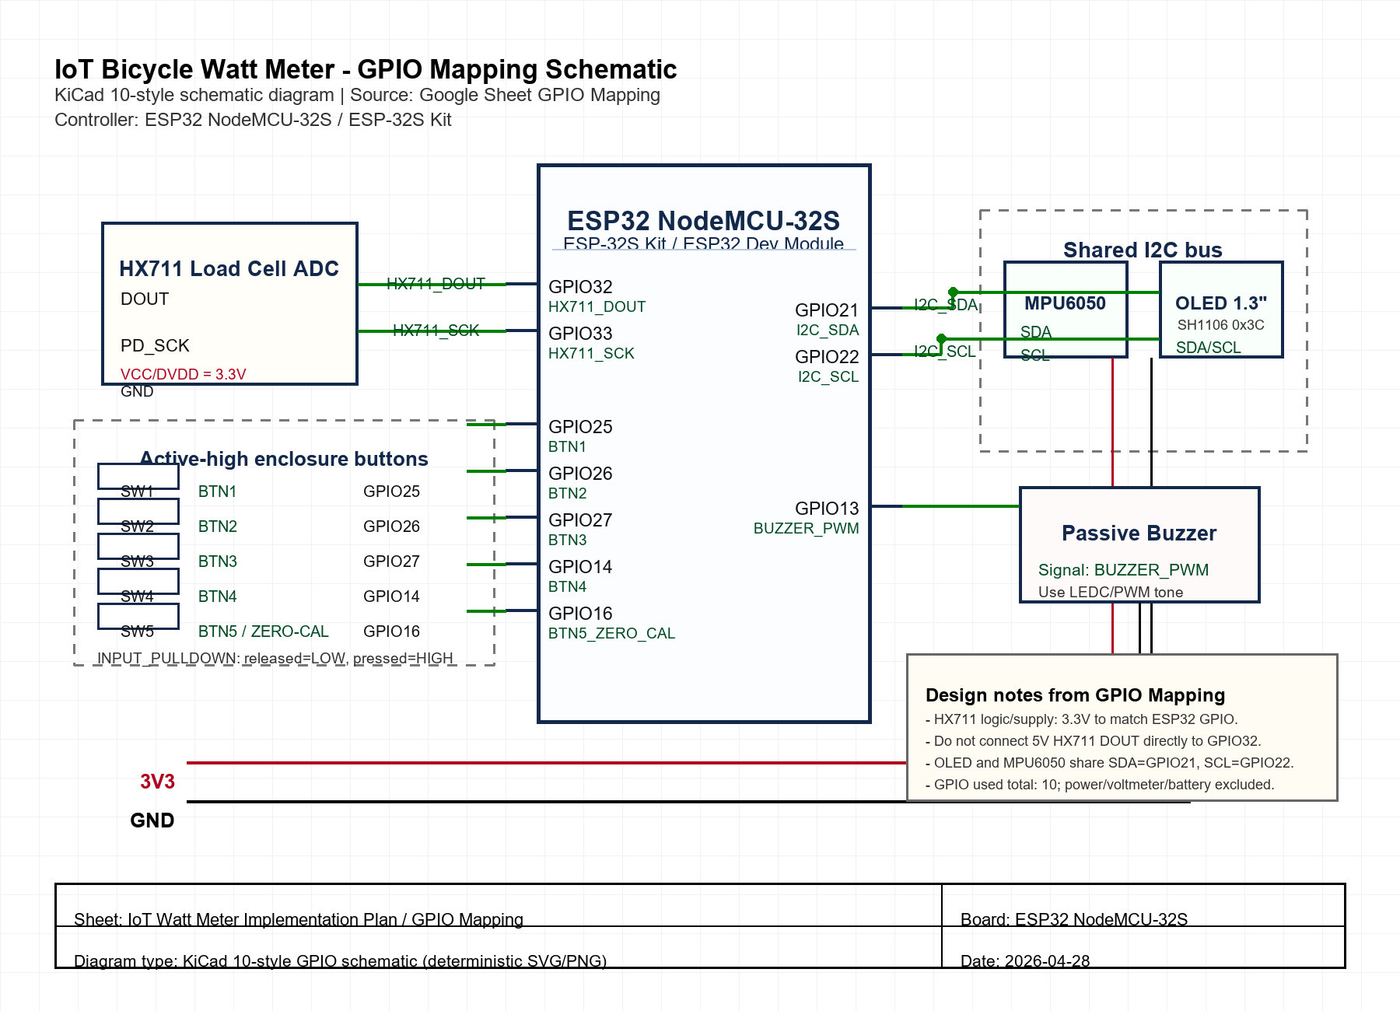
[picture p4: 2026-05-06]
diagrams/gpio_mapping_schematic_kicad10.png

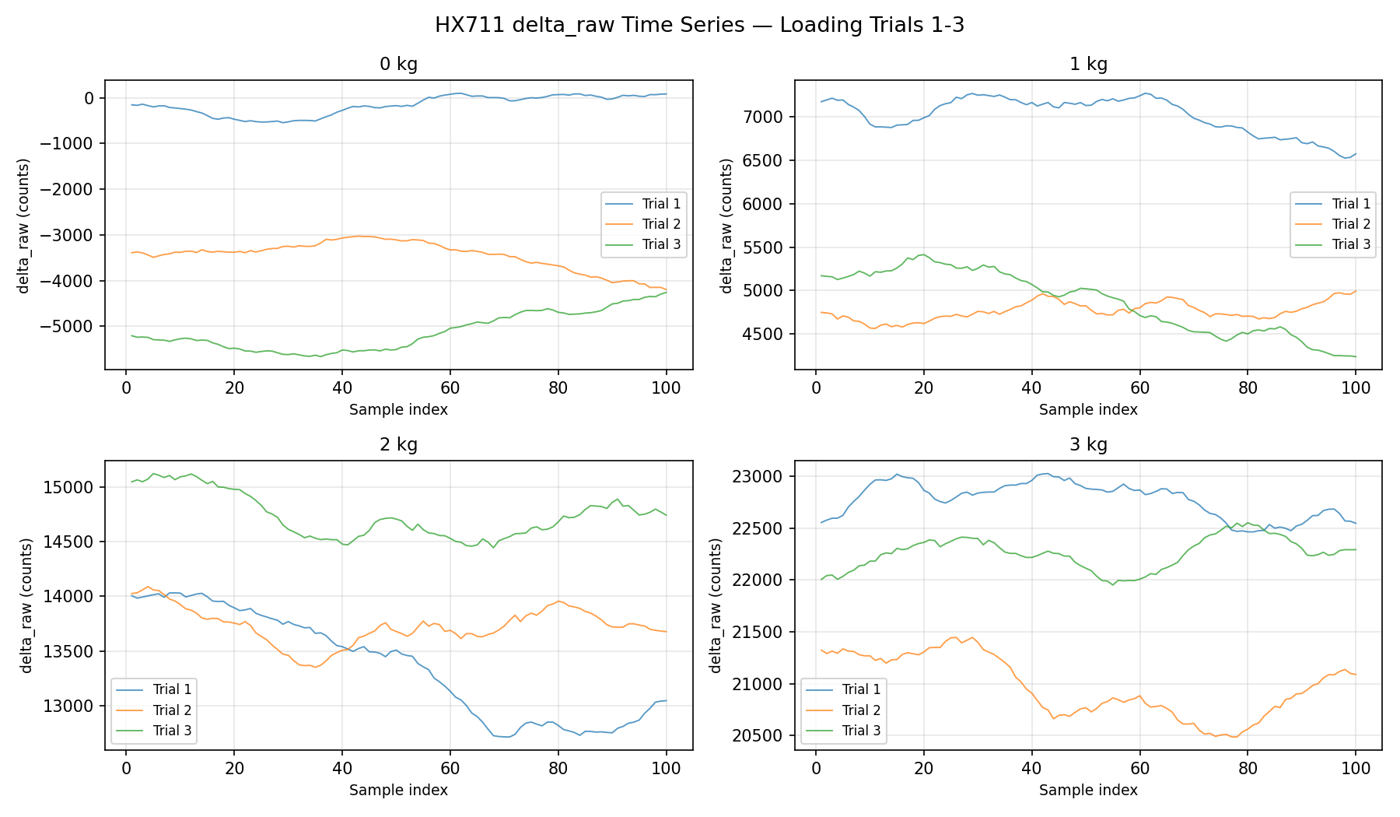
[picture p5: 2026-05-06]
images/hx711_delta_raw_timeseries.png

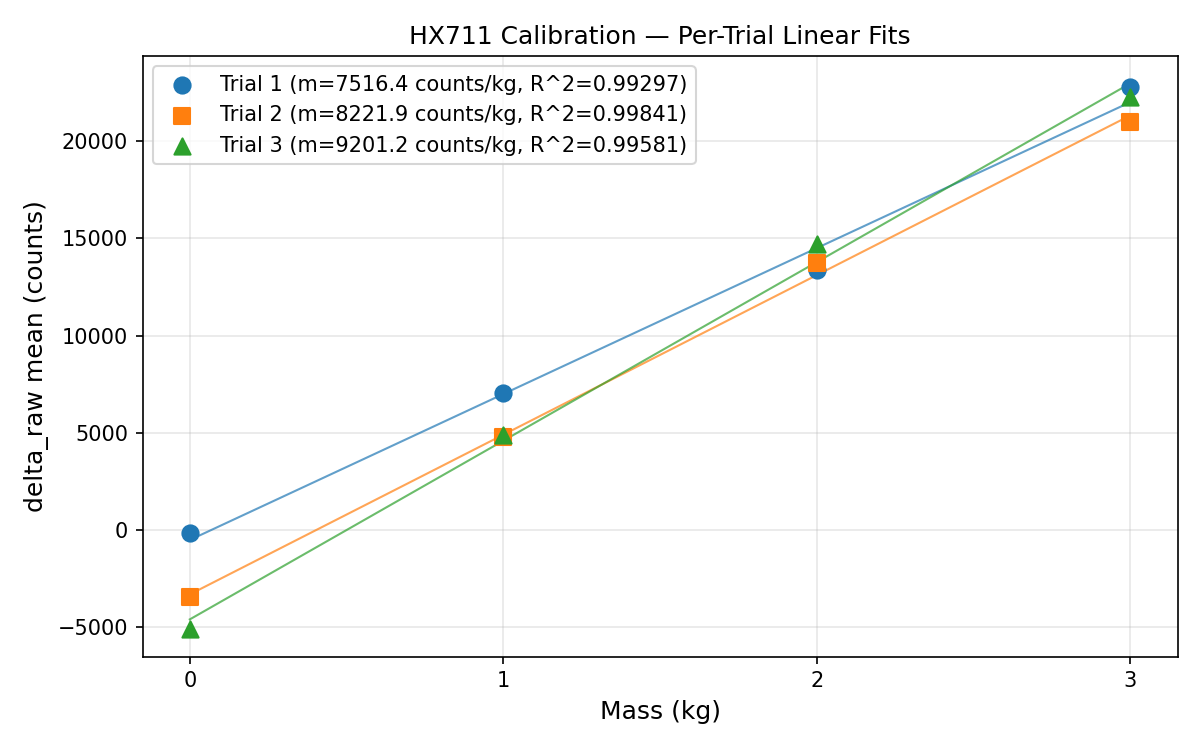
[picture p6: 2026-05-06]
images/hx711_per_trial_fits.png

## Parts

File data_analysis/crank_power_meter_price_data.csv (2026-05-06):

id | brand | product_name | short_label | category | price_thb | source_url | source_note | access_date
1 | Stages | Stages Gen 3 Shimano 105 R7000 Left Crank Arm | Stages 105 R7000 | left_crank_arm | 11800 | https://www.priceza.com/s/%E0%B8%A3%E0%B8%B2%E0%B8%84%E0%B8%B2/%E0%B8%82%E0%B8%B2%E0%B8%88%E0%B8%B2%E0%B8%99105 | Priceza Thailand listing for Stages Gen 3 left crank arm on Shimano 105 R7000 | 2026-04-09
2 | Stages | Stages Gen 3 Shimano Ultegra R8000 Left Crank Arm | Stages R8000 | left_crank_arm | 13100 | https://www.priceza.com/s/%E0%B8%A3%E0%B8%B2%E0%B8%84%E0%B8%B2/%E0%B8%82%E0%B8%B2%E0%B8%A7%E0%B8%B1%E0%B8%95%E0%B8%95%E0%B9%8Cstages-ultegra-r8000 | Priceza Thailand listing for Stages Gen 3 left crank arm on Shimano Ultegra R8000 | 2026-04-09
3 | Stages | Stages Gen 3 Shimano Ultegra R8100 Left Crank Arm | Stages R8100 | left_crank_arm | 15224 | https://www.priceza.com/s/%E0%B8%A3%E0%B8%B2%E0%B8%84%E0%B8%B2/%E0%B8%82%E0%B8%B2%E0%B8%88%E0%B8%B2%E0%B8%99-shimano | Priceza Thailand listing for Stages Gen 3 left crank arm on Shimano Ultegra R8100 | 2026-04-09
4 | 4iiii | 4iiii Precision 3 Powermeter Ride Ready Left-Side | 4iiii Precision 3 | left_crank_arm | 25783 | https://www.ubuy.co.th/th/product/IEUP1SR62-4iiii-precision-3-powermeter-ride-ready-left-side-ant-performance-meter-for-outdoor-indoor-cycling-measures-watts-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 | Ubuy Thailand listing for 4iiii left-side crank arm power meter | 2026-04-09
5 | 4iiii | 4iiii Precision 3+ 105 R7100 Left Arm Only | 4iiii 105 R7100 | left_crank_arm | 14000 | https://ccache.cc/products/4iiii-precision-3-power-meter-left-arm-only-105-r7100 | CCACHE retailer quote in AUD converted to THB at approximately 22.4 THB/AUD | 2026-04-09
6 | 4iiii | 4iiii Precision 3+ GRX 810/820 Left Arm Only | 4iiii GRX 810/820 | left_crank_arm | 15120 | https://ccache.cc/products/4iiii-precision-3-power-meter-left-arm-only-grx-810-820 | CCACHE retailer quote in AUD converted to THB at approximately 22.4 THB/AUD | 2026-04-09
7 | 4iiii | 4iiii Precision 3+ Ultegra R8100 Left Arm Only | 4iiii R8100 | left_crank_arm | 16397 | https://ccache.cc/products/4iiii-precision-3-power-meter-left-arm-only-ultegra-r8100 | CCACHE retailer quote in AUD converted to THB at approximately 22.4 THB/AUD | 2026-04-09
8 | 4iiii | 4iiii Precision 3+ Dura-Ace R9200 Left Arm Only | 4iiii R9200 | left_crank_arm | 17920 | https://ccache.cc/products/4iiii-precision-3-power-meter-left-arm-only-dura-ace-r9200 | CCACHE product page quote 799.99 AUD converted to THB at approximately 22.4 THB/AUD | 2026-04-09
9 | Shimano | Shimano FC-R8100-P Left Hand Crank Arm Unit 172.5mm | Shimano FC-R8100-P | left_crank_arm | 18390 | https://ccache.cc/products/shimano-fc-r8100-p-left-hand-crank-arm-unit-172-5mm | CCACHE retailer quote in AUD converted to THB at approximately 22.4 THB/AUD | 2026-04-09
10 | Shimano | Shimano FC-R9200-P Left Hand Crank Arm Unit | Shimano FC-R9200-P | left_crank_arm | 19040 | https://ccache.cc/products/shimano-dura-ace-fc-r9200-p-left-hand-crank-arm-powermeter | CCACHE retailer quote in AUD converted to THB at approximately 22.4 THB/AUD | 2026-04-09

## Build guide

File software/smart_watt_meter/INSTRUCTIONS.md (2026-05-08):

# Smart Watt-Meter — Run Instructions

## Prerequisites
- Flutter installed (stable channel)
- Android Studio + Pixel 4a emulator
- Android SDK Platform 34 installed

---

## 1. Start the Emulator

Open **Android Studio** → **Device Manager** → Start **Pixel 4a**

Or via terminal:
```bash
flutter emulators --launch Pixel_4a
```

---

## 2. Run the App

```bash
cd "C:\Users\Acer\Desktop\IoT\iot_bicycle_wattMeter_project\software\smart_watt_meter"
flutter run -d emulator-5554
```

Wait ~1-2 minutes for the first build (Gradle downloads dependencies).  
Subsequent runs are much faster.

---

## 3. Hot Reload / Hot Restart

While the app is running in terminal:

| Key | Action |
|-----|---|
| `r` | Hot reload (apply code changes instantly) |
| `R` | Hot restart (restart app, resets state) |
| `q` | Quit |

---

## 4. What Works Right Now

| Feature | Status |
|---|---|
| Device screen (BLE scan UI) | ✅ Works |
| Power Dashboard screen | ✅ Works |
| Map screen | ✅ Works (placeholder — no Google Maps key yet) |
| History screen | ✅ Works (empty until Firebase is set up) |
| BLE connect to ESP32 | ✅ Ready (needs real ESP32 device) |
| Firebase upload | ❌ Needs `google-services.json` |
| Google Maps route | ❌ Needs Maps API key |

---

## 5. Set Up Firebase (for History / Cloud Sync)

### Step 1 — Create Firebase project
1. Go to [Firebase Console](https://console.firebase.google.com/)
2. Create project → Enable **Firestore** (test mode) + **Anonymous Auth**

### Step 2 — Connect to app
```bash
# Install FlutterFire CLI (once)
dart pub global activate flutterfire_cli

# In the project folder
cd "C:\Users\Acer\Desktop\IoT\iot_bicycle_wattMeter_project\software\smart_watt_meter"
flutterfire configure
```
This generates `lib/firebase_options.dart` and downloads `google-services.json` automatically.

### Step 3 — Update main.dart
Replace:
```dart
await Firebase.initializeApp();
```
With:
```dart
await Firebase.initializeApp(options: DefaultFirebaseOptions.currentPlatform);
```
And add import:
```dart
import 'firebase_options.dart';
```

---

## 6. Set Up Google Maps (for Map screen)

1. Go to [Google Cloud Console](https://console.cloud.google.com/)
2. Enable **Maps SDK for Android**
3. Create an API key
4. Open `android/app/src/main/AndroidManifest.xml`
5. Replace `YOUR_GOOGLE_MAPS_API_KEY` with your key
6. Uncomment the import in `lib/screens/map_screen.dart` and restore the `GoogleMap` widget

---

## Project Structure

```
lib/
├── main.dart                  ← App entry point + navigation shell
├── models/
│   ├── ride_sample.dart       ← Single 1Hz telemetry data point
│   └── ride_summary.dart      ← Ride metadata (avg power, distance, etc.)
├── services/
│   ├── ble_service.dart       ← BLE scan, connect, GATT notify
│   ├── gps_service.dart       ← Phone GPS tracking + distance calc
│   ├── firestore_service.dart ← Firebase upload + ride history fetch
│   └── ride_session_service.dart ← Merges BLE + GPS, manages recording
├── providers/
│   └── app_state.dart         ← Global state (Provider)
├── screens/
│   ├── device_screen.dart     ← Tab 1: BLE scan & connect
│   ├── power_dashboard_screen.dart ← Tab 2: Live power + start/stop
│   ├── map_screen.dart        ← Tab 3: GPS route map
│   └── history_screen.dart    ← Tab 4: Past rides list
└── widgets/
    └── power_chart.dart       ← 60-second bar chart widget
```

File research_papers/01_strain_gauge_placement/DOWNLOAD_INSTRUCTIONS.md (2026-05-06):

# 📍 01_strain_gauge_placement
กลุ่ม: ตำแหน่งการติด strain gauge บน crank arm

---

## Paper 1 — Balbinot et al. 2014 ⭐⭐⭐⭐⭐
**ชื่อ:** A New Crank Arm-Based Load Cell for the 3D Analysis of the Force Applied by a Cyclist
**ทำไมอยู่ที่นี่:** ใช้ SolidWorks FEA หา strain peak zones ก่อนติด gauge — เป็น paper ที่ให้ FEA map ของตำแหน่งละเอียดที่สุด
**ลิงก์ (free full text):**
- https://pmc.ncbi.nlm.nih.gov/articles/PMC4299046/
- https://www.mdpi.com/1424-8220/14/12/22921
**วิธีโหลด:** กด "Download PDF" ที่มุมขวาบนของ MDPI หรือ "PDF" ที่ PubMed Central
**บันทึกเป็น:** `Balbinot_2014_CrankArm_LoadCell.pdf`

---

## Paper 2 — Gutiérrez-Moizant et al. 2020 ⭐⭐⭐⭐⭐
**ชื่อ:** Validation and Improvement of a Bicycle Crank Arm Based in Numerical Simulation and Uncertainty Quantification
**ทำไมอยู่ที่นี่:** ใช้ Abaqus FEA หา high-stress zones และติด rosette gauges ตามนั้น — มี uncertainty quantification ละเอียดที่สุดในวรรณกรรม
**ลิงก์ (free full text):**
- https://pmc.ncbi.nlm.nih.gov/articles/PMC7180959/
- https://www.mdpi.com/1424-8220/20/7/1814
**วิธีโหลด:** กด "Download PDF" ที่ MDPI หรือ PMC
**บันทึกเป็น:** `Gutierrez-Moizant_2020_FEA_Validation.pdf`

---

## Paper 3 — Design and Engineering of an Accurate Bicycle Power Meter (2014)
**ชื่อ:** Design and Engineering of an Accurate Bicycle Power Meter
**ทำไมอยู่ที่นี่:** ใช้ FE optimisation ของ NDS crank หา "neutral zone below spindle" และอธิบายชัดว่าทำไม near-BB และ near-pedal ถึงแย่
**ลิงก์:**
- https://www.researchgate.net/publication/303517617_Design_and_Engineering_of_an_Accurate_Bicycle_Power_Meter
**วิธีโหลด:** กด "Request full-text" หรือ log in ResearchGate แล้วกด "Download"
**บันทึกเป็น:** `DesignEngineering_2014_AccuratePowerMeter.pdf`

---

## จุดสำคัญที่ paper กลุ่มนี้ agree ร่วมกัน
- ✅ ติดที่ **mid-span บน inner face** ของ left crank arm
- ❌ หลีกเลี่ยง near-BB (stress concentration + mixed loading)
- ⚠  หลีกเลี่ยง near-pedal (pedal offset → axial crosstalk)

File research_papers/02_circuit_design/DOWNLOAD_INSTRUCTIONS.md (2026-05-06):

# ⚡ 02_circuit_design
กลุ่ม: การออกแบบวงจรไฟฟ้า (signal conditioning, ADC, MCU, BLE)

---

## Paper 1 — Analog Devices / Cassidy 2021 ⭐⭐⭐⭐⭐ (most complete)
**ชื่อ:** How to Design a Low Power Highly Accurate Bicycle Power Meter
**ทำไมอยู่ที่นี่:** reference design ที่ครบที่สุด — มี part numbers, schematic, power budget ครบ
**สิ่งที่ได้:** zero-drift in-amp → MAX11108 SAR ADC → MAX32666 ARM+BLE, 760 µA @ 3V, ~296h บน CR2032
**ลิงก์ (free):**
- https://www.analog.com/en/resources/analog-dialogue/articles/low-power-highly-accurate-bicycle-power-meter.html
**วิธีโหลด:** กด Ctrl+P → Save as PDF หรือใช้ browser print-to-PDF
**บันทึกเป็น:** `AnalogDevices_2021_PowerMeter_Design.pdf`

---

## Paper 2 — Pigatto et al. 2016 ⭐⭐⭐⭐
**ชื่อ:** A new crank arm based load cell, with built-in conditioning circuit and strain gages, to measure the components of the force applied by a cyclist
**ทำไมอยู่ที่นี่:** แสดงวิธี embed วงจร SMD conditioning ไว้ในช่องที่ machined ภายใน crank arm เอง
**สิ่งที่ได้:** on-arm PCB, on-chip DAC, linearity <0.6%, natural freq >136Hz
**ลิงก์:**
- https://ieeexplore.ieee.org/abstract/document/7591113  (ต้อง IEEE account)
- https://pubmed.ncbi.nlm.nih.gov/28268718/
- https://www.researchgate.net/publication/309340598  (request full-text)
**วิธีโหลด:** IEEE Xplore — log in ด้วย institutional access หรือ request ที่ ResearchGate
**บันทึกเป็น:** `Pigatto_2016_BuiltIn_Conditioning_Circuit.pdf`

---

## Paper 3 — Balbinot et al. 2014 ⭐⭐⭐⭐
**ชื่อ:** A New Crank Arm-Based Load Cell for the 3D Analysis of the Force Applied by a Cyclist
**ทำไมอยู่ที่นี่:** อธิบาย custom SMD PCB ติดตรง crank structure, Wheatstone bridge 3 แกน, Bluetooth + SD logging
**หมายเหตุ:** paper เดียวกับ folder 01 แต่ดูในมุม circuit design
**ลิงก์ (free full text):**
- https://pmc.ncbi.nlm.nih.gov/articles/PMC4299046/
**บันทึกเป็น:** `Balbinot_2014_CrankArm_LoadCell.pdf` (ถ้ามีอยู่แล้วใน folder อื่น ไม่ต้องโหลดซ้ำ)

---

## Paper 4 — Cornell ECE 4760 (Eggers & Carroll 2014)
**ชื่อ:** Bike Dash — Crank-mounted Power Meter
**ทำไมอยู่ที่นี่:** published schematic ชัดเจน, อธิบาย in-amp gain ≈200 และ PIC32 pipeline — ดีสำหรับ learning circuit fundamentals
**ลิงก์ (free):**
- https://people.ece.cornell.edu/land/courses/ece4760/FinalProjects/f2014/mje56_bwc65/mje56_bwc65/
**วิธีโหลด:** Ctrl+P → Save as PDF (รวม schematic images)
**บันทึกเป็น:** `Cornell_ECE4760_2014_BikeDash.pdf`

---

## Components ที่ควรรู้จากกลุ่มนี้
| ชิ้นส่วน | ตัวเลือก budget | ตัวเลือก precision |
|---|---|---|
| ADC/In-amp | HX711 (24-bit, $1) | MAX11108 + zero-drift in-amp |
| MCU | Arduino Nano 33 BLE | MAX32666 Cortex-M4 |
| Bridge config | Half-bridge + 2×R dummy | Full-bridge 4 gauges |
| Protocol | BLE CPS profile | ANT+ / proprietary |

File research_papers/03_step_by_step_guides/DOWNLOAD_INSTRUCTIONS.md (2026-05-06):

# 🎯 03_step_by_step_guides
กลุ่ม: Paper ที่มี step-by-step guide ครบ — ใกล้เคียง project ของคุณที่สุด
ข้อกำหนด: IMU + strain gauge เท่านั้น, mid-span half-bridge บน inner face ของ left crank

---

## Paper 1 — Blommaert et al. 2025 ⭐⭐⭐⭐⭐ (PRIORITY #1 — อ่านก่อนทุก paper)
**ชื่อ:** Experimental physics with a homemade cycling power meter: Development and characterization
**ทำไมอยู่ที่นี่:** เป็น paper เดียวที่ match โปรเจคของคุณ 100% — ใช้ IMU + strain gauge เท่านั้น, half-bridge บน left crank inner face, HX711, Arduino Nano 33 BLE, BLE CPS profile และมี step-by-step สำหรับนักศึกษา
**สิ่งที่ได้:**
  - ขั้นตอนติด strain gauge ระดับ student lab
  - วิธี calibrate ด้วย known weights
  - การใช้ on-board IMU (LSM-class gyro) วัด cadence และ ω
  - validate กับ commercial power meter
**DOI:** 10.1119/5.0270674
**ลิงก์:**
- HAL (open access — FREE): https://hal.science/hal-05125140v1
- AIP Publishing (อาจต้อง subscription): https://pubs.aip.org/aapt/ajp/article/93/7/589/3349930
- ResearchGate: https://www.researchgate.net/publication/393244965
**วิธีโหลด:** ไปที่ลิงก์ HAL → กด "Télécharger le fichier" (Download file) — ฟรีทันที
**บันทึกเป็น:** `Blommaert_2025_Homemade_PowerMeter_PRIORITY.pdf`

---

## Paper 2 — Analog Devices / Cassidy 2021 ⭐⭐⭐⭐⭐ (PRIORITY #2 — engineering reference)
**ชื่อ:** How to Design a Low Power Highly Accurate Bicycle Power Meter
**ทำไมอยู่ที่นี่:** ให้ engineering-level guide ครบ รวมถึง IMU role ใน power calculation และ วิธีหา ω จาก strain periodicity เมื่อ IMU ปิด
**สิ่งที่ได้:**
  - Half-bridge placement บน left crank mid-span
  - Full signal chain: bridge → in-amp → ADC → MCU → BLE
  - IMU integration สำหรับ cadence และ crank angle
  - Power budget ละเอียด (760 µA @ 3V)
**ลิงก์ (free):**
- https://www.analog.com/en/resources/analog-dialogue/articles/low-power-highly-accurate-bicycle-power-meter.html
**วิธีโหลด:** Ctrl+P → Save as PDF
**บันทึกเป็น:** `AnalogDevices_2021_PowerMeter_Design.pdf`

---

## Paper 3 — Martín-Sosa et al. 2021 ⭐⭐⭐⭐ (IMU drift correction reference)
**ชื่อ:** Design and Validation of a Device Attached to a Conventional Bicycle to Measure the Three-Dimensional Forces Applied to a Pedal
**ทำไมอยู่ที่นี่:** ใช้ MPU6050 + strain gauge + Arduino Nano stack เหมือนกับที่คุณจะทำ — ระบุวิธีแก้ IMU gyro drift ด้วย Hall-effect sensor reset ทุก 1 รอบ ซึ่งเป็นปัญหาสำคัญที่ต้องแก้
**สิ่งที่ได้:**
  - MPU6050 I²C wiring กับ Arduino Nano
  - วิธี reset cumulative gyro drift ทุก revolution
  - microdeformation tables ต่อ 98.1N reference load
**ลิงก์ (free full text):**
- https://pmc.ncbi.nlm.nih.gov/articles/PMC8272058/
- https://www.mdpi.com/1424-8220/21/13/4590
**วิธีโหลด:** กด "Download PDF" ที่ MDPI หรือ PMC
**บันทึกเป็น:** `Martin-Sosa_2021_Pedal_IMU_StrainGauge.pdf`

---

## ลำดับการอ่านที่แนะนำ
1. **Blommaert 2025** — อ่านก่อน: เข้าใจ architecture ทั้งหมด + placement + circuit
2. **Analog Devices 2021** — อ่านต่อ: เจาะ circuit detail + part selection + power budget
3. **Martín-Sosa 2021** — อ่านสุดท้าย: แก้ปัญหา IMU drift ที่จะเจอตอน implement

## สิ่งที่ต้องทำก่อน implement
- [ ] โหลด Blommaert 2025 จาก HAL (ฟรี)
- [ ] พิมพ์ Analog Devices article บันทึกเป็น PDF
- [ ] โหลด Martín-Sosa 2021 จาก PMC (ฟรี)
- [ ] อ่านทั้ง 3 ก่อนซื้อ components

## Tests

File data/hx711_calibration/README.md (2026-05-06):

# HX711 Calibration Data

This folder is for exported HX711 calibration capture data.

## Folder Layout

```text
data/hx711_calibration/
  loading/
    m0/
      trial01/
      trial02/
      trial03/
    ...
    m4/
      trial01/
      trial02/
      trial03/
  unloading/
    m0/
      trial01/
      trial02/
      trial03/
    ...
    m4/
      trial01/
      trial02/
      trial03/
```

## Raw CSV

Each trial folder stores one exported capture CSV. The current calibration range
is 0-4 kg. Use `loading` while adding mass and `unloading` while removing mass.
The 5 kg point is intentionally skipped because the bicycle can move forward
without a person holding it.

For the current hysteresis experiment, `loading/m4` is the peak point and is
shared as the start of the unloading path. Separate `unloading/m4` captures are
not required; after reaching 4 kg, collect unloading data at `m3`, `m2`, `m1`,
and `m0`.

Columns:

```text
sample_idx,time_ms,raw,delta_raw,zero_raw
```

Copy or upload this CSV to Google Sheets when you are ready to analyze the
capture.

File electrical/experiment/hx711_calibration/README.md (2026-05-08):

# Interactive HX711 Capture Logger

This folder contains a simple interactive HX711 data capture flow for the
bicycle watt meter calibration work. Run Python once, then type commands such as
`loading m0 t1` or `unloading m3 trial02`; each command collects 100 valid HX711
samples and saves one raw CSV file.

This version can also show a live raw/delta_raw graph while the ESP32 streams
HX711 readings.

## Files

```text
hx711_calibration_logger.py
esp32_hx711_trial_collector/esp32_hx711_trial_collector.ino
```

The Arduino `.ino` file is inside a folder with the same name so Arduino IDE and
`arduino-cli` can compile it normally.

## ESP32 Firmware

Upload this sketch:

```text
esp32_hx711_trial_collector/esp32_hx711_trial_collector.ino
```

Hardware/config:

```text
HX711 DOUT = GPIO32
HX711 SCK  = GPIO33
HX711 gain = 64
Baud rate  = 115200
Samples    = 100
```

Serial commands:

```text
h   show help
s   show current tare/status
t   tare with no load
c   collect 100 valid ready samples
r1  start live raw report
r0  stop live raw report
```

The ESP32 output block is:

```text
BEGIN_TRIAL,zero_raw=-47264,samples=100
sample_idx,time_ms,raw,delta_raw
1,12345,-60401,-13137
2,12444,-60418,-13154
...
100,22210,-60690,-13426
END_TRIAL
```

The Python script ignores extra startup text before `BEGIN_TRIAL`.

Live monitor lines use:

```text
LIVE,time_ms,raw,delta_raw
```

## Python Setup

Install the only required Python dependency:

```powershell
pip install pyserial matplotlib
```

Edit these constants at the top of `hx711_calibration_logger.py` if needed:

```python
SERIAL_PORT = "COM3"
BAUD_RATE = 115200
PROJECT_ROOT = Path(__file__).resolve().parents[3]
DATA_ROOT = PROJECT_ROOT / "data" / "hx711_calibration"
DEFAULT_OUTPUT_FILENAME = "hx711_capture.csv"
VALID_GROUPS = {"loading", "unloading"}
MIN_MASS_KG = 0
MAX_MASS_KG = 4
SAMPLES_PER_CAPTURE = 100
MONITOR_WINDOW_SAMPLES = 200
```

Run:

```powershell
python hx711_calibration_logger.py
```

Flow:

1. Connect ESP32 over USB.
2. Run the Python script.
3. Remove load and press Enter to tare, or type `skip`.
4. Type a capture command.
5. The script collects 100 samples and saves the matching CSV.

Interactive commands:

```text
loading m0 t1          save to data/hx711_calibration/loading/m0/trial01/hx711_capture.csv
unloading m3 trial02   save to data/hx711_calibration/unloading/m3/trial02/hx711_capture.csv
l m4 t3 data.csv       loading shortcut, custom filename
u m2 t1                unloading shortcut
monitor / mon          open live raw/delta_raw graph
status / s             show current ESP32 tare status
tare              send tare command again
help              show commands
q                 quit
```

Current calibration range is `0-4 kg` (`m0` to `m4`). The 5 kg point is out of
scope for this setup because the bicycle can move forward without a person
holding it.

Recommended hysteresis sequence:

```text
loading:   m0 -> m1 -> m2 -> m3 -> m4
unloading:       m3 -> m2 -> m1 -> m0
```

The `m4` point is the shared peak from the loading sequence. It is not collected
again as `unloading m4` unless you intentionally want a duplicate peak capture.

If the live graph is open and you run a collect or tare command, Python stops
live reporting with `r0`, closes the graph, flushes the serial buffer, and then
runs the requested command.

Use `status` to check whether the ESP32 still has a tare value in RAM:

```text
STATUS,is_tared=1,zero_raw=-47264
```

## CSV Output

Default output:

```text
data/hx711_calibration/<loading-or-unloading>/m<mass>/trial<trial>/hx711_capture.csv
```

Columns:

```text
sample_idx,time_ms,raw,delta_raw,zero_raw
```

- `sample_idx`: sample number from 1 to 100.
- `time_ms`: ESP32 `millis()` timestamp for that sample.
- `raw`: raw HX711 ADC count.
- `delta_raw`: `raw - zero_raw`.
- `zero_raw`: tare baseline stored on the ESP32.

If the script receives fewer than 100 samples, it prints a warning but still
saves whatever data was received.

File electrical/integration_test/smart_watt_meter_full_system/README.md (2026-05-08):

# Smart Watt Meter Full-System Firmware

Firmware folder:

```text
electrical/integration_test/smart_watt_meter_full_system/
```

Sketch:

```text
smart_watt_meter_full_system.ino
```

This firmware is for the real full-system bench/field test:

- ESP32 Dev Module / NodeMCU-32S
- SH1106 OLED 128x64
- MPU6050
- HX711
- 4 active-high buttons
- passive buzzer
- BLE connection to the Flutter app

## Wiring Summary

```text
OLED + MPU6050 I2C:
  SDA = GPIO21
  SCL = GPIO22

HX711:
  DOUT = GPIO32
  SCK  = GPIO33
  gain = 64

Buttons, active-high with INPUT_PULLDOWN:
  BTN1 = GPIO25
  BTN2 = GPIO26
  BTN3 = GPIO27
  BTN4 = GPIO14

Buzzer:
  GPIO13
```

Button 5 / GPIO16 is not used.

## OLED Screens

Use `BTN1` and `BTN2` to move between screens.

```text
BTN1 = previous screen
BTN2 = next screen
```

Screens:

```text
LIVE    main ride display
SENSOR  IMU + HX711 status
HX      HX711 raw / force / tare page
BLE     app / notify / packet status
SYS     uptime, heap, calibration status
```

Every screen has a top bar:

```text
TITLE        BT GPS REC
```

- Bluetooth icon blinking/visible = BLE advertising or connected
- `GPS` = app reports phone GPS fix OK
- `REC` = app reports ride recording active

The app must write status to BLE characteristic:

```text
12345678-1234-1234-1234-123456789014
```

Example:

```json
{"type":"appStatus","gpsOk":true,"recording":true}
```

## Button Controls

```text
BTN1 short press:
  Previous OLED screen.

BTN2 short press:
  Next OLED screen.

BTN3 short press:
  Reserved / no operation.

BTN3 long press on SENSOR or SYS:
  Gyro bias calibration.
  Keep the crank/IMU still.

BTN4 long press on HX or SENSOR:
  HX711 tare.
  Remove all load first.

BTN4 long press on LIVE or SYS:
  Crank axis calibration.
  Spin crank steadily for about 10 seconds.
```

Long press is about 1.5 seconds.

## First-Time Bench Test Flow

Use this order after uploading the firmware.

### 1. Boot

Power on the ESP32. You should hear the startup tone and see a boot/self-check screen.

Expected:

```text
SELF CHECK
IMU OK
BLE ADV ON
```

If IMU says `NO`, check I2C wiring, power, and GND.

### 2. Check HX711 Raw

Go to the `HX` screen:

```text
BTN2 until HX screen appears
```

Before tare, the screen should show raw mode:

```text
HX        BT --- ---
NO TARE  c/N 852
RAW 242588
TARE NEEDED
Hold B4 tare
```

If `RAW` changes when you press/load the strain gauge, HX711 is being read.

Important: before tare, force in newtons is not shown yet. Raw value is the useful check.

### 3. Tare HX711

Remove all load from the strain gauge/crank.

On `HX` or `SENSOR` screen:

```text
Hold BTN4
```

Expected:

```text
TARE OK
```

After tare, `HX` screen should show force and delta raw:

```text
TARE OK  c/N 852
F 0.00N
dR 0
sample ... B4 tare
```

Apply load and check that `F` changes.

### 4. Gyro Bias Calibration

Keep crank/IMU still.

Go to `SENSOR` or `SYS` screen:

```text
Hold BTN3
```

Expected:

```text
BIAS OK
```

This removes stationary gyro offset.

### 5. Crank Axis Calibration

This step is optional. The firmware already starts with the crank unit vector
measured from experiment 3.2:

```text
ux = -0.074
uy =  0.995
uz =  0.065
```

If the MPU6050/crank mounting has not changed, you can skip this step.

Run this only when you want to refresh the crank axis for the current mounting.

Go to `LIVE` or `SYS` screen.

Spin the crank steadily in one direction.

```text
Hold BTN4
```

Keep spinning for about 10 seconds.

Expected:

```text
AXIS OK
```

This lets firmware estimate the real crank rotation axis from the current
MPU6050 mounting and replace the default vector above.

### 6. Connect the Flutter App

Open the app and connect to:

```text
ESP32_PowerMeter_01
```

On OLED `BLE` screen:

```text
APP CONN
NOTIFY ON
SEQ ...
CMD ...014
```

If the app sends status correctly, the top bar should show:

```text
GPS
REC
```

`GPS` appears only when the app reports phone GPS fix OK.

`REC` appears only when the app is recording and writes app status back to ESP32.

### 7. Start / Stop Ride

Start and stop ride recording from the phone app:

```text
Phone app Start Session
```

The ESP32 buttons do not start or stop recording. BTN1/BTN2 are reserved for
OLED page navigation so accidental button presses do not affect ride sessions.

## LIVE Screen Meaning

Before HX tare / gyro bias:

```text
LIVE       BT GPS ---
0 W
0rpm R242588
TQ 0.0Nm
HX RAW RAW
```

Meaning:

- HX711 raw is visible as `Rxxxxx`
- force/power is not trusted yet
- `RAW` means gyro bias has not been completed yet

After HX tare + gyro bias, using the default experiment 3.2 crank axis:

```text
LIVE       BT GPS REC
245 W
82rpm 34N
TQ 5.9Nm
HX OK AX DEF
```

Meaning:

- power is computed using the default experiment 3.2 unit vector
- crank axis calibration has not been refreshed in this boot session

After optional crank axis calibration:

```text
LIVE       BT GPS REC
245 W
82rpm 34N
TQ 5.9Nm
HX OK CAL
```

Meaning:

- power is computed from torque and angular velocity
- force is shown in newtons
- `CAL` means firmware is using a freshly calibrated crank axis from this boot session

## BLE Packets

Telemetry notify characteristic:

```text
12345678-1234-1234-1234-123456789013
```

Packet example:

```json
{"v":1,"type":"telemetry","seq":128,"tMs":128420,"powerW":245.3,"cadenceRpm":82.1,"forceN":34.20,"torqueNm":5.81,"omegaRadS":8.600,"hxRaw":29120,"hxTared":true,"imuOk":true,"hxOk":true,"calOk":true}
```

App status / command write characteristic:

```text
12345678-1234-1234-1234-123456789014
```

App status example:

```json
{"type":"appStatus","gpsOk":true,"recording":true}
```

Command examples:

```json
{"type":"command","cmd":"tare"}
{"type":"command","cmd":"gyroBias"}
{"type":"command","cmd":"axisCal"}
```

Event examples sent by ESP32:

```json
{"v":1,"type":"event","seq":46,"tMs":55400,"event":"tare_ok"}
{"v":1,"type":"event","seq":47,"tMs":55500,"event":"gyro_bias_ok"}
{"v":1,"type":"event","seq":48,"tMs":55600,"event":"axis_cal_ok"}
```

## Compile

Use ESP32 Dev Module:

```powershell
& 'C:\Users\Acer\AppData\Local\Programs\Arduino IDE\resources\app\lib\backend\resources\arduino-cli.exe' compile --fqbn esp32:esp32:esp32 .\electrical\integration_test\smart_watt_meter_full_system
```

## Troubleshooting

### HX711 raw sketch works, but full firmware looks like no value

Go to the `HX` screen first. Before tare, full firmware shows raw value, not force.

Expected before tare:

```text
NO TARE
RAW xxxxx
```

Expected after tare:

```text
TARE OK
F x.xxN
dR xxxxx
```

### OLED shows `HX WAIT`

Check:

- HX711 VCC/GND
- DOUT GPIO32
- SCK GPIO33
- gain set to 64
- common ground with ESP32

### OLED does not show `GPS` or `REC`

This requires the phone app to write app status to characteristic `...014`.

Check app BLE logs for:

```text
sendAppStatus
```

### LIVE shows `RAW` or `AX DEF`

Run the common quick setup first:

```text
1. HX tare:       hold BTN4 on HX/SENSOR
2. Gyro bias:     hold BTN3 on SENSOR/SYS while still
```

If LIVE shows `AX DEF`, it is using the default experiment 3.2 crank axis:

```text
ux = -0.074, uy = 0.995, uz = 0.065
```

This is acceptable if the IMU/crank mounting has not changed.

Optional precision step:

```text
3. Axis cal:      hold BTN4 on LIVE/SYS while spinning crank
```

After that, LIVE should show `CAL` instead of `AX DEF`.

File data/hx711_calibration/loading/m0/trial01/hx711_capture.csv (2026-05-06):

sample_idx | time_ms | raw | delta_raw | zero_raw
1 | 159696 | 242432 | -156 | 242588
2 | 159745 | 242420 | -168 | 242588
3 | 159834 | 242446 | -142 | 242588
4 | 159924 | 242414 | -174 | 242588
5 | 160013 | 242386 | -202 | 242588
6 | 160103 | 242407 | -181 | 242588
7 | 160193 | 242411 | -177 | 242588
8 | 160282 | 242373 | -215 | 242588
9 | 160372 | 242363 | -225 | 242588
10 | 160462 | 242350 | -238 | 242588
11 | 160551 | 242337 | -251 | 242588
12 | 160641 | 242318 | -270 | 242588
13 | 160731 | 242283 | -305 | 242588
14 | 160820 | 242252 | -336 | 242588
15 | 160910 | 242195 | -393 | 242588
16 | 161000 | 242135 | -453 | 242588
17 | 161089 | 242117 | -471 | 242588
18 | 161179 | 242143 | -445 | 242588
19 | 161269 | 242150 | -438 | 242588
20 | 161358 | 242116 | -472 | 242588
21 | 161448 | 242091 | -497 | 242588
22 | 161537 | 242066 | -522 | 242588
23 | 161627 | 242084 | -504 | 242588
24 | 161717 | 242064 | -524 | 242588
25 | 161806 | 242055 | -533 | 242588
26 | 161896 | 242057 | -531 | 242588
27 | 161986 | 242066 | -522 | 242588
28 | 162075 | 242076 | -512 | 242588
29 | 162165 | 242041 | -547 | 242588
30 | 162255 | 242059 | -529 | 242588
31 | 162344 | 242084 | -504 | 242588
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

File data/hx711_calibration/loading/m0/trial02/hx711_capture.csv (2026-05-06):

sample_idx | time_ms | raw | delta_raw | zero_raw
1 | 393400 | 239195 | -3393 | 242588
2 | 393466 | 239215 | -3373 | 242588
3 | 393556 | 239193 | -3395 | 242588
4 | 393646 | 239148 | -3440 | 242588
5 | 393735 | 239096 | -3492 | 242588
6 | 393825 | 239129 | -3459 | 242588
7 | 393915 | 239158 | -3430 | 242588
8 | 394004 | 239173 | -3415 | 242588
9 | 394094 | 239209 | -3379 | 242588
10 | 394184 | 239204 | -3384 | 242588
11 | 394273 | 239229 | -3359 | 242588
12 | 394363 | 239230 | -3358 | 242588
13 | 394453 | 239203 | -3385 | 242588
14 | 394542 | 239261 | -3327 | 242588
15 | 394632 | 239224 | -3364 | 242588
16 | 394722 | 239210 | -3378 | 242588
17 | 394811 | 239228 | -3360 | 242588
18 | 394901 | 239218 | -3370 | 242588
19 | 394991 | 239208 | -3380 | 242588
20 | 395080 | 239208 | -3380 | 242588
21 | 395170 | 239226 | -3362 | 242588
22 | 395260 | 239196 | -3392 | 242588
23 | 395349 | 239243 | -3345 | 242588
24 | 395439 | 239212 | -3376 | 242588
25 | 395529 | 239241 | -3347 | 242588
26 | 395618 | 239272 | -3316 | 242588
27 | 395708 | 239289 | -3299 | 242588
28 | 395798 | 239292 | -3296 | 242588
29 | 395887 | 239334 | -3254 | 242588
30 | 395977 | 239339 | -3249 | 242588
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

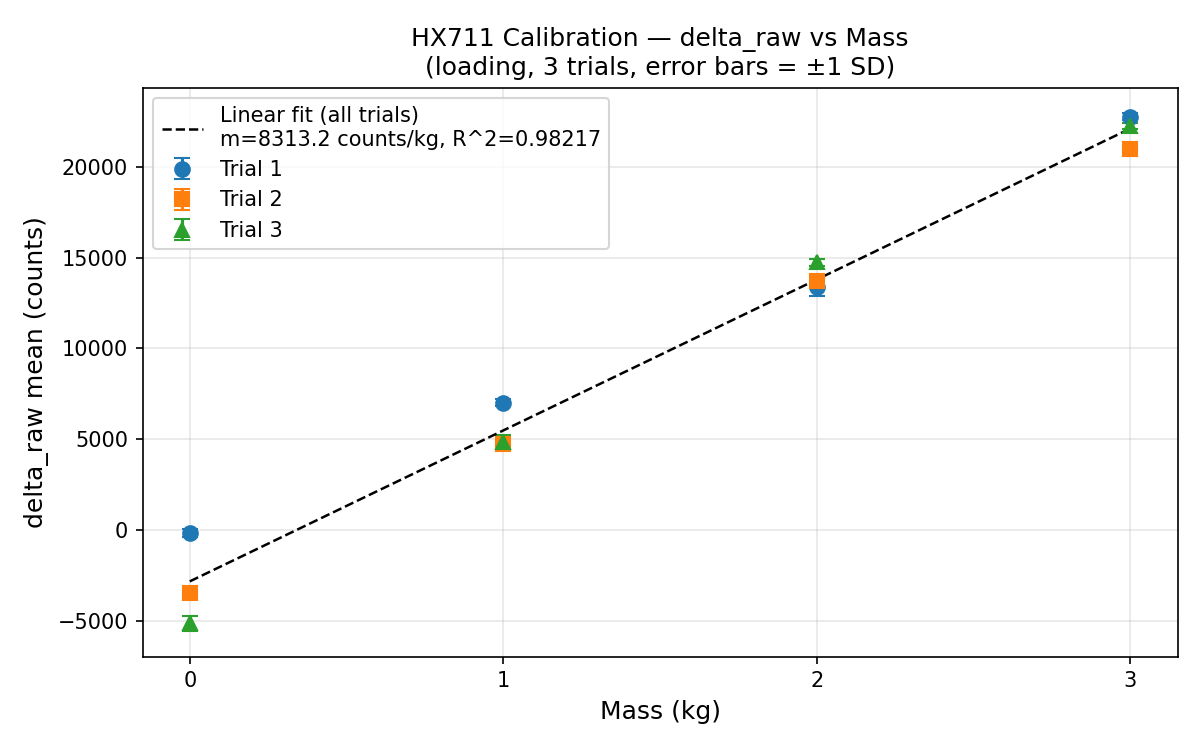
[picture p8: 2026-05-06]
images/hx711_calibration_curve.png

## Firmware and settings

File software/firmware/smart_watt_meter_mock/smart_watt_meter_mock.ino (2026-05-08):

/*
 * smart_watt_meter_mock.ino
 * ESP32 Mock Firmware — Smart Watt-Meter (FRA503)
 *
 * Simulates strain gauge + MPU6050 readings and sends telemetry
 * to the Flutter app via BLE GATT notifications at 1 Hz.
 *
 * BLE Service UUID  : 12345678-1234-1234-1234-123456789012
 * Telemetry Char UUID: 12345678-1234-1234-1234-123456789013
 * Packet format (JSON): {"power":245,"cadence":85,"speed":28.5,"elapsedSec":42}
 *
 * Flash target: ESP32 (any variant)
 * Arduino IDE board: "ESP32 Dev Module"
 * Baud: 115200
 */

#include <BLEDevice.h>
#include <BLEServer.h>
#include <BLEUtils.h>
#include <BLE2902.h>
#include <math.h>

// ── BLE identifiers ───────────────────────────────────────────
#define DEVICE_NAME          "ESP32_PowerMeter_01"
#define SERVICE_UUID         "12345678-1234-1234-1234-123456789012"
#define TELEMETRY_CHAR_UUID  "12345678-1234-1234-1234-123456789013"

// ── Timing ───────────────────────────────────────────────────
#define NOTIFY_INTERVAL_MS   1000   // 1 Hz telemetry

// ── Globals ──────────────────────────────────────────────────
BLEServer*          pServer        = nullptr;
BLECharacteristic*  pTelemetryChar = nullptr;
BLE2902*            pTelemetry2902 = nullptr;
bool deviceConnected    = false;
bool oldDeviceConnected = false;
uint32_t elapsedSec     = 0;
unsigned long lastNotifyMs = 0;
unsigned long lastConnectionDebugMs = 0;
unsigned long notifyDisabledSinceMs = 0;

bool hasActiveClient() {
  return pServer != nullptr && pServer->getConnectedCount() > 0;
}

bool notificationsEnabled() {
  return pTelemetry2902 != nullptr && pTelemetry2902->getNotifications();
}

// ── BLE connection callbacks ──────────────────────────────────
class ServerCallbacks : public BLEServerCallbacks {
  void onConnect(BLEServer* pServer) override {
    deviceConnected = true;
    elapsedSec = 0;
    Serial.println("[BLE] Client connected — session timer reset");
  }
  void onDisconnect(BLEServer* pServer) override {
    deviceConnected = false;
    Serial.println("[BLE] Client disconnected");
  }
};

// ── Mock sensor data ──────────────────────────────────────────
// Mimics a real cycling session: sinusoidal power base + random noise.
// Formula mirrors actual firmware: P = torque × angular_velocity
//   torque      → strain gauge (HX711) reading
//   ang_velocity→ MPU6050 gyroscope Z-axis
// For mock: both are approximated by a sine wave.

int mockPower() {
  // 180 W base, ±60 W sine (30 s period), ±20 W noise
  float base  = 180.0f + 60.0f * sinf((float)elapsedSec * 2.0f * M_PI / 30.0f);
  float noise = (float)(random(-20, 21));
  return (int)max(30.0f, base + noise);
}

int mockCadence() {
  // 82 RPM base ± 5 RPM
  return 82 + random(-5, 6);
}

float mockSpeed() {
  // 28.0 km/h ± 2.0 km/h
  return 28.0f + (float)random(-20, 21) / 10.0f;
}

// ── Setup ─────────────────────────────────────────────────────
void setup() {
  Serial.begin(115200);
  Serial.println();
  Serial.println("=== Smart Watt-Meter Mock Firmware ===");

  randomSeed(analogRead(0));

  BLEDevice::init(DEVICE_NAME);

  pServer = BLEDevice::createServer();
  pServer->setCallbacks(new ServerCallbacks());

  BLEService* pService = pServer->createService(SERVICE_UUID);

  pTelemetryChar = pService->createCharacteristic(
    TELEMETRY_CHAR_UUID,
    BLECharacteristic::PROPERTY_READ | BLECharacteristic::PROPERTY_NOTIFY
  );
  pTelemetry2902 = new BLE2902();
  pTelemetryChar->addDescriptor(pTelemetry2902);

  pService->start();

  BLEAdvertising* pAdv = BLEDevice::getAdvertising();
  pAdv->addServiceUUID(SERVICE_UUID);
  pAdv->setScanResponse(true);
  pAdv->setMinPreferred(0x06);
  BLEDevice::startAdvertising();

  Serial.printf("[BLE] Advertising as \"%s\"\n", DEVICE_NAME);
  Serial.println("[BLE] Waiting for Flutter app to connect...");
}

// ── Loop ──────────────────────────────────────────────────────
void loop() {
  unsigned long now = millis();
  deviceConnected = hasActiveClient();
  bool notifyEnabled = notificationsEnabled();

  if (deviceConnected && !notifyEnabled) {
    if (notifyDisabledSinceMs == 0) {
      notifyDisabledSinceMs = now;
      Serial.printf(
        "[BLE] Notifications disabled while connected; connId=%u count=%lu\n",
        pServer->getConnId(),
        (unsigned long)pServer->getConnectedCount()
      );
    } else if (now - notifyDisabledSinceMs >= 2000) {
      Serial.printf(
        "[BLE] Forcing disconnect of stale client; connId=%u count=%lu\n",
        pServer->getConnId(),
        (unsigned long)pServer->getConnectedCount()
      );
      pServer->disconnect(pServer->getConnId());
      notifyDisabledSinceMs = now;
    }
  } else {
    notifyDisabledSinceMs = 0;
  }

  if (deviceConnected && (now - lastConnectionDebugMs >= 5000)) {
    lastConnectionDebugMs = now;
    Serial.printf(
      "[DBG] still connected, connectedCount=%lu notify=%s elapsedSec=%lu\n",
      (unsigned long)pServer->getConnectedCount(),
      notifyEnabled ? "on" : "off",
      (unsigned long)elapsedSec
    );
  }

  if (deviceConnected && notifyEnabled && (now - lastNotifyMs >= NOTIFY_INTERVAL_MS)) {
    lastNotifyMs = now;

    int   power   = mockPower();
    int   cadence = mockCadence();
    float speed   = mockSpeed();

    // JSON packet — must match the Flutter parser exactly
    char packet[128];
    snprintf(packet, sizeof(packet),
      "{\"power\":%d,\"cadence\":%d,\"speed\":%.1f,\"elapsedSec\":%lu}",
      power, cadence, speed, (unsigned long)elapsedSec
    );

    pTelemetryChar->setValue((uint8_t*)packet, strlen(packet));
    pTelemetryChar->notify();

    Serial.printf("[TX] %s\n", packet);
    elapsedSec++;
  }

  // Handle disconnect → restart advertising
  if (!deviceConnected && oldDeviceConnected) {
    Serial.printf("[BLE] Connected count = %lu\n", (unsigned long)pServer->getConnectedCount());
    delay(500);
    pServer->startAdvertising();
    Serial.println("[BLE] Restarting advertising...");
    oldDeviceConnected = false;
    lastConnectionDebugMs = 0;
  }

  if (deviceConnected && !oldDeviceConnected) {
    Serial.printf("[BLE] Connected count = %lu\n", (unsigned long)pServer->getConnectedCount());
    oldDeviceConnected = true;
    lastConnectionDebugMs = 0;
  }
}

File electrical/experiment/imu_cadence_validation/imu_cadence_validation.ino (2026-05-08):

// Experiment 3.2 firmware: IMU gyroscope cadence validation.
//
// Purpose:
//   Standalone OLED-guided workflow for measuring crank cadence from an
//   MPU6050 gyroscope without keeping USB serial connected while the crank
//   is spinning.
//
// Hardware:
//   ESP32 Dev Module / NodeMCU-32S
//   Shared I2C: SDA GPIO21, SCL GPIO22
//   OLED SH1106 1.3 inch I2C: address 0x3C
//   MPU6050: address 0x68 or 0x69
//   Passive buzzer: GPIO13
//   Active-high buttons with INPUT_PULLDOWN:
//     BTN1 GPIO25: START / RETRY
//     BTN2 GPIO26: NEXT
//     BTN3 GPIO27: previous trial
//     BTN4 GPIO14: next trial

#include <Wire.h>
#include <Adafruit_GFX.h>
#include <Adafruit_SH110X.h>
#include <math.h>

enum AppState {
  STATE_BIAS_IDLE,
  STATE_BIAS_RUNNING,
  STATE_BIAS_RESULT,
  STATE_AXIS_IDLE,
  STATE_AXIS_RUNNING,
  STATE_AXIS_RESULT,
  STATE_TRIAL_IDLE,
  STATE_TRIAL_RUNNING,
  STATE_TRIAL_RESULT
};

struct GyroDps {
  float x;
  float y;
  float z;
};

struct ButtonInput {
  const char *name;
  uint8_t pin;
  unsigned int toneHz;
  bool stablePressed;
  bool lastRawPressed;
  unsigned long lastRawChangeMs;
};

const uint8_t I2C_SDA_PIN = 21;
const uint8_t I2C_SCL_PIN = 22;
const uint8_t BUZZER_PIN = 13;

const uint8_t OLED_I2C_ADDRESS = 0x3C;
const int SCREEN_WIDTH = 128;
const int SCREEN_HEIGHT = 64;
const int OLED_RESET_PIN = -1;

const uint8_t MPU6050_ADDR_LOW = 0x68;
const uint8_t MPU6050_ADDR_HIGH = 0x69;

const uint8_t REG_SMPLRT_DIV = 0x19;
const uint8_t REG_CONFIG = 0x1A;
const uint8_t REG_GYRO_CONFIG = 0x1B;
const uint8_t REG_ACCEL_CONFIG = 0x1C;
const uint8_t REG_ACCEL_XOUT_H = 0x3B;
const uint8_t REG_PWR_MGMT_1 = 0x6B;
const uint8_t REG_WHO_AM_I = 0x75;

const uint8_t BUTTON_PIN_MODE = INPUT_PULLDOWN;
const uint8_t BUTTON_PRESSED_LEVEL = HIGH;
const unsigned long DEBOUNCE_MS = 35;
const unsigned long DISPLAY_INTERVAL_MS = 200;
const unsigned long SAMPLE_INTERVAL_MS = 20;     // 50 Hz
const unsigned long BIAS_DURATION_MS = 5000;     // 5 s
const unsigned long AXIS_DURATION_MS = 10000;    // 10 s
const unsigned long TRIAL_DURATION_MS = 10000;   // 10 s
const float AXIS_MIN_OMEGA_DPS = 30.0;
const uint16_t AXIS_MIN_VALID_SAMPLES = 350;
const float GYRO_LSB_PER_DPS = 16.4;             // MPU6050 +/-2000 dps

Adafruit_SH1106G display(SCREEN_WIDTH, SCREEN_HEIGHT, &Wire, OLED_RESET_PIN);

ButtonInput buttons[] = {
  {"BTN1", 25, 659, false, false, 0},
  {"BTN2", 26, 784, false, false, 0},
  {"BTN3", 27, 988, false, false, 0},
  {"BTN4", 14, 1319, false, false, 0},
};
const uint8_t BUTTON_COUNT = sizeof(buttons) / sizeof(buttons[0]);

AppState state = STATE_BIAS_IDLE;
uint8_t mpuAddress = 0;
bool oledOk = false;
bool mpuOk = false;
bool biasReady = false;
bool axisReady = false;

GyroDps gyro = {0.0, 0.0, 0.0};
GyroDps bias = {0.0, 0.0, 0.0};
GyroDps uCrank = {0.0, 0.0, 0.0};

unsigned long stateStartMs = 0;
unsigned long lastSampleMs = 0;
unsigned long lastDisplayMs = 0;
unsigned long buzzerOffAtMs = 0;

double sumX = 0.0;
double sumY = 0.0;
double sumZ = 0.0;
uint32_t sampleCount = 0;
uint32_t validSampleCount = 0;
float axisNorm = 0.0;
bool axisQualityGood = false;

uint16_t trialNumber = 1;
double rpmSum = 0.0;
float rpmAvg = 0.0;
float rpmLive = 0.0;
float rpmMin = 99999.0;
float rpmMax = 0.0;
uint32_t trialSampleCount = 0;

bool i2cDevicePresent(uint8_t address) {
  Wire.beginTransmission(address);
  return Wire.endTransmission() == 0;
}

bool writeRegister(uint8_t address, uint8_t reg, uint8_t value) {
  Wire.beginTransmission(address);
  Wire.write(reg);
  Wire.write(value);
  return Wire.endTransmission() == 0;
}

bool readRegisters(uint8_t address, uint8_t startReg, uint8_t *buffer, uint8_t length) {
  Wire.beginTransmission(address);
  Wire.write(startReg);
  if (Wire.endTransmission(false) != 0) {
    return false;
  }

  const uint8_t received = Wire.requestFrom(address, length);
  if (received != length) {
    return false;
  }

  for (uint8_t i = 0; i < length; i++) {
    buffer[i] = Wire.read();
  }

  return true;
}

bool readRegister(uint8_t address, uint8_t reg, uint8_t &value) {
  return readRegisters(address, reg, &value, 1);
}

int16_t combineInt16(uint8_t highByte, uint8_t lowByte) {
  return (int16_t)((highByte << 8) | lowByte);
}

uint8_t detectMpuAddress() {
  if (i2cDevicePresent(MPU6050_ADDR_LOW)) {
    return MPU6050_ADDR_LOW;
  }
  if (i2cDevicePresent(MPU6050_ADDR_HIGH)) {
    return MPU6050_ADDR_HIGH;
  }
  return 0;
}

bool initializeMpu6050() {
  mpuAddress = detectMpuAddress();
  if (mpuAddress == 0) {
    Serial.println("MPU6050 not found at 0x68 or 0x69");
    return false;
  }

  uint8_t whoAmI = 0;
  if (!readRegister(mpuAddress, REG_WHO_AM_I, whoAmI)) {
    Serial.println("Failed to read WHO_AM_I");
    return false;
  }

  if (!writeRegister(mpuAddress, REG_PWR_MGMT_1, 0x01)) {
    return false;
  }
  delay(100);

  writeRegister(mpuAddress, REG_SMPLRT_DIV, 0x13);   // 1 kHz / (19 + 1) = 50 Hz
  writeRegister(mpuAddress, REG_CONFIG, 0x03);       // DLPF around 44 Hz
  writeRegister(mpuAddress, REG_GYRO_CONFIG, 0x18);  // +/-2000 deg/s
  writeRegister(mpuAddress, REG_ACCEL_CONFIG, 0x00);

  Serial.print("MPU6050 initialized at 0x");
  Serial.println(mpuAddress, HEX);
  Serial.print("WHO_AM_I=0x");
  Serial.println(whoAmI, HEX);
  return true;
}

bool readGyroDps(GyroDps &out) {
  uint8_t data[14];
  if (!readRegisters(mpuAddress, REG_ACCEL_XOUT_H, data, sizeof(data))) {
    return false;
  }

  const int16_t rawGx = combineInt16(data[8], data[9]);
  const int16_t rawGy = combineInt16(data[10], data[11]);
  const int16_t rawGz = combineInt16(data[12], data[13]);

  out.x = rawGx / GYRO_LSB_PER_DPS;
  out.y = rawGy / GYRO_LSB_PER_DPS;
  out.z = rawGz / GYRO_LSB_PER_DPS;
  return true;
}

float magnitude3(float x, float y, float z) {
  return sqrt((x * x) + (y * y) + (z * z));
}

void resetAccumulator() {
  sumX = 0.0;
  sumY = 0.0;
  sumZ = 0.0;
  sampleCount = 0;
  validSampleCount = 0;
}

void resetTrial() {
  rpmSum = 0.0;
  rpmAvg = 0.0;
  rpmLive = 0.0;
  rpmMin = 99999.0;
  rpmMax = 0.0;
  trialSampleCount = 0;
}

void enterState(AppState newState) {
  state = newState;
  stateStartMs = millis();
  lastSampleMs = 0;

  if (newState == STATE_BIAS_RUNNING || newState == STATE_AXIS_RUNNING) {
    resetAccumulator();
  }
  if (newState == STATE_TRIAL_RUNNING) {
    resetTrial();
  }
}

void playTone(unsigned int frequency, unsigned long durationMs) {
  tone(BUZZER_PIN, frequency, durationMs);
  buzzerOffAtMs = millis() + durationMs + 5;
}

void playSuccessTone() {
  tone(BUZZER_PIN, 988, 80);
  delay(100);
  tone(BUZZER_PIN, 1319, 120);
  buzzerOffAtMs = millis() + 130;
}

void playErrorTone() {
  tone(BUZZER_PIN, 220, 180);
  buzzerOffAtMs = millis() + 190;
}

void updateBuzzer() {
  if (buzzerOffAtMs != 0 && millis() >= buzzerOffAtMs) {
    noTone(BUZZER_PIN);
    digitalWrite(BUZZER_PIN, LOW);
    buzzerOffAtMs = 0;
  }
}

bool readPressed(uint8_t pin) {
  return digitalRead(pin) == BUTTON_PRESSED_LEVEL;
}
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

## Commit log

2026-05-06 Initial project import
    [crank_power_meter_price_data.csv, hx711_capture.csv, watt-meter-circuit.kicad_pcb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]
2026-05-06 Update IMU cadence validation experiment plan
